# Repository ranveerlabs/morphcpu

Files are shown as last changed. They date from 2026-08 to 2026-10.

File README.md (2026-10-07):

# MorphCPU

just came across a cool analogy that like its pretty similar to how a cafe functions kinda, so i renamed the registers to stuff according to that. i feel like i did a good job haha

anyways MorphCPU is a small processor built from 16 configurable cells on an iCE40UP5K.
The FPGA is on the back of a 70 mm round board, with 16 red LEDs on the front.
Send it 9 bytes over USB and the grid changes what it computes.

MorphCPU board front

MorphCPU schematic

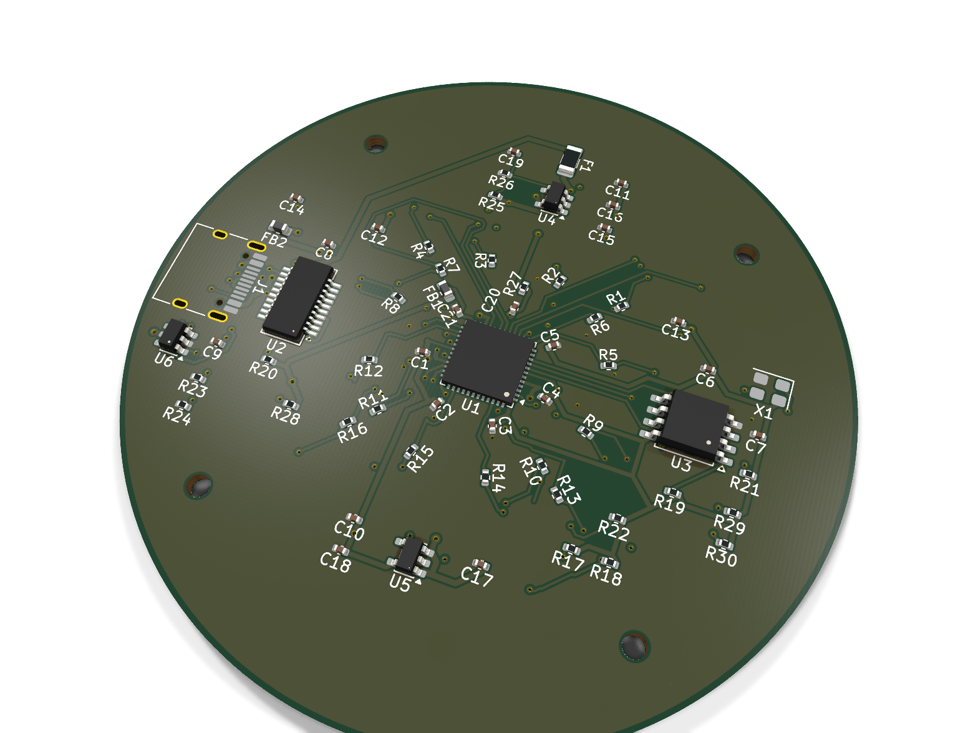
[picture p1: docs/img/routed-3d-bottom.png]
Routed FPGA-side 3D model


If you've poked at a systolic array before, it's close to that. 16 cells, each with an op and a direction. Data walks in from the west and leaves at the east edge over UART. One tick moves it one cell.

It's Verilog for the iCE40UP5K. Python tooling generates the schematic and board layout. Yosys and nextpnr do synthesis and place-and-route.

## why

On a conventional processor, most of the datapath is fixed. Here I can configure 16 cells with an op and a direction, so the values take different routes. I run it at 4 Hz. Four cells takes about a second. At 16 MHz there's nothing to look at.

## the grid

Each cell has a 4-bit configuration: a 2-bit operation and a 2-bit output direction. The four operations are pass, invert, 8-bit add, and XOR. Cells can route north, east, south, or west; inputs that meet at a cell can be combined.

```text
        c0    c1    c2    c3
      +-----+-----+-----+-----+
  r0  |  0  |  1  |  2  |  3  |  -> out
      +-----+-----+-----+-----+
  r1  |  4  |  5  |  6  |  7  |  -> out
      +-----+-----+-----+-----+
  r2  |  8  |  9  | 10  | 11  |  -> out
      +-----+-----+-----+-----+
  r3  | 12  | 13  | 14  | 15  |  -> out
      +-----+-----+-----+-----+
         ^
      data in
```

## a tiny example

Set cell 0 to pass south, cell 4 to add and point east, then cells 5-7 to pass east. Inject 200 on row 0 and 100 on row 1. After stepping through the grid, the UART returns `0x2C`: 300 truncated to 8 bits. The full byte sequence and timing are in the [gateware guide](gateware/README.md#worked-example-add-two-numbers-while-they-travel).

## build and test

You need Icarus Verilog for simulation and OSS CAD Suite for the FPGA bitstream.

```sh
bash gateware/sim/run_sims.sh
bash gateware/build.sh
bash case/export.sh
```

The simulation has 18 passing checks. GitHub Actions also runs the simulations and gateware build on changes; see the [workflow](https://github.com/ranveerlabs/morphcpu/actions/workflows/gateware.yml).

## status

The 4-layer PCB is routed: KiCad reports no violations or unconnected items. The latest recorded bitstream build used 2,020 of 5,280 logic cells and routed at 37.33 MHz against a 16 MHz clock. That build predates two pin-map changes, and the board has not been flashed yet, so those timing numbers are not verification of the current layout. Routing details and pin changes are in [hardware/ROUTING.md](hardware/ROUTING.md).

Routed back of the PCB

The board is 70 mm across with a 4×4 LED grid. The case is printable without supports. More board images are in [`docs/img`](docs/img/README.md); the [23-row BOM table](docs/BOM.md#the-parts) and [BOM CSV](hardware/fab_output/morphcpu-bom.csv) list the parts and quantities.

## license

[CERN-OHL-S-2.0](LICENSE). Third-party files retain their own licenses.

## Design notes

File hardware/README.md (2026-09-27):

# hardware/

KiCad project for the 4-layer board. It is placed and routed.

Start with [DESIGN.md](DESIGN.md), then see [ROUTING.md](ROUTING.md) for the
routing details.

| | |
|---|---|
| `morphcpu.kicad_sch` | generated. ERC 0/0 |
| `morphcpu.kicad_pcb` | 80 components + 4 mounting holes, 546 tracks, 193 vias |
| `morphcpu.kicad_dru` | JLC rules Board Setup cant express |
| [scripts/](scripts/) | generators |
| `fab_output/` | gerbers drill BOM CPL zip |

The latest DRC run had 0 violations, 0 unconnected items and 0 schematic
mismatches. LED1 uses FPGA pin 45 and LED2 uses pin 42. The schematic, source
netlist and PCF all agree.

`fab_output/` was generated from the routed board, with copper on all four
layers. The updated pin map still needs a bitstream build. See
[ROUTING.md](ROUTING.md).

## board

The board is round, 70 mm across, with four layers. Four M2 holes sit on a 29 mm
radius at 45, 135, 225 and 315 degrees. The case uses the same positions in
[../case/morphcpu_case.scad](../case/morphcpu_case.scad)

I started at 60 mm, but that didnt leave enough room. There are 79 footprints,
including a QFN-48, SSOP-20, SOIC-8 and edge-mounted USB-C, all packed around the
resistor ring.

## before you touch it

1. There are two regulators. The UP5K needs 1.2 V core and 3.3 V I/O.
2. The 1.2 V rail has to come up before 3.3 V. Both regulators run from 5 V in
   parallel, and an RC delay holds 3.3 V off. That means the 3.3 V regulator
   needs an enable pin, so the AMS1117 doesnt work here.
3. The clock comes from an active oscillator. The iCE40 has no crystal amplifier,
   and the SG48 has no XIN/XOUT pins.

citations in [DESIGN.md](DESIGN.md)

## regenerating

Dont hand-edit `.kicad_sch` or the placement. Regenerating replaces them, though
the routed tracks are kept. The commands are in [scripts/](scripts/).

tracked: `*.kicad_pro` `*.kicad_sch` `*.kicad_pcb` `*.kicad_sym` `*.kicad_mod`
`*.kicad_dru` the fab zip the two CSVs. rest regenerates, see
[../.gitignore](../.gitignore)

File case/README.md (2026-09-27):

# case/

An open-face frame in parametric OpenSCAD. The board sits on four posts and
screws down. There is no lid or cover over the LEDs.

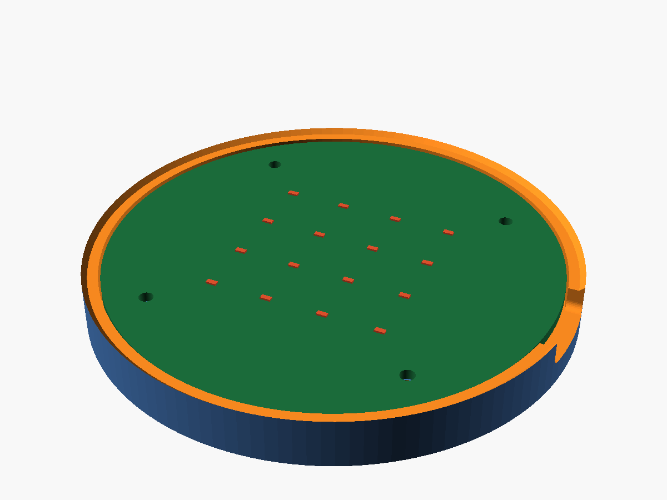
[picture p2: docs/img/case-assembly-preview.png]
case with a mock board in it


It is 75.4 mm across, 7.8 mm tall, with 2.4 mm walls and 3 mm under the board
for back-side parts. The 75.4 mm comes from a 70 mm board, 0.3 mm fit clearance
on each side and the two walls, so it changes if any of those dimensions do.

```sh
./export.sh
OPENSCAD="/c/Program Files/OpenSCAD (Nightly)/openscad.com" ./export.sh   # not on PATH
```

variants without exporting:

```sh
openscad -D 'part="assembly"' morphcpu_case.scad
openscad -D 'part="frame"'    morphcpu_case.scad
openscad -D 'part="pcb"'      morphcpu_case.scad
```

## board dimensions

The PCB hasnt been made yet, so these are assumptions, not measurements.

| param | assumed | comes from |
|---|---|---|
| `pcb_dia` | 70.0 mm | final board outline |
| `pcb_thickness` | 1.6 mm | JLCPCB default stackup |
| `mount_hole_r` | 29.0 mm | bolt circle |
| `mount_hole_count` | 4 | layout |
| `mount_hole_angle_offset` | 45 deg | layout |
| `usb_angle` | 0 deg (+X edge) | where the connector ends up |
| `usb_z_centre` | 1.2 mm above board top | connector datasheet + placement |

Update those seven values after routing, then run `export.sh` again.

## STEP

OpenSCAD wont do it. the CLI does `stl, off, wrl, amf, 3mf, csg, dxf, svg, pdf,
png` and thats the lot, its a mesh modeller and STEP is B-rep

`morphcpu_case.step` is the 3MF pushed thru FreeCAD 1.1.3, `Mesh.insert` then
`makeShapeFromMesh` with sewing then `Part.export`. it comes out a closed solid,
75.4 x 75.4 x 7.8mm, 11627.5mm3, 2621 faces. tessellated though, those faces are
mesh triangles welded up and not real cylinders. fine for a fit check, rebuild it
in Part Design or CadQuery if you need a proper one

## printing

no supports, flat on its back, 0.2mm layers, 3 perimeters. PLA unless it lives
somewhere warm

export prints genus 12 every time, four screw holes and eight vents. a
different number after a param change means two features started intersecting

`fit_clearance` is 0.3mm. print a test ring first, mine came out tight

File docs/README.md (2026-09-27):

# docs/

[BOM.md](BOM.md) lists the parts and cost for five boards. All 23 rows have an
LCSC part number. [img/](img/) has the renders and screenshots.

The machine-readable BOM and CPL are in
[../hardware/fab_output/](../hardware/fab_output/). `gen_fab.py` exports those
along with the Gerbers, all from the board file.

## datasheets

- [iCE40 UltraPlus, FPGA-DS-02008](https://www.latticesemi.com/-/media/LatticeSemi/Documents/DataSheets/iCE/iCE40-UltraPlus-Family-Data-Sheet.ashx) - pin summary p.45, Table 4.2 p.29, Table 4.13 p.34, power-up 4.5 p.31
- iCE40 Programming and Configuration, FPGA-TN-02001
- FTDI FT231X
- [W25Q32JV](https://www.winbond.com/hq/product/code-storage-flash-memory/serial-nor-flash/?__locale=en)
- USB-C mech drawing and the Type-C spec for the CC pulldowns. 5.1k each never shared
- [JLCPCB parts](https://jlcpcb.com/parts) - tier listings. part pages render the badge in JS

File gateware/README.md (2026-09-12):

# gateware/

Verilog, targets iCE40UP5K-SG48

| | |
|---|---|
| [rtl/morph_cell.v](rtl/morph_cell.v) | one cell: config register, 4-op ALU, routing |
| [rtl/grid.v](rtl/grid.v) | the 4x4 fabric and the neighbour interconnect |
| [rtl/uart_rx.v](rtl/uart_rx.v) | 8N1 receiver, synchronised, checks the stop bit |
| [rtl/uart_tx.v](rtl/uart_tx.v) | 8N1 transmitter |
| [rtl/config_loader.v](rtl/config_loader.v) | command decoder, config shifter, tick generator |
| [rtl/morphcpu_top.v](rtl/morphcpu_top.v) | top level: clock, reset, UART, LEDs |
| [morphcpu.pcf](morphcpu.pcf) | pin constraints |
| [build.sh](build.sh) | yosys -> nextpnr -> icepack |
| [sim/](sim/) | testbenches |

its `morph_cell` not `cell` cuz `cell` is reserved in Verilog-2001, it belongs
to the `config`/`design` construct. iverilog does not tell you this nicely

## cells

4 config bits, an op and a direction

| `op` | Operation | Result |
|---|---|---|
| `0` | PASS | `a` |
| `1` | INV | `~a` |
| `2` | ADD | `a + b` (8-bit, wraps) |
| `3` | XOR | `a ^ b` |

| `dir` | Sends its result |
|---|---|
| `0` | north |
| `1` | east |
| `2` | south |
| `3` | west |

inputs get scanned in a fixed priority order, N then E then S then W. first
valid one is `a`, second valid one is `b`. only one input showed up, `b` falls
back to whatever the cell is already holding

so two streams converging on a cell get combined and a lone stream walking thru
an ADD cell accumulates against itself

one `tick` moves data exactly one cell, so a value takes as many ticks as there
are cells on its path

## grid and edges

```
        c0    c1    c2    c3
      +-----+-----+-----+-----+
  r0  |  0  |  1  |  2  |  3  |  -> east_out[0]
      +-----+-----+-----+-----+
  r1  |  4  |  5  |  6  |  7  |  -> east_out[1]
      +-----+-----+-----+-----+
  r2  |  8  |  9  | 10  | 11  |  -> east_out[2]
      +-----+-----+-----+-----+
  r3  | 12  | 13  | 14  | 15  |  -> east_out[3]
      +-----+-----+-----+-----+
         ^
     west_in[r] injects into column 0
```

anything routed off the north, south or west edges is dropped. anything going
east out of column 3 leaves the fabric and goes back to the host over UART.
`led[i]` follows cell `i`

## host protocol

8N1 UART, 115200 baud, thru the FT231X. one command byte then a fixed number of
argument bytes

| Cmd | Name | Args | Effect |
|---|---|---|---|
| `0x01` | CONFIG | 8 | load the whole topology, packing below |
| `0x02` | INJECT | 2 | `[row, value]`, presents `value` at the west edge of `row` until the next tick |
| `0x03` | TICKDIV | 3 | 24-bit big-endian tick divider. `<=1` runs at full clock rate |
| `0x04` | CLEAR | 0 | drop all in-flight data, config survives |
| `0x05` | STEP | 0 | advance exactly one tick |

unknown command bytes get ignored, so recovering from a half-sent command is
just: send `0x04`, carry on

results leaving the east edge come back as single bytes, lowest row first

### config packing

the 8 CONFIG bytes are one nibble per cell, ascending cell order:

```
byte i, upper nibble -> cell (2i)
byte i, lower nibble -> cell (2i + 1)
nibble = {op[1:0], dir[1:0]}
```

so a straight PASS chain along row 0, cells 0-3 all PASS/EAST, nibble `0x1`:

```
01 11 11 00 00 00 00 00 00
^  ^^^^^ cells 0-3         cells 4-15 idle
CONFIG
```

the chain is wired highest-cell-index-first inside the fabric on purpose, so the
host sends cells in plain ascending order and never has to reverse anything

### worked example: add two numbers while they travel

route cell 0 south into cell 4, make cell 4 an adder, run east to the edge

| Cell | op | dir | nibble |
|---|---|---|---|
| 0 | PASS | S | `0x2` |
| 4 | ADD | E | `0x9` |
| 5, 6, 7 | PASS | E | `0x1` |

```
01 20 00 91 11 00 00 00 00     CONFIG
02 00 C8                       INJECT row 0, 200
05                             STEP   (200 in cell 0 now, pointed south)
02 01 64                       INJECT row 1, 100
05                             STEP   (cell 4 adds north + west -> 44)
05 05 05                       STEP x3 (across cells 5, 6, 7)
                               -> board sends 0x2C (300 truncated to 8 bits)
```

that exchange is exactly what `sim/tb_morphcpu_top.v` asserts, byte for byte

## simulation

Icarus Verilog only, no vendor tools

```sh
cd gateware/sim
./run_sims.sh
```

18/18 passing.

| Testbench | Covers |
|---|---|
| [sim/tb_grid.v](sim/tb_grid.v) | fabric: per-tick latency, all four ops, convergence, activity taps |
| [sim/tb_morphcpu_top.v](sim/tb_morphcpu_top.v) | end to end over the real UART protocol |

`tb_grid` drives the config chain directly. `tb_morphcpu_top` goes in thru the
UART and never reaches into the hierarchy so it covers the wire protocol and the
config bit ordering too

waveforms:

```sh
cd gateware/sim/out
gtkwave tb_grid.vcd
```

## building a bitstream

needs the [OSS CAD Suite](https://github.com/YosysHQ/oss-cad-suite-build/releases)
(yosys, nextpnr-ice40, icepack, iceprog) on `PATH`

```sh
cd gateware
./build.sh
./build.sh prog
./build.sh clean
```

plain `build.sh` synthesises, routes and packs. `prog` also flashes the board
with `iceprog`, run that locally with the board connected

what it actually runs:

```sh
yosys -p "read_verilog rtl/*.v; synth_ice40 -top morphcpu_top -json build/morphcpu_top.json"

nextpnr-ice40 --up5k --package sg48 \
    --json build/morphcpu_top.json \
    --pcf morphcpu.pcf \
    --asc build/morphcpu_top.asc \
    --freq 16

icepack build/morphcpu_top.asc build/morphcpu_top.bin

iceprog build/morphcpu_top.bin
```

greps the nextpnr log for utilisation and Fmax at the end

[Actions](https://github.com/ranveerlabs/morphcpu/actions/workflows/gateware.yml)
runs both testbenches and this build on gateware pushes and pull requests.
theres a manual run button too. Ubuntu 24.04, OSS CAD Suite pinned to 2026-09-12,
all 20 I/O pins must be constrained

first [passing build](https://github.com/ranveerlabs/morphcpu/actions/runs/34678840307):

```text
PASS: 13/13 checks
PASS: 5/5 checks
RESULT: all testbenches passed
```

```text
Info: 	         ICESTORM_LC:    2020/   5280    38%
Info: 	        ICESTORM_RAM:       0/     30     0%
Info: 	               SB_IO:      20/     39    51%
Info: 	               SB_GB:       6/      8    75%
Info: Max frequency for clock 'clk$SB_IO_IN_$glb_clk': 37.33 MHz (PASS at 16.00 MHz)
```

thats the final routed timing estimate, no hardware measurement yet.
`morphcpu_top.bin` is 104090 bytes. download the `gateware-<commit>` artifact
from a passing run, it includes the bitstream, netlist and logs. artifacts stay
for 30 days, failed runs keep whatever logs were written

`morphcpu.pcf` agrees with the
[user I/O assignment](../hardware/DESIGN.md#user-io-assignment) in DESIGN.md,
all 20 pins, i checked. they can drift, DESIGN.md wins

## demo notes

tick defaults to 4 Hz. a hop every 62.5 ns is invisible. LEDs are pulse
stretched to ~150 ms so a single-tick visit still reads

at full tick rate the fabric outruns 115200 baud and east-edge results get
dropped. use `STEP` or a slow `TICKDIV` if you want all of them

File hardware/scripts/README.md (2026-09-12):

# hardware/scripts/

generators for the KiCad project. the schematic and the placement are both
produced from source instead of drawn by hand, so the netlist has exactly one
authority and regenerating costs nothing

| File | What it does |
|---|---|
| [netlist.py](netlist.py) | the netlist, transcribed from [../DESIGN.md](../DESIGN.md). every connection maps to a row in a DESIGN.md table |
| [ksym.py](ksym.py) | small KiCad s-expression reader/writer + symbol pin extractor |
| [gen_schematic.py](gen_schematic.py) | emits `../morphcpu.kicad_sch` |
| [gen_pcb.py](gen_pcb.py) | emits `../morphcpu.kicad_pcb`, outline + placement, no routing |
| [gen_fab.py](gen_fab.py) | emits `../fab_output/`: gerbers, drill, JLC BOM and CPL, zip |

## running

use KiCad's bundled python, nothing extra to install:

```sh
KP="/c/Users/ranve/AppData/Local/Programs/KiCad/10.0/bin/python.exe"
"$KP" hardware/scripts/gen_schematic.py
```

then check it:

```sh
CLI="/c/Users/ranve/AppData/Local/Programs/KiCad/10.0/bin/kicad-cli.exe"
"$CLI" sch erc --output erc.rpt --severity-all --exit-code-violations hardware/morphcpu.kicad_sch
"$CLI" sch export netlist --output morphcpu.net hardware/morphcpu.kicad_sch
```

regenerating the PCB blows away hand routing. placement is generated, tracks
arent. the board is routed now so dont run `gen_pcb.py` on it without a copy of
the routed file somewhere safe

## fab output

```sh
"$KP" hardware/scripts/gen_fab.py
```

writes `../fab_output/`: `morphcpu-gerbers.zip` (the file JLC's uploader wants),
`morphcpu-bom.csv`, `morphcpu-cpl.csv`, and a `gerbers/` dir with the loose
plots. the loose plots arent tracked, the zip and the two CSVs are, and the
loose files regenerate.

the LCSC column comes from a table inside `gen_fab.py` transcribed out of
[../../docs/BOM.md](../../docs/BOM.md). any row BOM.md hasnt pinned gets an empty
LCSC field, never a guess, and the script lists them on stderr when it finishes.
right now all 22 are pinned so it should print nothing

gerbers, drill and CPL are all plotted in absolute coordinates. the board sets no
aux axis origin so the drill/place origin and the page origin are the same point
and all three files share one coordinate system. if an aux origin ever gets
added, all three exports have to switch to `--use-drill-file-origin` together, or
the CPL ends up offset from the copper and you find out at assembly

## why global labels instead of drawn wires

connectivity is expressed with global labels, not wire segments. a global label
joins nets by name, so every pin carrying the same net name is connected no
matter where its symbol sits

drawing wires programmatically means computing polylines between pin endpoints
and trusting they land exactly on them, and a wire that stops 0.01 mm short looks
connected and isnt. labels delete that, ERC plus the exported netlist confirm the
result

## gotchas found the hard way

- derived symbols have to be embedded flattened. `ME6211C12M5` only extends
  `ME6211C33M5`, and emitting the parent body under the child's name loads fine
  but trips ERC `lib_symbol_mismatch` cuz the properties still read as the
  parent. the nested per-unit sub-symbols have to be renamed to the child too or
  the file wont load at all, `kicad-cli` says "Failed to load schematic" and
  nothing else which is not much to go on
- references need a trailing digit, `C_EN` reads as unannotated and `C19` doesnt
- symbol origins belong on the 1.27 mm grid. pin offsets are multiples of 1.27 so
  an off-grid origin puts every single pin off-grid
- unit 0 pins apply to all units. look pins up in the requested unit first, then
  fall back to unit 0
- `board.Add(fp)` before `fp.Flip()`. pcbnew segfaults with no traceback if you
  flip a footprint that isnt on the board yet, the bindings dont check ownership
- `SaveBoard` rewrites `morphcpu.kicad_pro` from the board defaults and wipes
  every net class and DRC minimum. `gen_pcb.py` saves them first and puts them back

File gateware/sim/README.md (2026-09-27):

# gateware/sim/

These simulations only need Icarus Verilog, not the FPGA vendor tools.

```sh
./run_sims.sh
```

what that prints, tail end of it:

```
  ok  tick 4 -> only cell 3 lit

PASS: 13/13 checks

tb_grid.v:252: $finish called at 4040000 (1ps)
  tb_grid OK

==============================================================
  tb_morphcpu_top
==============================================================
VCD info: dumpfile tb_morphcpu_top.vcd opened for output.
TEST 1: PASS chain across row 0, driven entirely over UART
  ok  PASS chain result over UART -> 0xa5
TEST 2: INV in the chain
  ok  INV chain result over UART -> 0x5a
TEST 3: ADD convergence across two rows
  ok  ADD convergence result over UART -> 0x2c
TEST 4: LEDs track fabric activity
  ok  all LEDs dark after CLEAR
  ok  led[0] lit while cell 0 holds the value

PASS: 5/5 checks

tb_morphcpu_top.v:228: $finish called at 7044773750 (1ps)
  tb_morphcpu_top OK

RESULT: all testbenches passed
```

There are 13 fabric checks and 5 top-level checks. [tb_grid.v](tb_grid.v) drives
the config chain directly, so it only tests the fabric.
[tb_morphcpu_top.v](tb_morphcpu_top.v) sends data through the UART without
reaching into the design hierarchy. That also checks the wire protocol and bit
ordering, so if only this testbench breaks, the UART path is a good place to look.

run one by hand:

```sh
iverilog -g2005 -Wall -o out/tb_grid.vvp -s tb_grid ../rtl/*.v tb_grid.v
(cd out && vvp tb_grid.vvp)
```

waveforms:

```sh
cd out
gtkwave tb_grid.vcd
```

`out/` and `*.vcd` / `*.fst` files are gitignored. Commit the testbench, not the
waveform dump.

## pictures out of the dump

[vcd_png.js](vcd_png.js) turns a dump into a png of the activity taps, one row
per cell, one column per tick. no deps, node only

```sh
node vcd_png.js out/tb_grid.vcd ../../docs/img/sim-002-grid-activity.png
```

As a value moves across the fabric, it leaves a diagonal streak, one cell per
tick. A routing bug changes the slope. The top-level dump has no `tick` in scope,
so it samples on LED changes instead. Since the LEDs are pulse-stretched, that
plot looks like a filled triangle rather than a diagonal.

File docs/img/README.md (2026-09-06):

# docs/img/

renders, screenshots and build photos

| File | What |
|---|---|
| `case-frame-preview.png` | the printable case on its own |
| `case-assembly-preview.png` | case with a mock board dropped in |
| `pcb-placement-front.png` | board front, the 4x4 led grid |
| `pcb-placement-back.png` | board back, everything else |
| `pcb-3d.png` | 3d render, top |
| `case-pcb-assembly.png` | case with the real routed board seated in it |
| `routed-3d-top.png` | 3d render of the routed board, top |
| `routed-3d-bottom.png` | 3d render of the routed board, bottom, the fpga side |
| `pcb-top.svg` | F.Cu + silk + mask + outline, top view |
| `schematic.svg` | the whole schematic on one sheet |
| `pcb-3d-back.png` | 3d render, bottom |
| `sim-002-grid-activity.png` | activity taps over 28 ticks, from the fabric sim |
| `sim-003-uart-activity.png` | led states through the end to end run |
| `session-013-decoupling-close.png` | the fpga and its decoupling caps, bottom view |

case renders come out of `case/export.sh`. board renders out of
`kicad-cli pcb render`. the two sim rasters out of
[../../gateware/sim/vcd_png.js](../../gateware/sim/vcd_png.js), which reads the
dump directly so they regenerate off a real run instead of being screenshots of
one

naming for anything new, `session-NNN-<short-description>.png`. referenced from
[../../JOURNAL.md](../../JOURNAL.md)

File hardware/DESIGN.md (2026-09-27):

# MorphCPU board design

The schematic passes ERC. The board is placed and routed on four layers.

The datasheet references are to FPGA-DS-02008-2.0, the iCE40 UltraPlus Family
Data Sheet (Lattice, 2018-2021). I checked most prices and stock on 20 Aug 2026,
then added the passive parts on 23 Aug.

The board hasnt been tested on a bench. The 28 °C rise is calculated, the ~200 µs
rail-up time is inferred rather than measured, and the LED brightness comes from
a curve at a different current. I havent scoped the RC delay either. The earlier
pin map built at 37.33 MHz, but the latest LED1/LED2 assignments still need a
fresh build.

---

## power and clock

### regulator voltages

USB-C gives you 5 V. the iCE40UP5K needs 1.2 V core (VCC, pins 5 and 30) and
3.3 V I/O (VCCIO_0/1/2) and runs on neither, so two regulators

### clock source

a passive crystal needs an amplifier to start it and the iCE40 doesnt have one.
the family gives you `SB_HFOSC` (48 MHz, ÷1/2/4/8) and `SB_LFOSC` (10 kHz) and
thats the lot. no XIN/XOUT pair on SG48 either, all 48 pins are accounted for as
I/O, supply or configuration

the internal oscillator wont do, its roughly ±10% untrimmed and 115200 baud
tolerates abt ±2-3% total

so its an active oscillator module. the pin table in the
[FPGA pinout](#fpga-pinout-ice40up5k-sg48i) section has it

### supply order

I caught the supply-order problem while checking the VCCPLL voltage. It meant
changing the 3.3 V regulator too.

FPGA-DS-02008 §4.5 Power-up Supply Sequence (p.31) requires:

> 1. VCC and VCCPLL should be the first two supplies to be applied.
> 2. SPI_VCCIO1 should be the next supply, and can be applied any time after
>    the previous supplies (VCC and VCCPLL) have reached a level of 0.5 V or higher.
> 3. VPP_2V5 should be the next supply […]
> 4. Other Supplies (VCCIO0 and VCCIO2) […] can be applied any time after the
>    initial power supplies (VCC and VCCPLL) have reached a level of 0.5 V or greater.

§4.4 adds that only VCC, SPI_VCCIO1 and VPP_2V5 are monitored by the on-chip
power-on-reset

The original tree was `5 V -> 3.3 V -> 1.2 V`. That brings 3.3 V up first and
1.2 V last, so SPI_VCCIO1 and VPP_2V5 would be applied before VCC reached 0.5 V.

SPI_VCCIO1, VPP_2V5, VCCIO_0 and VCCIO_2 all use the same 3.3 V rail. The rule
for this board is:

> 1.2 V must reach 0.5 V before 3.3 V is applied.

Both regulators now feed from 5 V in parallel. An RC delay on the 3.3 V
regulator's enable holds that rail off until 1.2 V is up. That needs an enable
pin, which the SOT-223 AMS1117-3.3 doesnt have, so I changed it to AP2112K-3.3TRG1.

Running 1.2 V straight from 5 V costs about 114 mW at 30 mA, or a calculated
28 °C rise in the SOT-23-5 regulator.

---

## oscillator choice

I picked the 16 MHz 1532H4-16000JWPDTSNL (C5383161) because LCSC only had nine
of the 12 MHz active oscillator in stock. I compared three parts and checked
their prices and stock on 20 Aug 2026:

| MPN | LCSC | Freq | Pkg | Price @1 | Stock |
|---|---|---|---|---|---|
| 1575H-12.000G33DTSTL | [C7503622](https://www.lcsc.com/product-detail/C7503622.html) | 12 MHz | SMD7050-4P | $0.87 | 9 |
| 1532H4-16000JWPDTSNL | [C5383161](https://www.lcsc.com/product-detail/C5383161.html) | 16 MHz | SMD3225-4P | $0.36 | 147 |
| ECS-TXO-3225-120-TR | [C2451123](https://www.lcsc.com/product-detail/C2451123.html) | 12 MHz TCXO | SMD3225-4P | $5.94 | 1 |

The TCXO had one in stock and cost 16 times as much for ±2.5 ppm accuracy this
board doesnt need. The 12 MHz part would have avoided a clock change, but nine
in stock felt like a supply risk. The 16 MHz part was cheaper and smaller, so I
changed the clock instead.

the first two are both confirmed active oscillators, not crystals. each one
specifies a supply voltage (A: 2.5-3.3 V, B: 1.8-3.3 V), a supply current, an
HCMOS output and a tri-state enable on pad 1, and a passive crystal has none of
those. plenty of 4-pad 3225 parts at 12 MHz are crystals and got thrown out.
`X322512MSB4SI` (C9002) quotes a 20 pF load capacitance and only a passive
resonator has one of those, so check the load capacitance field

Nothing depended on 12 MHz specifically. I changed `CLK_HZ = 16_000_000` in
`morphcpu_top.v`, `--freq 16` in `build.sh`, `DEFAULT_TICKDIV` 3,000,000 ->
4,000,000 to hold the tick at 4 Hz, and a comment in the pcf. all applied, both
testbenches still pass 18/18

The UART divisor is 16e6 / 115200 = 138.89 -> 139. That drops the error from
0.16% at 12 MHz to 0.08%, a side effect I only noticed afterwards.

---

## power tree

```
USB-C VBUS 5V
   |
   +-- polyfuse 500 mA -- ESD array
   |
   +--> ME6211C12M5G-N (SOT-23-5)  CE tied to VIN, always on
   |         |
   |         +--> +1V2 --> FPGA VCC       (pins 5, 30)
   |         |         --> FPGA VCCPLL    (pin 29) via RC filter
   |         |
   |         +--> (rail is up within ~200 us of VBUS)
   |
   +--> AP2112K-3.3TRG1 (SOT-23-5) EN via RC delay from 5V  <-- holds 3V3 off
   |         |                                                  until 1V2 is up
   |         +--> +3V3 --> FPGA VCCIO_0    (pin 33)
   |                   --> FPGA SPI_VCCIO1 (pin 22)
   |                   --> FPGA VCCIO_2    (pin 1)
   |                   --> FPGA VPP_2V5    (pin 24) via ferrite
   |                   --> SPI config flash
   |                   --> 16 MHz XO
   |                   --> 16 LEDs via resistors
   |
   +--> FT231XS-R VCC (5 V part with its own internal 3V3 LDO)
```

### rails

| Rail | Voltage | Regulator | Feeds | Est. current |
|---|---|---|---|---|
| VBUS | 5.0 V | - | Both regulators, FT231X | ~250 mA worst case |
| +1V2 | 1.2 V | ME6211C12M5G-N, [C236672](https://www.lcsc.com/product-detail/C236672.html) | VCC ×2, VCCPLL | 10-30 mA |
| +3V3 | 3.3 V | AP2112K-3.3TRG1, [C51118](https://www.lcsc.com/product-detail/C51118.html) | VCCIO ×3, VPP_2V5, flash, XO, LEDs | ~110 mA (80 mA of it LEDs) |

both regulators are SOT-23-5 out of the same family so they share a footprint

| Part | Vout | Iout | Vin | CE | Price @1 | Stock |
|---|---|---|---|---|---|---|
| AP2112K-3.3TRG1 | 3.3 V | 600 mA | up to 6.0 V | yes | $0.0967 | 70,670 |
| ME6211C12M5G-N | 1.2 V | 300 mA | 1.2-6.0 V | yes | $0.0606 | 28,080 |

### sequencing RC

The 3.3 V regulator's EN has 100 kΩ to VBUS, 100 nF to GND and a 1 MΩ bleed.
It settles at 5 × 1M/1.1M = 4.55 V. The time constant is (100 kΩ || 1 MΩ) ×
100 nF = 9.1 ms. The 1.2 V regulator starts within hundreds of microseconds of
VBUS, so VCC is past 0.5 V before the 3.3 V regulator turns on.

The bleed matters on power-down too. Without it, EN doesnt discharge and a fast
power cycle can skip the sequence. Section 4.5 requires the sequence each time
the supplies turn on.

I had 10 kΩ there before. Against the 100 kΩ feed, that held EN at 0.45 V, so
the 3.3 V rail wouldnt come up. The time constant was 0.9 ms too. I had also
written 10 ms by multiplying 100 kΩ by 100 nF and leaving the bleed out. I
caught both errors on another datasheet read. This still needs a bench check.

### VPP_2V5

Table 4.2 gives VPP_2V5 as 2.30-3.46 V in Master SPI mode, which is what this
board uses with its external flash. The 3.3 V rail sits inside that range.

Note 4 allows 1.8 V only in Slave SPI mode, with HFOSC/LFOSC and the RGB driver
unused. That doesnt apply here.

I put it through a ferrite with its own 100 nF cap. That rail can be lifted
during bring-up if configuration starts acting up.

### VCCPLL

I had VCCPLL on the 3.3 V rail in an earlier revision. That was wrong: Table 4.2
puts it at 1.14-1.26 V, the core-voltage range. Note 1 says VCC and VCCPLL use
the same supply, with an RC filter on VCCPLL.

I run +1V2 through 100 Ω to pin 29, then put 100 nF to GND at the pin. That gives
a 10 µs time constant. There isnt a PLL in this design, but the pin still needs
power. Section 4.2 says every supply pin must be connected, including during
configuration.

---

## FPGA pinout (iCE40UP5K-SG48I)

This is the complete SG48 pin assignment. Pin numbers come from the KiCad 10
symbol `ICE40UP5K-SG48ITR` in `FPGA_Lattice.kicad_sym`. The counts match
FPGA-DS-02008 §5.2 (2 × VCC, 3 × VCCIO, 1 × VCCPLL, 1 × VPP_2V5, 2 dedicated
config, 39 GPIO and no dedicated GND pin, 48 total).

### supply and configuration pins

| Pin | Name | Net | Notes |
|---|---|---|---|
| 5 | VCC | +1V2 | Core |
| 30 | VCC | +1V2 | Core |
| 29 | VCCPLL | +1V2 | Via 100 Ω RC filter |
| 33 | VCCIO_0 | +3V3 | Bank 0 |
| 22 | SPI_VCCIO1 | +3V3 | Bank 1, powers the SPI config pins, POR-monitored |
| 1 | VCCIO_2 | +3V3 | Bank 2 |
| 24 | VPP_2V5 | +3V3 | Via ferrite |
| 49 | GND (paddle) | GND | the only ground connection, see below |
| 8 | CRESET_B | - | 10 kΩ to +3V3, test point |
| 7 | CDONE | - | 10 kΩ to +3V3, plus an LED |
| 14 | SPI_SO (IOB_32a) | FLASH_DO | Dedicated config |
| 15 | SPI_SCK (IOB_34a) | FLASH_CLK | Dedicated config |
| 16 | SPI_SS (IOB_35b) | FLASH_CS | Dedicated config, 10 kΩ pull-up |
| 17 | SPI_SI (IOB_33b) | FLASH_DI | Dedicated config |
| 39 | RGB0 | no connect | Constant-current LED driver, not ordinary I/O |
| 40 | RGB1 | no connect | " |
| 41 | RGB2 | no connect | " |

> theres no dedicated ground pin on SG48, ground reaches the die only thru the
> exposed paddle. FPGA-DS-02008 p.45 note: "48-pin QFN package (SG48) requires
> the package paddle to be connected to GND." a badly soldered paddle leaves the
> die with no ground connection at all

pins 39, 40, 41 are the `SB_RGBA_DRV` open-drain constant-current driver outputs,
left unused on purpose, the 16-LED grid wants plain LVCMOS I/O and these behave
differently

### global-clock-capable pins

| Pin | Name | Buffer |
|---|---|---|
| 35 | IOT_46b_G0 | GBUF0 |
| 37 | IOT_45a_G1 | GBUF1 |
| 20 | IOB_25b_G3 | GBUF3 |
| 44 | IOB_3b_G6 | GBUF6 |

The oscillator goes to pin 35. Sending a 12 or 16 MHz clock through general
fabric instead of a global buffer would make timing closure harder.

### user I/O assignment

| Pin | Symbol name | Net |
|---|---|---|
| 35 | IOT_46b_G0 | CLK (from XO) |
| 10 | IOB_18a | RST_N (button) |
| 34 | IOT_44b | UART_TX_O (to FT231X RXD) |
| 36 | IOT_48b | UART_RX_I (from FT231X TXD) |
| 2 | IOB_6a | LED0 |
| 45 | IOB_5b | LED1 |
| 42 | IOT_51a | LED2 |
| 27 | IOT_38b | LED3 |
| 12 | IOB_22a | LED4 |
| 13 | IOB_24a | LED5 |
| 18 | IOB_31b | LED6 |
| 19 | IOB_29b | LED7 |
| 21 | IOB_23b | LED8 |
| 9 | IOB_16a | LED9 |
| 25 | IOT_36b | LED10 |
| 26 | IOT_39a | LED11 |
| 48 | IOB_4a | LED12 |
| 46 | IOB_0a | LED13 |
| 38 | IOT_50b | LED14 |
| 32 | IOT_43a | LED15 |

I checked the assignment for a few things:

- no LED on a dedicated config pin (14-17), on CRESET_B (8) or CDONE (7)
- no LED on an RGB driver pin (39-41)
- clock is on a GBIN pin (35)
- pin 20 (G3) left free instead of spent on an LED, so theres a second global
  clock if it ever matters
- LEDs split across banks, 2, 45, 46, 48 on VCCIO_2 (pin 1), 9, 12, 13, 18, 19, 21
  on VCCIO_1 (pin 22) and 25, 26, 27, 32, 38, 42 on VCCIO_0 (pin 33), so 80 mA
  isnt pulled thru one VCCIO pin, 20 / 30 / 30 mA. all three VCCIO pins are +3V3
- LED1 moved from 3 to 45 and LED2 from 23 to 42 in the final routing cleanup.
  both stay in their original banks and use ordinary I/O pins. the south escapes
  close the last two connections without moving the resistor ring
- six LEDs moved off their first-pass pins during routing, LED12 -> 48,
  LED13 -> 46, LED14 -> 38 and LED9 -> 9, LED2 -> 23, LED3 -> 27. all six were
  crossing the package to reach a resistor on the far side, and U1's east column
  was running twelve nets out of twelve 0.5 mm channels, so +3V3 (22, 33), +1V2
  (5, 30) and LED12 had no escape at all. the south row, pads 37-48, was sitting
  entirely unused. bank assignments and the rest of it are in
  [ROUTING.md](ROUTING.md#the-fanout-ran-out-of-room-so-six-pins-moved)
- the UART sits on 34/36 in bank 0, not 6/9 in the config bank. same +3V3 VCCIO
  either way, costs no LED pin and no GBIN pin, and it puts both nets on the face
  that looks at the FT231X instead of the face opposite it.
  [ROUTING.md](ROUTING.md#10-uart_tx_o-and-uart_rx_i) has the measurement

`gateware/morphcpu.pcf` matches this table pin for pin. Update both if you move
one.

### decoupling, exact count

There are seven supply pins, so each gets a 100 nF cap on the same side, with a
via straight to the plane:

| Pin | Rail | Ceramic | Bulk |
|---|---|---|---|
| 5 | +1V2 VCC | 100 nF | share 10 µF |
| 30 | +1V2 VCC | 100 nF | share 10 µF |
| 29 | +1V2 VCCPLL | 100 nF | behind 100 Ω |
| 33 | +3V3 VCCIO_0 | 100 nF | share 4.7 µF |
| 22 | +3V3 SPI_VCCIO1 | 100 nF | 4.7 µF, keep this bank clean, it is POR-monitored |
| 1 | +3V3 VCCIO_2 | 100 nF | share 4.7 µF |
| 24 | +3V3 VPP_2V5 | 100 nF | behind ferrite |

The other caps are 100 nF at the flash and XO, 100 nF + 4.7 µF at both FT231X
VCC and 3V3OUT, plus 1 µF on each ME6211 input and output. That's the datasheet
minimum. I also put 10 µF on the 1.2 V output.

That makes eleven 100 nF caps total. The BOM now matches the count instead of
the old rough estimate of 10-14.

---

## connections

### FT231XS-R, no pinout change

I checked the FT231XS-U to FT231XS-R swap against every assigned pin. The
pinout stays the same.

| | FT231XS-U | FT231XS-R |
|---|---|---|
| LCSC | [C89607](https://www.lcsc.com/product-detail/C89607.html) | [C132160](https://www.lcsc.com/product-detail/C132160.html) |
| Package (per LCSC) | SSOP-20-150mil | SSOP-20-150mil |
| Stock | 0, out of stock | 1,657 |
| Price @1 | $4.47 | $5.9542 |

`FT231XS` is the SSOP-20 die and package. the trailing `-U` / `-R` is FTDI's
packaging suffix, `-U` is tube and `-R` is tape-and-reel, and both LCSC entries
independently report the same SSOP-20-150mil footprint. the QFN variant is a
different base part number (`FT231XQ`) and isnt in play

tape-and-reel is what an SMT line wants anyway. abt $1.50/unit more

| FT231X pin | Net | Notes |
|---|---|---|
| VCC | VBUS (5 V) | Via ferrite from VBUS |
| 3V3OUT | FT_3V3 | Internal LDO output, 100 nF + 4.7 µF, do not load externally |
| VCCIO | FT_3V3 | Sets UART levels to 3.3 V |
| USBDP | USB_DP_F | Downstream side of the ESD array, see below |
| USBDM | USB_DM_F | Downstream side of the ESD array, see below |
| TXD | FPGA pin 36 (UART_RX_I) | Bridge transmits, FPGA receives |
| RXD | FPGA pin 34 (UART_TX_O) | |
| RESET# | 10 kΩ to VCC | |
| GND / AGND | GND | |
| CBUS0 / CBUS1 | optional LEDs | Default TXLED# / RXLED#, useful during bring-up |

direction is the classic trap, TXD on the bridge goes to the FPGA's RX

### USB-C receptacle (16-pin, sink only)

| Pin | Net | Notes |
|---|---|---|
| VBUS (A4/A9/B4/B9) | VBUS | Tie all four together |
| GND (A1/A12/B1/B12) | GND | Tie all four together |
| D+ (A6/B6) | USB_DP | Tie both together, USB 2.0 device |
| D- (A7/B7) | USB_DM | Tie both together |
| CC1 (A5) | 5.1 kΩ to GND | Required, advertises a sink |
| CC2 (B5) | 5.1 kΩ to GND | separate resistor, not shared with CC1 |
| SBU1 / SBU2 | no connect | |

CC1 and CC2 each need their own 5.1 kΩ resistor. If you share one or use 10 kΩ,
some hosts and chargers wont power the board.

### ESD protection, USBLC6-2SC6 ([C7519](https://www.lcsc.com/product-detail/C7519.html)), SOT-23-6

U6, between the receptacle and the bridge. the USB-C port is the only bit of this
board anyone touches while its live and the FT231X data pins are the only thing
sitting behind it

| U6 pin | Name | Net | Notes |
|---|---|---|---|
| 1 | I/O1 | USB_DM | From J1 A7/B7 |
| 2 | GND | GND | |
| 3 | I/O2 | USB_DP | From J1 A6/B6 |
| 4 | I/O2 | USB_DP_F | To FT231X USBDP |
| 5 | VBUS | VBUS | Clamps the 5 V rail too |
| 6 | I/O1 | USB_DM_F | To FT231X USBDM |

pins 1/6 are the two ends of one protected line, 3/4 the other, each pair shorted
inside the package. giving each end its own net name is deliberate, it forces the
trace thru the part instead of stubbing off it

3.5 pF max line capacitance, irrelevant at full speed and still fine at high
speed. IEC 61000-4-2 level 4

U6 goes beside J1 on the back, abt 5 mm from the connector's D+/D- pads, cuz
protection downstream of a long trace only protects the trace. the direct line
between U2 and J1 is a 1.2 mm gap, too narrow for SOT-23-6, and the front face is
the LED display, so 5 mm is the best this placement allows. if routing says thats
too long, shift U2 west and reopen the centre channel, dont move the clamp
further out

### SPI configuration flash, W25Q32JVSSIQ ([C179173](https://www.lcsc.com/product-detail/C179173.html))

| Flash pin | FPGA pin | Net |
|---|---|---|
| CS# | 16 (SPI_SS) | FLASH_CS, 10 kΩ pull-up to +3V3 |
| CLK | 15 (SPI_SCK) | FLASH_CLK |
| DI (IO0) | 17 (SPI_SI) | FLASH_DI |
| DO (IO1) | 14 (SPI_SO) | FLASH_DO |
| WP# (IO2) | - | Tie to +3V3, quad mode unused |
| HOLD# (IO3) | - | Tie to +3V3 |
| VCC | - | +3V3, 100 nF local |
| GND | - | GND |

### oscillator: 1532H4-16000JWPDTSNL (LCSC C5383161), SMD3225-4P

| XO pad | Net | Notes |
|---|---|---|
| 1 | OE / tri-state enable | Tie to +3V3 through 10 kΩ to keep the output enabled |
| 2 | GND | |
| 3 | OUT | To FPGA pin 35 (IOT_46b_G0) |
| 4 | VDD | +3V3, 100 nF right at the pad |

the 4-pad arrangement is standard across SMD XOs, this one is 3225
(3.2 x 2.5 mm). pad 1 is a tri-state enable and tying it high thru 10 kΩ keeps
the output on, leaves the option of gating it later

### configuration control

| Net | Treatment |
|---|---|
| CRESET_B (pin 8) | 10 kΩ pull-up to +3V3, plus a test point |
| CDONE (pin 7) | 10 kΩ pull-up to +3V3, plus an LED, lit means configured |
| Reset button | To FPGA pin 10, a user I/O, not CRESET_B |

The button resets the logic but keeps the loaded fabric topology. CRESET_B reloads
the whole bitstream, so I gave it a test point instead of a button.

### LED grid

16 red LEDs, KT-0603R ([C2286](https://www.lcsc.com/product-detail/C2286.html)),
Vf 1.8-2.4 V, laid out as a physical 4×4 matching the fabric map.

```
R = (3.3 V - 2.0 V) / 5 mA = 260 Ω  ->  270 Ω (E24)
```

At 5 mA, the LEDs stay under the 8 mA IOL/IOH limit in Table 4.13. That's about
75 mcd from a part rated 300 mcd at 20 mA, and keeps the grid at 80 mA instead
of 320 mA. If the pins sink current instead, subtract the 0.4 V max VOL and use
200 Ω for the same current.

polarity is a schematic choice and the gateware follows it via `LED_ACTIVE_LOW`
on `morphcpu_top`, so it costs nothing to flip:

| Wiring | Parameter |
|---|---|
| Pin -> resistor -> anode, cathode to GND (pin sources) | `LED_ACTIVE_LOW = 0` (default) |
| +3V3 -> resistor -> anode, cathode -> pin (pin sinks) | `LED_ACTIVE_LOW = 1` |

---

## PCB brief

The board is routed. Net classes, JLC DRC rules and the routing order are in
[ROUTING.md](ROUTING.md), so read that alongside this spec.

| Item | Value |
|---|---|
| Shape | Round, 70 mm diameter (matches `pcb_dia` in [case/morphcpu_case.scad](../case/morphcpu_case.scad)) |
| Layers | 4, 1.6 mm, 1 oz outer - JLCPCB 4 layer stackup |
| Mounting | 4 x M2 on a 58 mm bolt circle (29 mm radius) at 45/135/225/315 deg |
| Min track / clearance | 6 mil / 6 mil |
| Min via | 0.3 mm hole / 0.6 mm pad |

### board size

My first placement pass used a 60 mm board, but 79 footprints wouldnt fit. The
QFN-48, SSOP-20, SOIC-8 and edge-mounted USB-C left no room between the LED
resistor ring and the outer parts. DRC found courtyard overlaps and shorting pads.
The only way to clear them was to put parts over the mounting holes, which isnt
really clearing them.

At 70 mm, there are no courtyard overlaps, shorting pads or clearance violations.
The case is parametric, so I changed `pcb_dia` and `mount_hole_r` and exported it
again.

### placement scheme

The LED grid takes the centre of the front. I put everything else on the back,
in rings around the FPGA:

| Radius | What |
|---|---|
| 0 | FPGA, QFN-48 |
| 6.5 mm | One 100 nF per supply pin - seven of them |
| 9.0 mm | VCCPLL 100R filter and the VPP_2V5 ferrite, just outboard of their caps |
| 11.5 mm | 12 of the LED series resistors, each on its own LED's ray |
| 14.5 mm | The other 4, for the corner LEDs, which share a diagonal with the inner four |
| >= 17 mm | Everything with a real body, on the four cardinal directions |

The diagonals stay clear from r=22 to r=26 for the mounting holes.

The outer parts are grouped by function. USB-C is on the east, with the FT231X
behind it and the USBLC6 beside the connector. The flash and oscillator are on
the west, close to the FPGA to keep SPI and clock runs short. The 3.3 V regulator
and its enable RC are north, the 1.2 V regulator is south.

The 4x4 grid uses a 9 mm pitch and is 27 mm across, matching `led_pitch` in the
case source. Cell 0 is top-left and the order is row-major, same as the fabric
map in [gateware/README.md](../gateware/README.md), so the board matches the demo.

Silkscreen artwork fits in the outer ring past r=20, except around the four
mounting holes and the two front-side parts, SW1 at the top and the CDONE LED at
the bottom.

The paddle is the die's only ground path. It needs a 3x3 or 4x4 group of 0.3 mm
vias into the ground pour. The paste stencil is split into four or five squares
so the FPGA doesnt float during reflow.

The ground pour should be stitched, with no isolated islands.

## JLCPCB assembly notes

| Part | LCSC | Tier | Stock (20 Aug 2026) |
|---|---|---|---|
| ICE40UP5K-SG48I | C2678152 | Extended | 546, lowest in the design, order early |
| FT231XS-R | C132160 | Extended | 1,657 |
| W25Q32JVSSIQ | C179173 | Extended | 39,664 |
| TYPE-C-31-M-12 | C165948 | Extended | 407,730 |
| AP2112K-3.3TRG1 | C51118 | unverified | 70,670 |
| ME6211C12M5G-N | C236672 | Basic | 28,080 |
| KT-0603R | C2286 | Basic | 3,752,200 |
| 1532H4-16000JWPDTSNL | C5383161 | Extended | 147 |
| USBLC6-2SC6 | C7519 | Extended (inferred) | 35,370 |
| TS-1187A-B-A-B | C318884 | Basic (confirmed) | 792,020 |
| CL05B104KO5NNNC 100 nF | C1525 | Basic (confirmed) | 8,423,900 |
| CL05A105KA5NQNC 1 µF | C52923 | Basic (confirmed) | 5,345,900 |
| CL05A475MP5NRNC 4.7 µF | C23733 | Basic (confirmed) | 1,132,850 |
| CL05A106MQ5NUNC 10 µF | C15525 | Basic (confirmed) | 5,949,500 |
| 0402WGF1000TCE 100 Ω | C25076 | Basic (confirmed) | 329,500 |
| RC0402FR-07270RL 270 Ω | C163474 | Extended (confirmed) | 281,900 |
| 0402WGF1001TCE 1 kΩ | C11702 | Basic (confirmed) | 4,014,300 |
| 0402WGF5101TCE 5.1 kΩ | C25905 | Basic (confirmed) | 6,365,200 |
| 0402WGF1002TCE 10 kΩ | C25744 | Basic (confirmed) | 7,032,300 |
| 0402WGF1003TCE 100 kΩ | C25741 | Basic (confirmed) | 8,524,800 |
| BSMD1206-050-6V polyfuse | C883122 | Extended (confirmed) | 36,710 |
| MMZ1608Y601BTA00 ferrite | C136491 | Extended (inferred) | 11,200 |

I pinned the rows below the oscillator on 23 Aug 2026, and their stock counts
are from that date. "Inferred" means the part isnt in JLC's Basic listing or
published Basic-parts export, so it may be Extended. Confirm it in the PCBA quote.

The 1.2 V regulator is Basic. I switched the 3.3 V regulator to an AP2112K after
C82942 went out of stock. JLC's listing doesnt show its tier, so I wont know if
it adds another setup fee until the quote comes back. Both parts are still
SOT-23-5 and share a footprint.

1. Extended parts have a setup fee for each distinct part. Between 7 and 9
   parts may be Extended, depending on C7519 and C136491. For five boards, those
   fees cost more than the BOM. I got nine of the ten passive values into JLC's
   Basic tier. The 270 Ω 0402 resistor has no Basic option at any tolerance.
2. Check each footprint against JLCPCB's land pattern, not the generic KiCad
   library. The USB-C receptacle and QFN-48 paddle are the ones most likely to
   cause trouble.
3. Check stock when ordering. There were 546 FPGAs in stock when I last checked.

---

## post-routing checklist

lives in [ROUTING.md](ROUTING.md#post-routing-checklist) now, with the items the
netclass pass added. tick boxes there

---

## state of the board file

The current `morphcpu.kicad_pcb` has 80 components, four mounting holes, 546
track segments and 193 vias. The 70 mm outline, 1.6 mm thickness, 9 mm LED pitch
and mounting positions are unchanged.

18 Sep 2026, `kicad-cli 10.0.5 pcb drc --refill-zones --schematic-parity --severity-all`:

```
Found 0 violations
Found 0 unconnected items
Found 0 schematic parity issues
```

LED1 and LED2 now leave the south edge of the FPGA from pins 45 and 42.
[ROUTING.md](ROUTING.md#routing-cleanup) has the cleanup details and the pending
bitstream build check.

If you open the board file, check these two things by hand:

- J1 overhang. The USB-C receptacle sits at the +X edge so a plug can seat. Check
  the shell against the board outline, `usb_angle` and the case cutout. A render
  cant tell you if that clearance is right.
- Which parts are on each side. The 16 LEDs, SW1 and the CDONE LED are on the
  front. Everything else is on the back.

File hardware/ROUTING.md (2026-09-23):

# routing

routed and connected. 4 layers, 546 tracks, 193 vias and 1504.7 mm of tracks,
four GND pours and the one F.Cu rule area. Board Setup has ten net classes and
the additional manufacturing constraints are in `morphcpu.kicad_dru`

18 Sep 2026, KiCad 10.0.5 with zones refilled and schematic parity checked:
0 violations, 0 unconnected items, 0 schematic mismatches. ERC is also clear

## routing cleanup

LED1 moved from FPGA pin 3 to 45, IOB_5b in bank 2. LED2 moved from pin 23 to
42, IOT_51a in bank 0. both banks already run at 3.3 V, and neither pin is a
configuration pin, RGB output or global clock input. the assignments match
[Lattice's SG48 schematic](https://www.latticesemi.com/-/media/LatticeSemi/Documents/SchematicSymbols/ICE40_Single_Wire_Aggregation_Board_Schematic_RevA_200909.ashx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).
the source netlist, schematic, board and PCF changed together

the two new routes escape south and reach the resistor ring on the inner
layers. the LED grid and component placement stayed where they were. removing
short steps, overlapping track ends and the loop around C20 reduced the total
from 769 to 546 segments, including the new LED routes. five vias were added

Board Setup had a 0.127 mm track minimum despite the 6 mil requirement below.
it is now 0.1524 mm. the remaining 0.15 mm and 0.1874 mm tracks were widened
to 0.20 mm. the copper passes with the stricter minimum and unchanged clearance
and via rules

footprint library identifiers are now complete, mounting holes are marked
board-only, and the five altered capacitor footprints match their library copies
without moving their pads. U4 and R26 now carry the schematic values,
AP2112K-3.3TRG1 and 1M. the old PCB values were ME6211C33M5G-N and 10k

both simulations pass, 13/13 grid checks and 5/5 UART/top-level checks. a fresh
bitstream build is still pending. Windows Smart App Control blocked
`yosys-abc.exe` and then `libpcre2-8-0.dll` when nextpnr was tried with the previous
synthesized design. the earlier 37.33 MHz result does not validate this pin map

the fab ZIP, BOM, CPL and current board previews were regenerated from this board

## earlier routing passes

the notes below record the earlier passes, including the two LED connections
that were still open on 30 Aug 2026

the old "10 unrouted" number was just wrong. `kicad-cli pcb drc` refills zones
before it checks and on a refill two of the three GND items and LED5_A close by
themselves, so the board had been sitting at 7 the whole of the previous pass.
read the count off kicad-cli, not off a stale fill

placement did move once after the first pass. the 16 LED resistors went onto
their own LEDs' rays which took the anode ratsnest 405 mm -> 53.4 mm, and the
UART went from pins 6/9 to 34/36. both generator changes not hand edits, whats at
the bottom of the route order covers it

open `morphcpu.kicad_pcb`, work down [route these in this order](#route-these-in-this-order),
then the [post-routing checklist](#post-routing-checklist)

## net classes

| Class | Track | Clearance | Via pad/drill | Nets |
|---|---|---|---|---|
| PWR_5V | 0.50 mm | 0.2 mm | 0.8 / 0.4 mm | VBUS, VBUS_IN, FT_VCC |
| PWR_3V3 | 0.40 mm | 0.2 mm | 0.8 / 0.4 mm | +3V3 |
| PWR_1V2 | 0.40 mm | 0.2 mm | 0.8 / 0.4 mm | +1V2 |
| GND | 0.40 mm | 0.2 mm | 0.6 / 0.3 mm | GND |
| PWR_FILT | 0.30 mm | 0.2 mm | 0.6 / 0.3 mm | FT_3V3, VCCPLL_F, VPP_2V5 |
| CLK | 0.25 mm | 0.2 mm | 0.6 / 0.3 mm | CLK |
| USB | 0.25 mm | 0.2 mm | 0.6 / 0.3 mm | USB_DP, USB_DM, USB_DP_F, USB_DM_F |
| UART | 0.25 mm | 0.2 mm | 0.6 / 0.3 mm | UART_TX_O, UART_RX_I |
| SPI_FLASH | 0.20 mm | 0.2 mm | 0.6 / 0.3 mm | FLASH_CLK, FLASH_CS, FLASH_DI, FLASH_DO |
| Default | 0.20 mm | 0.2 mm | 0.6 / 0.3 mm | the other 43, mostly LED* and LED*_A |

USB also carries diff pair width 0.25 mm / gap 0.25 mm so the pair tool doesnt fight
you. every class got a pcb_color too

verified against the actual board, all 63 real nets land in a class and nothing fell
thru to Default that shouldnt have:

```
CLK (1), GND (1), PWR_1V2 (1), PWR_3V3 (1), PWR_5V (3), PWR_FILT (3),
SPI_FLASH (4), UART (2), USB (4), Default (43)
```

### where the widths came from

IPC-2221 external-layer formula, `I = 0.048 x dT^0.44 x A^0.725`, A in mil squared,
1 oz = 1.378 mil thick. same formula and constants
[tracewidthcalculator.com](https://tracewidthcalculator.com/) and
[schemalyzer's trace width guide](https://www.schemalyzer.com/en/blog/pcb-design/basics/pcb-trace-width-guide)
publish. at dT = 10 C:

| Width | mil | Max current @ dT=10 C | @ dT=20 C |
|---|---|---|---|
| 0.15 mm | 5.91 | 0.60 A | 0.82 A |
| 0.20 mm | 7.87 | 0.74 A | 1.01 A |
| 0.25 mm | 9.84 | 0.88 A | 1.19 A |
| 0.30 mm | 11.81 | 1.00 A | 1.36 A |
| 0.40 mm | 15.75 | 1.23 A | 1.67 A |
| 0.50 mm | 19.69 | 1.45 A | 1.96 A |

cross-check, schemalyzer's published table says 5 mil -> 0.5 A and 10 mil -> 1 A at
1 oz / 10 C. my 5.91 mil -> 0.60 A and 9.84 mil -> 0.88 A sit either side of those so
the arithmetic tracks

run it backwards against [DESIGN.md's power tree](DESIGN.md#power-tree) and
nothing on this board is current-limited:

| Rail | Current | Width IPC-2221 actually demands |
|---|---|---|
| VBUS, at the 500 mA polyfuse hold | 0.500 A | 0.115 mm (4.55 mil) |
| +3V3 total | 0.110 A | 0.014 mm |
| LED grid alone | 0.080 A | 0.009 mm |
| +1V2 worst case | 0.030 A | 0.002 mm |

IR drop says the same thing. 1 oz copper is 0.4914 mOhm/square, so a 30 mm run of
0.5 mm VBUS at 500 mA drops 14.7 mV, 30 mm of 0.4 mm +3V3 at 110 mA drops 4.1 mV, and
25 mm of 0.4 mm +1V2 at 30 mA drops 0.92 mV against a 1.14-1.26 V window. all of it
is noise

the widths arent thermal and they arent IR then. theyre picked so 0.5 mm VBUS has
~2.9x margin over the fuse it sits behind, so the rails are visually obvious while
you hand route, and so DRC catches you if you ever pull VBUS out of a pad at signal
width by accident

neck the escapes. U1 is a QFN-48 on 0.5 mm pitch with 0.25 mm pads so the gap
between adjacent pads is 0.25 mm, and a 0.4 mm power trace centred on one leaves
0.175 mm to its neighbour, under the 0.2 mm class clearance -> DRC error. come off
pins 1, 5, 22, 24, 30 and 33 at 0.2 mm and widen once youre clear of the package,
board minimum is 0.1524 mm so theres room to neck

## DRC rules

Board Setup minimums now:

| Constraint | Value | Why |
|---|---|---|
| min track width | 0.1524 mm (6 mil) | [DESIGN.md PCB brief](DESIGN.md#pcb-brief) |
| min clearance | 0.1524 mm (6 mil) | same |
| min connection width | 0.1524 mm | catches necked zone connections |
| min via diameter | 0.6 mm | JLC standard tier |
| min through hole | 0.3 mm | JLC standard tier |
| min via annular ring | 0.15 mm | falls out of 0.6 / 0.3 |
| min hole clearance | 0.25 mm | between JLC's via 0.2 and PTH 0.28 |
| min hole to hole | 0.25 mm | ditto, `.kicad_dru` splits it properly |
| copper to edge | 0.5 mm | unchanged, way above JLC's 0.2 |
| min text height | 1.0 mm | JLC floor |
| min text thickness | 0.15 mm | JLC floor |

the two silk numbers are exactly JLC's floor and the board already sits on it, all 168
reference and value fields are 1.0 mm high / 0.15 mm thick. nothing to fix, the rules
are there so a future edit cant drift under

`morphcpu.kicad_dru` holds the five rules the dialog cant express, all of them scoped
to one item type, via drill 0.3-6.3 mm, via pad 0.6 mm, via-to-via hole spacing
0.2 mm, pad-to-pad hole spacing 0.45 mm, plated-pad-to-track 0.3 mm

### what JLC charges extra for

per [jlcpcb.com/capabilities/pcb-capabilities](https://jlcpcb.com/capabilities/pcb-capabilities)
and [schemalyzer's JLCPCB design rules](https://www.schemalyzer.com/en/blog/manufacturing/jlcpcb/jlcpcb-design-rules).
these were all read off the 2-layer 1 oz FR-4 page and the board went to 4 layers
after, i havent re-read them against the 4 layer tier:

- the hard process floor is 0.10 mm / 0.10 mm (4 mil / 4 mil) track and space, but
  the number you actually design to is 5 mil, the economical tier for 2-layer. 6 mil
  is a mil clear of that so nothing here triggers a fine trace fee. 3.5 mil is a
  multilayer-only thing anyway and carries +20% on 4-8 layers
- 0.15 mm drills cost more, JLC flags it on the page. 0.3 mm hole / 0.6 mm pad is the
  free combination and thats what every class is set to. dont hand-place a 0.25 mm
  via to squeeze under the FPGA, the `.kicad_dru` will catch it but its easier not to
- copper to routed board edge only needs 0.2 mm. were at 0.5 mm so the round outline
  has room even where J1 overhangs

30 Aug DRC, `kicad-cli 10.0.5 --severity-all`, 0 violations and 2 unconnected items,
was 167 unconnected pads before any copper went down. the C20/R27 silk overlap is
gone, C20s reference field moved 1.3 mm in X, both run vertically and were stacked in
Y. zero courtyard overlaps, zero shorting pads, zero clearance errors

run DRC with the `.kicad_pro` beside the board. `kicad-cli pcb drc` on a lone
`.kicad_pcb` silently falls back to default Board Setup, not this one, and then
reports every 0.15 mm track as a `track_width` error against a 0.2 mm minimum that
isnt ours. copy `morphcpu.kicad_pro` and `morphcpu.kicad_dru` next to any board you
verify out of tree

## the freerouting attempt

the first attempt got reverted and the board went back to 0 tracks. a later pass did
land, thats where the copper on the board now came from, keeping the numbers here so
nobody spends another evening rediscovering the setup

freerouting 2.3.0 wants Java 25, not 21. the jar is class file version 69 and Temurin
21 refuses to load it. winget install of the Temurin MSI wants elevation and dies
with 1602 if nothing is there to click the prompt, so unpack the Adoptium zip
instead, no admin needed

`pcbnew.ExportSpecctraDSN` and `pcbnew.ImportSpecctraSES` both exist in the python
API, so the round trip is scriptable. `kicad-cli pcb export` has no dsn subcommand
in KiCad 10, dont go looking for one. the DSN carries all ten net classes with
their widths and both via padstacks.

```sh
java -jar freerouting-2.3.0.jar -de hardware/route/morphcpu.dsn \
     -do hardware/route/morphcpu.ses -inc GND -mp 100 --gui.enabled=false
```

32 passes, 8m10s, then it stalled. best score 877.18 hadnt moved since pass 22 and
the optimizer quit after one pass at 0.0000% improvement. what came back:

| | |
|---|---|
| DRC violations | 13 |
| unconnected | 8 |
| tracks | 753 segments + 112 vias |
| F.Cu | 211 segments, 791.9 mm, 45.9% |
| B.Cu | 542 segments, 932.9 mm, 54.1% |

the 13 were 8 `track_width` at 0.150 mm against the 0.1524 minimum, 2
`annular_width` on VBUS vias at a 0.10 mm ring, 2 `via_dangling`, and the usual
cosmetic silk overlap. widths came back off-class in six different values it
invented on the fly, 0.1874 and 0.2502 and 0.3998 and so on.

three things made it not worth keeping. `-inc GND` doesnt exclude GND, it routed it
anyway, 339.1 mm across 168 segments, opposite of the pour plan. the QFN paddle came
out with zero vias in it and U1-49 was one of the unconnected, and thats the only
ground path to the die. and the 8 unconnected were real breaks on +3V3, VBUS, +1V2
and VBUS_IN, not pour artifacts

the front face is the main reason it got reverted, 211 segments and long diagonals
running corner to corner straight thru the LED grid. renders are in
[docs/img/routed-3d-top.png](../docs/img/routed-3d-top.png) and
[routed-3d-bottom.png](../docs/img/routed-3d-bottom.png) if you want to see it, the
back was fine, roughly radial fan-out from the QFN

the DSN in `hardware/route/` is still there and still valid so the export step is
done if you want another go. would want GND actually excluded and a keepout over the
LED grid on F.Cu first

## route these in this order

hardest first. the LED anodes used to own this list, see [the bottom](#12-the-led-anodes)
for why they dont any more.

### 1. VBUS and VBUS_IN

0.5 mm wide, 137 mm of ratsnest combined, and it spans the entire back layer which
is also the only crowded layer. do it first while the rim is still empty, a 0.5 mm
trace cannot squeeze thru gaps that a 0.2 mm signal left behind

the awkward bit is that F1, the polyfuse, is at th = 90 deg (north, r = 25-27)
while J1 is at th = 0 deg (east). so VBUS_IN runs ~26 mm around the rim from the
connector up to the fuse before VBUS comes back out and fans to U4 (north,
th = 93 deg), U5 (south, th = 267 deg), FB2 (east, th = 16 deg) and U6 (east,
th = 345 deg). nine pads spread over ~300 deg of arc.

### 2. +3V3

25 pads, 147 mm, back layer only, touches basically every part on the board. the LED
current path is the bit to watch, the grid sources from FPGA I/O so the whole 80 mA
of LED drive arrives thru VCCIO pins 1, 22 and 33. dont neck +3V3 down anywhere
between U4 and those three pins

### 3. GND

there was no zone in the file at all going in, zero of them, so all 58 GND pads were
floating and thats most of the 167 unconnected. pour early and refill often, every
later net changes the pour

the paddle needs its 3x3 or 4x4 field of 0.3 mm vias per DESIGN.md. those already
match the class geometry

### 4. LED0 thru LED15, the pin side

stale as written, LED2, LED3, LED9, LED12, LED13 and LED14 no longer come off the
faces described here, [the fanout ran out of room](#the-fanout-ran-out-of-room-so-six-pins-moved)
has where they went

193 mm across 16 nets, each a hop from a QFN pad out to its resistor at r = 11.5 mm,
or r = 14.5 mm for the four corners. biggest signal group on the board and a
congestion problem, cuz 16 escapes plus 7 decoupling vias plus 6 supply escapes all
leave the same 8.7 x 9.8 mm package footprint

this total did not improve when the resistors moved, 193.4 mm before and 193.4 mm
after. the hop length is set by the ring radius and the ring radius didnt change, the
win was all on the anode side

### 5. the USB pair

`USB_DP` / `USB_DM` from J1 -> U6, then `USB_DP_F` / `USB_DM_F` from U6 -> U2.
short, 10-14 mm each, but U6 sits at r = 29-32 mm which is outboard of J1 at
r = 26 mm, so the pair goes out to the clamp and back in to the bridge. thats
deliberate, DESIGN.md wants the trace routed thru the part not stubbed off it.

impedance, plainly, you cannot hit 90 Ohm differential on 2-layer 1.6 mm FR-4. a 50
Ohm single-ended microstrip over 1.6 mm of dielectric wants a trace ~2.9 mm wide, not
happening on a 70 mm board. the FT231X is full speed, 12 Mbps, over ~15 mm of trace,
so it works untuned and everyone does it. route them short, symmetric, tightly
coupled at the 0.25 mm class gap, over unbroken ground, dont pretend to tune it

### 6. CLK

29.5 mm, from X1 pad 3 at r = 25.6 mm / th = 167 deg to U1 pin 35 at r = 4.1 mm /
th = 327 deg. thats near enough diametric, and it crosses the resistor ring and
the decap ring on the way in.

[DESIGN.md](DESIGN.md#placement-scheme) says west holds the flash and the
oscillator "both kept close to the FPGA because the SPI and clock nets care". X1
is at r = 26.8 mm which makes it the furthest-out part on the west side, outboard of
U3 at r = 20 mm. so the clock net is 29.5 mm and no pin choice fixes that, moving X1
inward would if you decide its worth reopening placement

this got slightly harder and its the one real cost of the UART move. pin 35 used to
have empty pads either side of it, 34 and 36, so CLK could escape straight out
between them with nothing to cross. both are UART now. CLK still escapes cleanly
outward but it has to cross one UART trace to turn west, so plan on a via down to the
front within a couple of mm of the package and run it west on the front, which is
nearly empty anyway. one via on a 16 MHz clock over a ground pour is a non-event, its
just no longer optional

dont let it run parallel to the UART for any distance, and give it more clearance by
hand than the 0.2 mm class rule asks for

### 7. the flash, FLASH_CLK / CS / DI / DO

15-27 mm each. U1 pins 14-17 sit at th = 102-123 deg (north face) but U3 is at
th = 173-185 deg (west), so they sweep round the northwest quadrant. FLASH_CS and
FLASH_DO come off U3's far pads at r = 23.6 mm so theyre the long two at 27 mm and
22 mm. keep CLK and DO abt the same length. its only a config-time bus but its the
bus that decides whether the board boots

### 8. +1V2

8 pads, 45 mm, U5 (south, th = 267 deg) up to U1 pins 5 and 30 plus the two 100 nF
at r = 6 mm. straightforward, just wide.

### 9. RST_N, CDONE, CDONE_A

front-to-back, 19-51 mm. SW1 is front north at r = 23 mm, D17 is front south at
r = 21 mm, and both their partners are on the back. RST_N is 51 mm of ratsnest
over 4 pads cuz SW1's two pole pairs and R28 at th = 328 deg pull it three
directions at once.

### 10. UART_TX_O and UART_RX_I

was 21.0 mm and 26.2 mm crossing the whole board, cuz the bridge is east and pins
6/9 face west. now 14.0 mm and 19.2 mm, both straight shots at U2

UART moved off pins 6/9 in the config bank onto 34 and 36 in bank 0, which look
directly at U2. checked for tradeoffs and there is exactly one, the CLK escape above.
everything else came back clean:

| Check | Result |
|---|---|
| VCCIO level | bank 0 is +3V3 via pin 33, same as bank 1 was. no level change |
| LED bank balance | untouched, the 80 mA split across banks is unchanged |
| GBIN pins | 34 and 36 are plain IOT, pin 20 (G3) and pin 37 (G1) stay free |
| config pins | 34/36 are not SPI (14-17), CRESET_B (8) or CDONE (7) |
| RGB driver pins | 39-41 still unused |
| ERC | 0 errors, 0 warnings after the change |

34 is TX and 36 is RX, not the other way round. U2 pad 4, its RXD, sits at y = +0.95
and pad 20, its TXD, at y = +2.86, both on U2's south edge, and pin 36 is the more
southerly FPGA pin. feeding the southern target from the southern pin runs the two
traces parallel. the literal 6->34, 9->36 swap puts them the other way and they cross
abt 14 mm out

pins 6 and 9 are free ordinary I/O now.

### 11. the rest

CC1, CC2, EN_3V3, XO_EN, CRESET_B, FLASH_WP, FLASH_HOLD, FT_RESET, FT_VCC, FT_3V3,
VCCPLL_F, VPP_2V5. all short, all local to one cluster, none over 15 mm. mop-up.

### 12. the LED anodes

was 405 mm with all 16 chords passing within 3.11 mm of board centre, ie straight
under the QFN paddle. now 53.4 mm, and the closest any of them gets to centre is
5.83 mm, which is the LED pad itself on the four inner cells and not a crossing.
nothing passes under the package any more

| | before | after |
|---|---|---|
| total anode ratsnest | 405.0 mm | **53.4 mm** |
| longest single anode | 31.7 mm (LED15_A) | 5.21 mm (LED5_A, LED9_A) |
| shortest | 17.7 mm | 1.49 mm |
| chords within 5 mm of centre | 16 | **0** |
| closest approach to centre | 0.13 mm | 5.83 mm |

each anode is now a radial hop of 1.5 to 5.2 mm from an LED pad to the resistor
directly inboard or outboard of it. route them last, theyre 16 near-identical
short stubs and they will fall out of whatever the pour leaves.

the cause was one line in `scripts/gen_pcb.py`. it sorted the LEDs by angle,
correctly, then handed out ring slots at `k * 22.5` starting from zero, and the
sorted list starts at -161.6 deg. so slot 0 went to the LED at -161.6 deg and every
resistor landed 157-180 deg from its partner. the sort was fine, the handout wasnt

the fix isnt a rotation either, a uniform 16-slot ring cant work here at all. a 4x4
grid on 9 mm pitch puts the four inner LEDs and the four corner LEDs on the same four
diagonals, 45/135/225/315, so eight parts want four rays. the corner resistors go out
to r = 14.5 mm and the other twelve stay on r = 11.5 mm, 3.00 mm between the closest
pair

the LED grid itself did not move. all 16 are still at their exact 9 mm pitch
positions, cell 0 top-left row-major, front layer, each `D(n+1)` still carrying
`LED(n)_A`. verified pad by pad after regeneration cuz that mapping is what makes the
demo mean anything

### watch out for gen_pcb.py

`pcbnew.SaveBoard` rewrites `morphcpu.kicad_pro` from the board object's defaults,
which silently wipes all of Board Setup: every net class, every DRC minimum, the
track and via presets. found it by regenerating and watching the previous session's
netclass work disappear. `gen_pcb.py` now lifts `board.design_settings` and
`net_settings` out before the save and puts them back after, and prints
`restored Board Setup: 10 net classes + DRC rules` so you can see it happen.

if that line ever stops appearing, check Board Setup before you route anything.

## post-routing checklist

the one that gets ticked. DESIGN.md used to carry a copy and now points here

- [ ] DRC with the JLCPCB constraints (6 mil track/clearance, 0.3 mm via hole),
      zero errors, and review and justify every warning
- [ ] paddle via field present and connected, paste aperture windowed rather than
      one big square
- [ ] measure the 4x4 grid, 9 mm pitch, centred, cell 0 top-left, silkscreen order
      matching the fabric map
- [ ] artwork annulus (r = 22-29 mm) still clear
- [ ] case updated, `pcb_dia`, `pcb_thickness`, `mount_hole_r`, `mount_hole_count`,
      `mount_hole_angle_offset`, `usb_angle`, `usb_z_centre` in
      `case/morphcpu_case.scad` off the finished board, then `./export.sh`
- [ ] PCF against the [pin table](DESIGN.md#user-io-assignment) if any pin moved
      during routing. they agree right now, all 20
- [ ] build a bitstream. install the OSS CAD Suite, run `gateware/build.sh`, put
      real LUT/BRAM utilisation and Fmax in `JOURNAL.md`
- [ ] re-run `gen_fab.py`. the fab package exists but the copper in it has to be off
      the routed board or youll ship blank layers
- [ ] 3D view screenshot for the README, `kicad-cli pcb render` (or KiCad's 3D
      viewer) -> `docs/img/pcb-3d.png`
- [ ] composite render of case + PCB together for the README hero image
- [ ] re-check the BOM in `docs/BOM.md` against the final board. its costed and all
      22 rows are pinned, but quantities come from the schematic and the two inferred
      Extended tiers still need confirming in the quote
- [ ] USB-C overhang against the board edge and the case cutout once the outline is
      final
- [ ] tidy silkscreen. one cosmetic text overlap left, C20 against R27, was three
      before the resistor ring moved. itll move as you adjust parts anyway

new since this pass:

- [ ] ground zones exist and are filled, stitched, no isolated islands. there were
      zero zones in the file when routing started
- [ ] every track on its net class width. select by net class in pcbnew and confirm
      nothing got drawn at Default width on a power net, and that the QFN escapes you
      necked to 0.2 mm actually widen again once theyre clear
- [ ] DRC with `morphcpu.kicad_dru` active, no via under 0.3 mm drill / 0.6 mm pad,
      thats the JLC surcharge line
- [ ] BOM/CPL regeneration picks up any net added while routing. a test point, a
      stitching pad or a zero-ohm link needs a designator, a footprint and an LCSC
      part or itll fail the PCBA parse
- [ ] Board Setup survived any `gen_pcb.py` re-run. the script prints
      `restored Board Setup: 10 net classes + DRC rules` when it worked

## what is left unrouted

none after the 18 Sep cleanup. the report below is from 30 Aug and is kept with
the trials that led to it

```
$ kicad-cli pcb drc --severity-all hardware/morphcpu.kicad_pcb
Found 0 violations
Found 2 unconnected items
```

30 Aug 2026, against the board as committed

| # | Net | From | To |
|---|---|---|---|
| 1 | LED1 | U1.3 | R2.1 |
| 2 | LED2 | U1.23 | R3.1 |

both LED drive nets, so it powers and configures and boots and talks, two of the
sixteen grid leds just dont light. +1V2 at U1.5 was the one that actually
mattered cuz its a core VCC pin and thats routed

both of them route on their own. together they dont, and its the same
oversubscription as before one notch out, R2 and R3 both sit due north at
y = 89.6 while LED1 comes off the west face at pad 3 and LED2 off the north face
at pad 23, and the north face is already carrying eleven nets four of which are
flash signals crossing to U3 in the west

## the fanout ran out of room, so six pins moved

seven connections were open going in. GND at C5.2, CDONE at U1.7, +3V3 at U1.22
and U1.33, +1V2 at U1.5 and U1.30, LED12 at U1.27. each one had exactly one
blocker, measured against pcbnew geometry not guessed at

| Connection | Blocked by |
|---|---|
| U1.5 (+1V2) | LED2's B.Cu diagonal cutting across at y = 100.974 |
| U1.22 (+3V3) | LED9's jog to x = 152.087, itself forced by LED3's via at 152.765, 95.550 |
| U1.30 (+1V2) | the VCCPLL_F via at 154.450, 99.388 |
| U1.33 (+3V3) | the LED15 via at 154.488, 101.150 |
| C5.2 (GND) | the In1.Cu LED3 bus at y = 96.488, 1833 of 6100 candidate via cells in that pocket blocked by one track |
| U1.7 (CDONE) | the In2.Cu VBUS bus, 245 cells, again one net |

### why no amount of copper fixes it

a 0.6 mm via wants 1.2 mm between its neighbours and adjacent escape rays are
0.5 mm apart. via pad radius 0.3 + track half width 0.1 + clearance 0.2 = 0.6 mm
each side. nothing changes layer inside the pad ring, and nothing changes layer
out in the fan either until its spread to roughly 2.4x the pad radius. no legal
via site anywhere in a 7 x 1.2 mm band around the GND island, none in U1.7's
escape pocket

the staggered two row via fanout is the standard trick at 0.5 mm pitch and it
fails the same way here, the outer row's neck has to pass between two inner row
vias with 1.0 mm available against 1.2 mm needed. tested that, didnt assume it

and U1's east column was carrying twelve nets on twelve channels with four of
them, LED12 LED13 CLK VCCPLL_F, landing on the far side of the board so they
crossed the fan twice. west column same story with LED2 and LED3, both their
resistors are northeast

### the six that moved

pads 37-48 were sitting entirely unused and the area south of the package is
open, so the far side crossers went there, ordered by their resistors' x so none
of them cross. LED9 went south first onto pad 47 and then spent its time fighting
LED12 on pad 48 for the same southwest corridor, so it took pad 9 on the west face
instead. that one move is what let +1V2 out of U1.5

| Net | was | now | why |
|---|---|---|---|
| LED12 | 27 IOT_38b | **48** IOB_4a | R13 at x = 140.1 |
| LED9 | 23 IOT_37a | **9** IOB_16a | R10 at 141.5, 108.5, pad 9's ray points at it |
| LED13 | 28 IOT_41a | **46** IOB_0a | R14 at x = 146.5 |
| LED14 | 31 IOT_42b | **38** IOT_50b | R15 at x = 153.5 |
| LED2 | 4 IOB_8a | **23** IOT_37a | R3 due north at 153.5, 89.6 |
| LED3 | 11 IOB_20a | **27** IOT_38b | R4 at 159.9, 90.1 |

same checks the original assignment had to pass:

- 46/47/48 are bank 2 (VCCIO_2 = pin 1), 23/27/38 are bank 0 (VCCIO_0 = pin 33).
  both already +3V3 so nothing changes level
- no LED on a config pin (14-17), CRESET_B (8) or CDONE (7)
- no LED on an RGB driver (39-41)
- no LED on a global buffer. 37 is G1, 44 is G6, 20 is G3 and still free so
  theres a second global clock left
- CLK stays on 35, still a GBIN
- bank balance 25 / 25 / 30 mA across VCCIO_2 / VCCIO_1 / VCCIO_0, was 15 / 30 / 35
- ERC after regenerating the schematic, 0 violations

`netlist.py`, `gateware/morphcpu.pcf` and the
[DESIGN.md pin table](DESIGN.md#user-io-assignment) all moved together and the
`unconnected-(...)` names the regenerated netlist spits out match whats written
onto the board pad for pad

LED12 LED13 LED14 went 42.0 / 36.1 mm and unroutable to 12.5 / 7.8 / 8.0 mm.
eleven of the twelve outstanding connections then routed with nothing ripped up

### four bugs in the router, all real

each of these quietly threw away channels that were legal:

- the rasteriser was half a cell out. `fill_poly` treated grid cells as half open
  squares while `cell()` and `pos()` treated them as lattice points so every
  obstacle sat 0.025 mm off, which on its own loses a QFN escape
- a 0.01 mm inflation bias. obstacles grown by clearance + 0.01 mm, and the
  tightest real clearances in this fanout are 0.2019 mm against a 0.2 mm rule.
  rasterise at exactly the netclass clearance and let exact geometry arbitrate
  after
- hole to hole checks were reading the board's original track list, which still
  had the vias that had just been ripped, so candidate vias in a ripped pocket got
  rejected against copper that wasnt there any more
- a route's own vias never got checked against each other. two layer changes in
  neighbouring cells puts two holes 0.07 mm apart, same net clearance doesnt care,
  `jlc_via_hole_to_hole` does

with those four fixed the same router went from reproducing nothing to
reproducing every net that was already down

### the last two

LED1 and LED2 both route alone, never together. whole net rip, radius limited
rip, exact item rip, ordering search over seeds, all of it lands back on two.
pin trials, +1V2 placed first every time:

| LED2 | LED9 | LED1 | still open |
|---|---|---|---|
| 23 | 47 | 3 | 3: +1V2, LED2, LED9 |
| 23 | 4 | 3 | 3: LED1, LED9, LED2 |
| 20 | 4 | 3 | 3: LED1, LED9, LED2 |
| 4 | 6 | 3 | 3: CDONE, LED2, LED9 |
| 4 | 9 | 3 | 2: CDONE, LED2 |
| 20 | 9 | 3 | 2: LED1, LED2 |
| **23** | **9** | **3** | **2: LED1, LED2** (kept, the two opens are LED nets not CDONE) |

moving LED1 doesnt close anything either, it just moves which net fails:

| LED1 on | ripped and re-placed | still open |
|---|---|---|
| 3 | LED0, LED5, LED6, LED7, VPP_2V5 | 3: LED1, LED7, LED2 |
| **20** (G3) | LED0, LED5, LED6, LED7 | 2: LED7, LED2 |
| **20** (G3) | + FLASH_DI, FLASH_DO | 2: LED7, LED2 |
| **11** | LED0, LED4, LED5 | 2: LED5, LED2 |

LED1 routes from pin 20 or pin 11 and LED7 or LED5 opens instead. count is
conserved at two across everything tried, north face is two nets past what it can
fan out. spending pin 20, the spare G3, buys nothing, tried it

options if someone picks this up:

1. move the flash bus off the north face. pins 14-17 are fixed by the iCE40
   config block so this means moving U3 itself round to the north instead of the
   west, takes four crossers out of the north fan in one go. its a placement
   change and DESIGN.md picked west on purpose
2. move R2 and R3. they sit at y = 89.6 due north, which is what drags LED1 and
   LED2 across the package. ring geometry is generated so thats a `gen_pcb.py`
   change not a hand edit
3. a router that holds the whole fanout at once, negotiated congestion,
   PathFinder history costs. the greedy plus rip-up in the scratch scripts gets to
   two and stops

dont spend another evening on plain rip-up-and-retry. its been tried at whole
net, radius limited and per item granularity with ordering search over seeds and
it converges to the same two every time

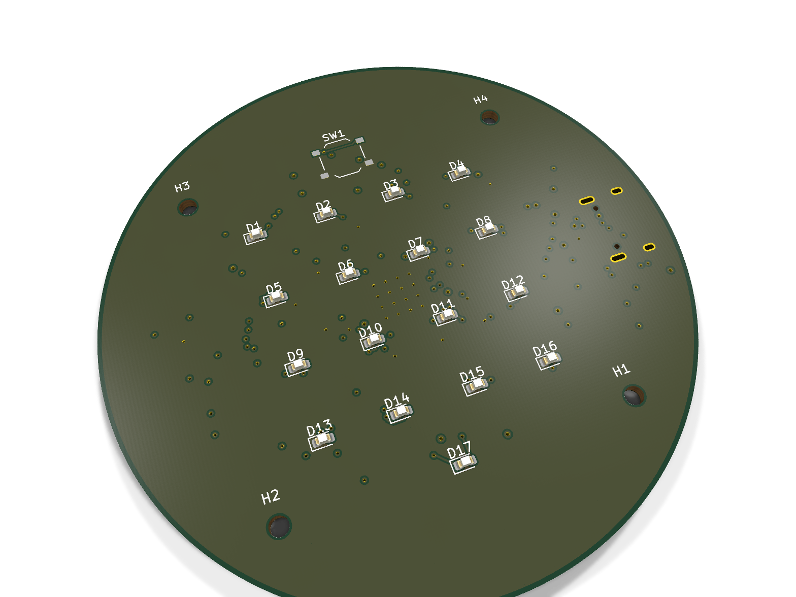
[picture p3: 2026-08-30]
docs/img/routed-3d-top.png

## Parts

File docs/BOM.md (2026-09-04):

# BOM

5 units of everything on the board, 1 unit for the case (its off-PCB). every row
is pinned to an LCSC part number and priced. rows 1-8 checked 20 aug 2026, rows
9-22 checked 23 aug 2026 when the schematic got reconciled against this file

- prices and stock move, re-check the day you order, especially the FPGA
- price basis is LCSC unit price at the lowest qty break, which is what a 5-board
  build actually pays. for most passives that break is 50 or 100 pcs, way above
  the 5-85 we need. JLCPCB's own component prices differ and arent used here
- quantities come from the schematic, not from this file. regen
  [../hardware/fab_output/morphcpu-bom.csv](../hardware/fab_output/morphcpu-bom.csv)
  with `gen_fab.py` and the counts below have to match it

## the parts

| # | Part | MPN | LCSC | Pkg | Qty/unit | Qty for 5 | Unit price | Line total |
|---|---|---|---|---|---|---|---|---|
| 1 | FPGA | ICE40UP5K-SG48I | [C2678152](https://www.lcsc.com/product-detail/C2678152.html) | QFN-48-EP (7×7) | 1 | 5 | $8.564 | $42.82 |
| 2 | USB-UART bridge | FT231XS-R | [C132160](https://www.lcsc.com/product-detail/C132160.html) | SSOP-20-150mil | 1 | 5 | $5.9542 | $29.77 |
| 3 | SPI config flash, 32 Mbit | W25Q32JVSSIQ | [C179173](https://www.lcsc.com/product-detail/C179173.html) | SOIC-8-208mil | 1 | 5 | $1.6846 | $8.42 |
| 4 | USB-C receptacle, 16-pin | TYPE-C-31-M-12 | [C165948](https://www.lcsc.com/product-detail/C165948.html) | SMD right-angle | 1 | 5 | $0.1716 | $0.86 |
| 5 | 16 MHz oscillator (XO) | 1532H4-16000JWPDTSNL | [C5383161](https://www.lcsc.com/product-detail/C5383161.html) | SMD3225-4P | 1 | 5 | $0.3609 | $1.80 |
| 6 | 3.3 V LDO (with enable) | AP2112K-3.3TRG1 | [C51118](https://www.lcsc.com/product-detail/C51118.html) | SOT-23-5 | 1 | 5 | $0.0967 | $0.48 |
| 7 | 1.2 V LDO (with enable) | ME6211C12M5G-N | [C236672](https://www.lcsc.com/product-detail/C236672.html) | SOT-23-5 | 1 | 5 | $0.0606 | $0.30 |
| 8 | LED, red, 16 grid + 1 CDONE | KT-0603R | [C2286](https://www.lcsc.com/product-detail/C2286.html) | 0603 | 17 | 85 | $0.0075 | $0.64 |
| 9 | ESD array, USB D+/D- | USBLC6-2SC6 | [C7519](https://www.lcsc.com/product-detail/C7519.html) | SOT-23-6 | 1 | 5 | $0.1858 | $0.93 |
| 10 | Tactile switch, reset | TS-1187A-B-A-B | [C318884](https://www.lcsc.com/product-detail/C318884.html) | SMD-4P 5.1×5.1 | 1 | 5 | $0.0186 | $0.09 |
| 11 | Cap 100 nF 16 V X7R | CL05B104KO5NNNC | [C1525](https://www.lcsc.com/product-detail/C1525.html) | 0402 | 12 | 60 | $0.0055 | $0.33 |
| 12 | Cap 1 µF 25 V | CL05A105KA5NQNC | [C52923](https://www.lcsc.com/product-detail/C52923.html) | 0402 | 3 | 15 | $0.0122 | $0.18 |
| 13 | Cap 4.7 µF 10 V | CL05A475MP5NRNC | [C23733](https://www.lcsc.com/product-detail/C23733.html) | 0402 | 4 | 20 | $0.0234 | $0.47 |
| 14 | Cap 10 µF 6.3 V X5R | CL05A106MQ5NUNC | [C15525](https://www.lcsc.com/product-detail/C15525.html) | 0402 | 2 | 10 | $0.0258 | $0.26 |
| 15 | Res 100 Ω 1% | 0402WGF1000TCE | [C25076](https://www.lcsc.com/product-detail/C25076.html) | 0402 | 1 | 5 | $0.0079 | $0.04 |
| 16 | Res 270 Ω 1%, LED series | RC0402FR-07270RL | [C163474](https://www.lcsc.com/product-detail/C163474.html) | 0402 | 16 | 80 | $0.0041 | $0.33 |
| 17 | Res 1 kΩ 1%, CDONE LED | 0402WGF1001TCE | [C11702](https://www.lcsc.com/product-detail/C11702.html) | 0402 | 1 | 5 | $0.0067 | $0.03 |
| 18 | Res 5.1 kΩ 1%, CC pull-down | 0402WGF5101TCE | [C25905](https://www.lcsc.com/product-detail/C25905.html) | 0402 | 2 | 10 | $0.0044 | $0.04 |
| 19 | Res 10 kΩ 1% | 0402WGF1002TCE | [C25744](https://www.lcsc.com/product-detail/C25744.html) | 0402 | 8 | 40 | $0.0019 | $0.08 |
| 20 | Res 100 kΩ 1% | 0402WGF1003TCE | [C25741](https://www.lcsc.com/product-detail/C25741.html) | 0402 | 1 | 5 | $0.0054 | $0.03 |
| 21 | Res 1 MΩ 1%, EN_3V3 bleed | 0402WGF1004TCE | [C26083](https://www.lcsc.com/product-detail/C26083.html) | 0402 | 1 | 5 | $0.0016 | $0.01 |
| 22 | Polyfuse, 500 mA hold, 6 V | BSMD1206-050-6V | [C883122](https://www.lcsc.com/product-detail/C883122.html) | 1206 | 1 | 5 | $0.0466 | $0.23 |
| 23 | Ferrite bead, 600 Ω @ 100 MHz | MMZ1608Y601BTA00 | [C136491](https://www.lcsc.com/product-detail/Ferrite-Beads_TDK_C136491.html) | 0603 | 2 | 10 | $0.0126 | $0.13 |
| | | | | | **80** | **400** | **parts subtotal** | **$88.27** |

$17.65 of parts per board. the line totals are rounded to the cent and sum to
$88.27, unrounded it comes to $88.2765. a cent apart, the table carries the
rounded one

## what it actually costs

careful here, the $88.27 above is not a separate line item. its already inside
the JLC PCBA quote, which bundles fab + parts + assembly into one number, adding
both double-counts the parts

| Item | Basis | Cost |
|---|---|---|
| parts subtotal, rows 1-23 (informational, separate from the JLC PCBA total) | 5 units | $88.27 |
| JLCPCB PCBA order: fab + parts + assembly | 5 units | $203.47 |
| case filament | 1 unit, off-PCB | $0.26 |
| | | **$203.73** |

so $203.73 all-in, $40.75/unit across 5 boards. under the Complex ($210) tier
with $6.27 of headroom, which is not much, so dont add parts casually

the $115.20 gap between the parts subtotal and the JLC quote is fab + assembly
setup + extended-part feeder fees. JLC quotes it bundled and doesnt split it out
line by line, so treat that gap as one number

still not in the $203.73, shipping and duty. those only get quoted at checkout
with a real address so they arent here yet, and they eat into the $6.27

### R and C counts

from the schematic, which is the authority:

| Value | Qty/unit | Where |
|---|---|---|
| 100 nF | 12 | 11 supply-pin decouplers + the 3V3 enable RC |
| 1 µF | 3 | LDO bulk |
| 4.7 µF | 4 | LDO bulk and FT231X |
| 10 µF | 2 | rail bulk |
| 270 Ω | 16 | LED grid series |
| 10 kΩ | 8 | CRESET_B, CDONE, SPI_SS, FT231X RESET#, XO enable, reset button, two on the flash |
| 1 kΩ | 1 | CDONE indicator series |
| 5.1 kΩ | 2 | USB-C CC1/CC2 pull-downs, never shared |
| 100 kΩ | 1 | 3V3 enable RC |
| 1 MΩ | 1 | EN_3V3 bleed, was 10 kΩ and divided CE down to 0.45 V |
| 100 Ω | 1 | VCCPLL filter |

an older version of this table said 100 nF ×11, 10 kΩ ×5, no 1 kΩ row at all,
and 16 LEDs instead of 17. schematic was right every time

### stock at lookup time

| Part | LCSC stock | Comment |
|---|---|---|
| ICE40UP5K-SG48I | 546 | lowest-stock part in the design, order early |
| FT231XS-R | 1,657 | fine for 5 |
| W25Q32JVSSIQ | 39,664 | ample |
| TYPE-C-31-M-12 | 407,730 | ample |
| 1532H4-16000JWPDTSNL | 147 | ok but thin, see note below |
| AP2112K-3.3TRG1 | 70,670 | ample |
| ME6211C12M5G-N | 28,080 | ample |
| KT-0603R | 3,752,200 | ample |
| USBLC6-2SC6 | 35,370 | ample |
| TS-1187A-B-A-B | 792,020 | ample |
| MMZ1608Y601BTA00 | 11,200 | second thinnest, fine for 10 pcs but not deep |
| BSMD1206-050-6V | 36,710 | ample |
| RC0402FR-07270RL | 281,900 | ample |
| all other 0402 passives | 330 k to 8.5 M | ample |

## JLC parts tier

tier drives the per-part feeder fee so it matters way more than cent-level part
price. Basic parts are already loaded on the machines

| Tier | Parts |
|---|---|
| **Basic**, confirmed | C1525, C52923, C23733, C15525 (all four caps); C25076, C11702, C25905, C25744, C25741 (five of six resistor values); C318884 (switch) |
| **Extended**, confirmed | C163474 (270 Ω), C883122 (polyfuse) |
| **Extended**, assumed, not confirmed | C2678152, C132160, C179173, C165948, C5383161 (the five actives, costed as Extended from the start); C7519 (ESD); C136491 (ferrite) |

two notes on the unconfirmed rows. JLC's part-detail pages render the tier badge
in JS so it cant be read directly, the tiers above come off JLC's category
listings which do print it. C7519 and C136491 show up in neither the Basic
listings nor a published Basic-parts export, so Extended, but thats an inference
and not a quote. confirm both in the PCBA quote before ordering, each distinct
Extended part carries its own feeder fee

270 Ω 0402 has no Basic option at all, every 270 Ω 0402 in JLC's library is
Extended. options were dropping to 300 Ω or 330 Ω (Basic in 0402, but LED current
goes 5 mA to 4.3 or 3.9 mA), or moving to 0603 (Basic at 270 Ω, but 16 footprints
change). neither trade is worth one feeder fee so we keep 270 Ω and pay for it

## parts that changed since the first costing

| Was | Now | Why |
|---|---|---|
| FT231XS-U (C89607) | FT231XS-R (C132160) | C89607 is out of stock and `-U` is tube packaging. `-R` is tape-and-reel, which an assembly line wants. same SSOP-20-150mil footprint, no pin changes |
| AMS1117-3.3 (C6186) | ME6211C33M5G-N (C82942) | power-up sequence needs 3.3 V held off until 1.2 V is up. AMS1117 is SOT-223 with no enable pin. ME6211 has CE, is Basic tier, cheaper, and shares a footprint with the 1.2 V part |
| ME6211C33M5G-N (C82942) | AP2112K-3.3TRG1 (C51118) | C82942 went to 0 at JLC, 11 day lead and a 196 MOQ behind it. same SOT-23-5, same 1 VIN 2 GND 3 EN 4 NC 5 VOUT pinout, so nothing on the board moves. 600 mA instead of 500. tier didnt render on JLC's listing so thats unconfirmed |
| 12 MHz crystal + 2 load caps | 16 MHz XO (C5383161) + 1 × 100 nF | iCE40 has no crystal amp. 12 MHz active XOs at LCSC had 9 and 1 in stock, the 16 MHz part has 147. costs a gateware param change, and UART divisor error improves from 0.16% to 0.08% |
| no ESD protection | USBLC6-2SC6 (C7519) | this doc listed an ESD array from day one and the schematic never had one. now U6, in the D+/D- path between J1 and U2, placed next to the connector |
| reset switch on `SW_SPST_TL3342` | TS-1187A-B-A-B (C318884) on `SW_Push_1P1T_XKB_TS-1187A` | the part JLC stocks Basic is the XKB TS-1187A, pads at 6.0 × 3.75 mm. TL3342's are 6.3 × 3.8 mm. close enough to look fine on screen, not close enough to solder. footprint follows the part now |

### osc stock note

147 is fine for 5 units but not deep. both 12 MHz alternatives were worse,
[C7503622](https://www.lcsc.com/product-detail/C7503622.html) had 9 units and
[C2451123](https://www.lcsc.com/product-detail/C2451123.html) had 1 at $5.94. if
C5383161 dries up, any 3.3 V HCMOS XO in SMD3225-4P drops straight in, only
`CLK_HZ` in the gateware and `--freq` in `build.sh` follow the frequency

### ferrite current rating

MMZ1608Y601BTA00 is 500 mA with 400 mΩ DCR. FB2 feeds FT231X VCC (tens of mA),
FB1 feeds VPP_2V5 on the FPGA (config only), both sit way inside that. a 0603
600 Ω bead rated 200 mA wouldve worked too, i took 500 mA for margin on FB2

## the case filament number

1 unit not 5, off-PCB parts only have to cover one assembled demo unit and the
case is off-PCB. five frames would be 64.5 g and $1.29 if anyone ever wants them

$0.26 (12.9 g PLA @ 20% infill, $19.99/kg)

how we got there:

| Step | Value | Source |
|---|---|---|
| solid volume of the exported frame | **11,627.47 mm³** | [../case/morphcpu_case.stl](../case/morphcpu_case.stl), re-exported from the `.scad` and byte-identical to the committed file. volume by signed-tetrahedron sum over all 9,586 facets |
| floor slab (z 0-2.0 mm) | 8,707.51 mm³ | same mesh, intersected with the floor slab |
| wall ring (z 2.0-7.8 mm) | 2,711.66 mm³ | same, less the post footprints |
| four standoff posts | 208.30 mm³ | same, intersected with the post cylinders |
| extruded volume after infill | **10,410.40 mm³** | see the infill note |
| filament mass | **12.91 g** | × 1.24 g/cm³, standard PLA density |
| filament price | **$19.99/kg** | median 1 kg spool across ten manufacturers' own stores, 11 jun 2026. Overture's own store agrees: $20.99-22.99 list, $13.99-14.99 on sale |
| cost | $0.2580, so $0.26 | |

the 20% infill assumption barely applies to this part. at the print settings in
[../case/README.md](../case/README.md), 0.4 mm nozzle, 0.2 mm layers, 3
perimeters, three perimeters are 1.2 mm per side, so anything thinner than 2.4 mm
prints as solid perimeter with no infill region at all:

- wall, 2.4 mm: exactly two perimeter stacks. 100% solid
- standoff posts, 5.0 mm OD with a 1.7 mm pilot hole: outer and pilot shells overlap. 100% solid
- floor, 2.0 mm: 4 top + 4 bottom solid layers are 1.6 mm of the 2.0, leaving 0.4 mm at 20%, so the floor is 84% dense. the 1,100.81 mm³ annulus right under the wall is solid too

printed 100% solid the frame is 14.42 g and $0.29, three cents more. any infill
between 0% and 100% lands in that band so the case cost doesnt care about the
assumption. the old "~15 g, negligible" estimate was close

not counted, skirt, purge line, failed prints. usual rule of thumb adds abt 25%
which would push this line to $0.32

## why the fixed fees hurt

parts are $17.61/board but the fixed per-order fees are $110.09 across the whole
run, more than the entire BOM. moving both regulators to Basic helped, and
pinning the passives to Basic kept nine values off the feeder-fee list. whats
left Extended is the fixed cost. building 10 instead of 5 barely moves those fees
and roughly halves their per-unit share, if the budget ever allows

gerbers, BOM and CPL live in
[../hardware/fab_output/](../hardware/fab_output/) and are what the $203.47 quote
was generated from. re-quote if any of them change

## sources

- [ICE40UP5K-SG48I, LCSC C2678152](https://www.lcsc.com/product-detail/C2678152.html)
- [FT231XS-R, LCSC C132160](https://www.lcsc.com/product-detail/C132160.html)
- [FT231XS-U, LCSC C89607](https://www.lcsc.com/product-detail/C89607.html) (out of stock, dont use)
- [W25Q32JVSSIQ, LCSC C179173](https://www.lcsc.com/product-detail/C179173.html)
- [TYPE-C-31-M-12, LCSC C165948](https://www.lcsc.com/product-detail/C165948.html)
- [1532H4-16000JWPDTSNL, LCSC C5383161](https://www.lcsc.com/product-detail/C5383161.html)
- [AP2112K-3.3TRG1, LCSC C51118](https://www.lcsc.com/product-detail/C51118.html)
- [ME6211C12M5G-N, LCSC C236672](https://www.lcsc.com/product-detail/C236672.html)
- [KT-0603R, LCSC C2286](https://www.lcsc.com/product-detail/C2286.html)
- [USBLC6-2SC6, LCSC C7519](https://www.lcsc.com/product-detail/C7519.html)
- [TS-1187A-B-A-B, LCSC C318884](https://www.lcsc.com/product-detail/C318884.html)
- [CL05B104KO5NNNC, LCSC C1525](https://www.lcsc.com/product-detail/C1525.html)
- [CL05A105KA5NQNC, LCSC C52923](https://www.lcsc.com/product-detail/C52923.html)
- [CL05A475MP5NRNC, LCSC C23733](https://www.lcsc.com/product-detail/C23733.html)
- [CL05A106MQ5NUNC, LCSC C15525](https://www.lcsc.com/product-detail/C15525.html)
- [0402WGF1000TCE, LCSC C25076](https://www.lcsc.com/product-detail/C25076.html)
- [RC0402FR-07270RL, LCSC C163474](https://www.lcsc.com/product-detail/C163474.html)
- [0402WGF1001TCE, LCSC C11702](https://www.lcsc.com/product-detail/C11702.html)
- [0402WGF5101TCE, LCSC C25905](https://www.lcsc.com/product-detail/C25905.html)
- [0402WGF1002TCE, LCSC C25744](https://www.lcsc.com/product-detail/C25744.html)
- [0402WGF1003TCE, LCSC C25741](https://www.lcsc.com/product-detail/C25741.html)
- [BSMD1206-050-6V, LCSC C883122](https://www.lcsc.com/product-detail/C883122.html)
- [MMZ1608Y601BTA00, LCSC C136491](https://www.lcsc.com/product-detail/Ferrite-Beads_TDK_C136491.html)
- [PLA filament price per gram and per kg, 11 jun 2026, 3DPCC](https://3dprintingcostcalculator.com/news/filament-price-per-gram)
- [Overture PLA filament store listing](https://www.overture3d.com/collections/pla-filament)
- [JLCPCB parts library, tier and category listings](https://jlcpcb.com/parts)
- [JLCPCB PCBA price breakdown](https://jlcpcb.com/help/article/pcb-assembly-price)
- [iCE40 UltraPlus Family Data Sheet FPGA-DS-02008](https://www.latticesemi.com/-/media/LatticeSemi/Documents/DataSheets/iCE/iCE40-UltraPlus-Family-Data-Sheet.ashx)

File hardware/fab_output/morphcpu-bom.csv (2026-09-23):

Designator | Quantity | MPN | Comment | Footprint | LCSC Part #
C1,C2,C3,C4,C5,C6,C7,C8,C9,C19,C20,C21 | 12 | CL05B104KO5NNNC | 100n | Capacitor_SMD:C_0402_1005Metric | C1525
C10,C18 | 2 | CL05A106MQ5NUNC | 10u | Capacitor_SMD:C_0402_1005Metric | C15525
C11,C12,C13,C14 | 4 | CL05A475MP5NRNC | 4u7 | Capacitor_SMD:C_0402_1005Metric | C23733
C15,C16,C17 | 3 | CL05A105KA5NQNC | 1u | Capacitor_SMD:C_0402_1005Metric | C52923
D1,D2,D3,D4,D5,D6,D7,D8,D9,D10,D11,D12,D13,D14,D15,D16,D17 | 17 | KT-0603R | KT-0603R | LED_SMD:LED_0603_1608Metric | C2286
F1 | 1 | BSMD1206-050-6V | 500mA | Fuse:Fuse_1206_3216Metric | C883122
FB1,FB2 | 2 | MMZ1608Y601BTA00 | 600R@100M | Inductor_SMD:L_0603_1608Metric | C136491
J1 | 1 | TYPE-C-31-M-12 | TYPE-C-31-M-12 | Connector_USB:USB_C_Receptacle_HRO_TYPE-C-31-M-12 | C165948
R1,R2,R3,R4,R5,R6,R7,R8,R9,R10,R11,R12,R13,R14,R15,R16 | 16 | RC0402FR-07270RL | 270 | Resistor_SMD:R_0402_1005Metric | C163474
R17,R18,R19,R20,R21,R28,R29,R30 | 8 | 0402WGF1002TCE | 10k | Resistor_SMD:R_0402_1005Metric | C25744
R22 | 1 | 0402WGF1001TCE | 1k | Resistor_SMD:R_0402_1005Metric | C11702
R23,R24 | 2 | 0402WGF5101TCE | 5k1 | Resistor_SMD:R_0402_1005Metric | C25905
R25 | 1 | 0402WGF1003TCE | 100k | Resistor_SMD:R_0402_1005Metric | C25741
R26 | 1 | 0402WGF1004TCE | 1M | Resistor_SMD:R_0402_1005Metric | C26083
R27 | 1 | 0402WGF1000TCE | 100 | Resistor_SMD:R_0402_1005Metric | C25076
SW1 | 1 | TS-1187A-B-A-B | TS-1187A-B-A-B | Button_Switch_SMD:SW_Push_1P1T_XKB_TS-1187A | C318884
U1 | 1 | ICE40UP5K-SG48I | ICE40UP5K-SG48I | Package_DFN_QFN:QFN-48-1EP_7x7mm_P0.5mm_EP5.6x5.6mm | C2678152
U2 | 1 | FT231XS-R | FT231XS-R | Package_SO:SSOP-20_3.9x8.7mm_P0.635mm | C132160
U3 | 1 | W25Q32JVSSIQ | W25Q32JVSSIQ | Package_SO:SOIC-8_5.3x5.3mm_P1.27mm | C179173
U4 | 1 | AP2112K-3.3TRG1 | AP2112K-3.3TRG1 | Package_TO_SOT_SMD:SOT-23-5 | C51118
U5 | 1 | ME6211C12M5G-N | ME6211C12M5G-N | Package_TO_SOT_SMD:SOT-23-5 | C236672
U6 | 1 | USBLC6-2SC6 | USBLC6-2SC6 | Package_TO_SOT_SMD:SOT-23-6 | C7519
X1 | 1 | 1532H4-16000JWPDTSNL | 1532H4-16000JWPDTSNL | Oscillator:Oscillator_SMD_Abracon_ASE-4Pin_3.2x2.5mm | C5383161

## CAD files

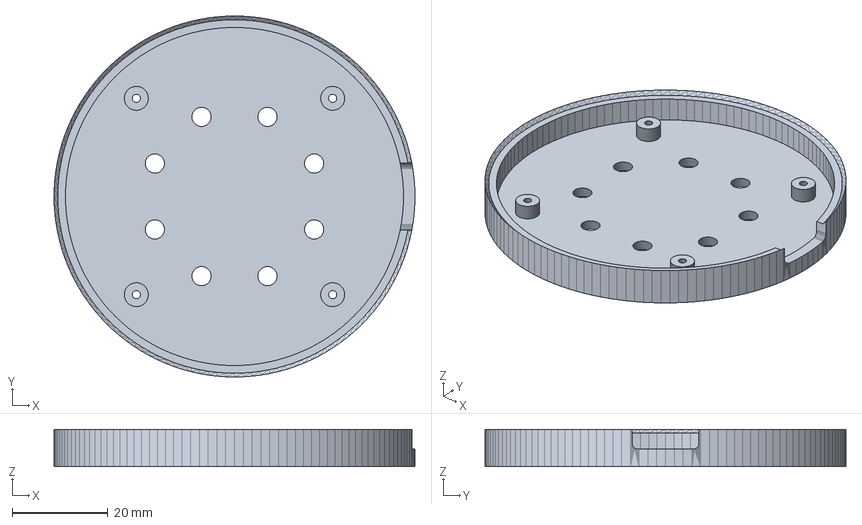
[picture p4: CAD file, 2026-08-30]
case/morphcpu_case.step
75.4 x 75.4 x 7.80 mm

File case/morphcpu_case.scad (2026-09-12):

/* [Board - set these from the finished PCB] */

pcb_dia = 70.0;
pcb_thickness = 1.6;
mount_hole_r = 29.0;
mount_hole_count = 4;
mount_hole_angle_offset = 45;
usb_angle = 0;

/* [Fit and wall] */

fit_clearance = 0.3;
wall = 2.4;
floor_thickness = 2.0;
standoff_height = 3.0;
rim_height = 1.2;

/* [Fasteners] */

screw_pilot_dia = 1.7;
standoff_dia = 5.0;
screw_depth = 5.0;

/* [Cutouts] */

usb_cutout_w = 10.0;
usb_cutout_h = 4.6;
usb_z_centre = 1.2;

usb_relief_w = 14.0;

/* [Cosmetic] */

top_chamfer = 0.8;
vent_holes = true;
vent_hole_dia = 4.0;
vent_ring_r = 18.0;
vent_count = 8;

/* [Render] */

part = "frame";

$fn = 128;

pocket_dia   = pcb_dia + 2 * fit_clearance;
outer_dia    = pocket_dia + 2 * wall;
pcb_z        = floor_thickness + standoff_height;
total_h      = pcb_z + pcb_thickness + rim_height;
eps          = 0.01;

module at_mount_holes() {
    for (i = [0 : mount_hole_count - 1]) {
        a = mount_hole_angle_offset + i * (360 / mount_hole_count);
        rotate([0, 0, a])
            translate([mount_hole_r, 0, 0])
                children();
    }
}

module body() {
    difference() {
        cylinder(h = total_h, d = outer_dia);

        translate([0, 0, total_h - top_chamfer])
            cylinder(h = top_chamfer + eps,
                     d1 = outer_dia - 2 * top_chamfer,
                     d2 = outer_dia + 2 * eps);
    }
}

module board_pocket() {
    translate([0, 0, floor_thickness])
        cylinder(h = total_h, d = pocket_dia);
}

module standoffs() {
    at_mount_holes()
        cylinder(h = pcb_z, d = standoff_dia);
}

module standoff_holes() {
    at_mount_holes()
        translate([0, 0, pcb_z - screw_depth])
            cylinder(h = screw_depth + eps, d = screw_pilot_dia);
}

module usb_cutout() {
    z = pcb_z + pcb_thickness + usb_z_centre;
    rotate([0, 0, usb_angle]) {
        translate([outer_dia / 2, 0, z])
            rotate([0, 90, 0])
                translate([0, 0, -wall * 2])
                    linear_extrude(height = wall * 4)
                        offset(r = 0.8, $fn = 32)
                            square([usb_cutout_h - 1.6, usb_cutout_w - 1.6],
                                   center = true);

        translate([outer_dia / 2 - wall / 2, 0, z])
            rotate([0, 90, 0])
                translate([0, 0, -wall])
                    linear_extrude(height = wall * 2)
                        offset(r = 1.2, $fn = 32)
                            square([usb_cutout_h + 1.2, usb_relief_w - 2.4],
                                   center = true);
    }
}

module vents() {
    if (vent_holes) {
        for (i = [0 : vent_count - 1]) {
            a = i * (360 / vent_count) + (360 / vent_count) / 2;
            rotate([0, 0, a])
                translate([vent_ring_r, 0, -eps])
                    cylinder(h = floor_thickness + 2 * eps, d = vent_hole_dia);
        }
    }
}

module frame() {
    difference() {
        union() {
            difference() {
                body();
                board_pocket();
            }
            standoffs();
        }
        standoff_holes();
        usb_cutout();
        vents();
    }
}

module mock_pcb() {
    color("#1b6b3a")
        difference() {
            translate([0, 0, pcb_z])
                cylinder(h = pcb_thickness, d = pcb_dia);
            at_mount_holes()
                translate([0, 0, pcb_z - eps])
                    cylinder(h = pcb_thickness + 2 * eps, d = 2.2);
        }

    led_pitch = 9.0;
    color("#d94f2b")
        for (r = [0 : 3], c = [0 : 3])
            translate([(c - 1.5) * led_pitch,
                       (1.5 - r) * led_pitch,
                       pcb_z + pcb_thickness])
                cube([1.6, 0.8, 0.6], center = true);
}

if (part == "frame")         frame();
else if (part == "assembly") { frame(); mock_pcb(); }
else if (part == "pcb")      mock_pcb();
else                         frame();

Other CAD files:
case/morphcpu_case.3mf
case/morphcpu_case.stl

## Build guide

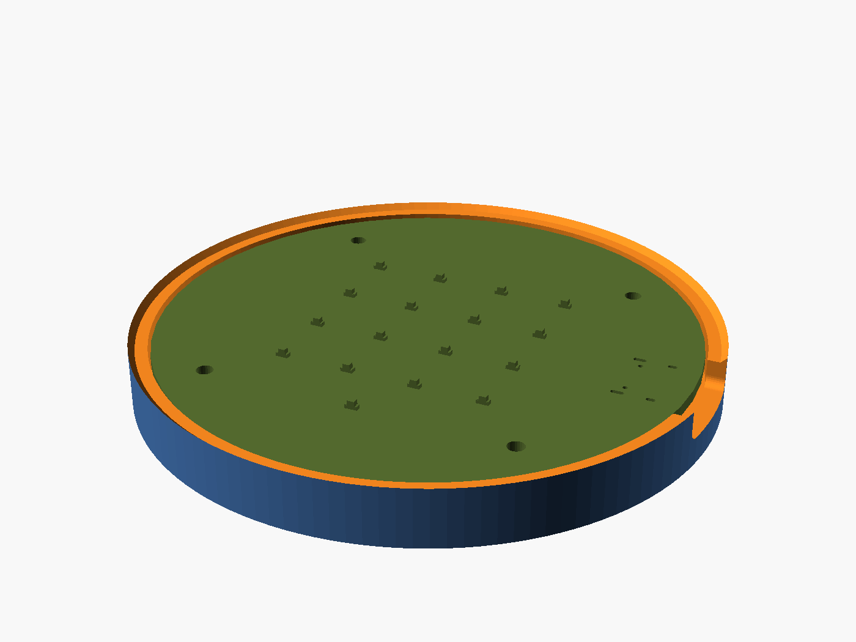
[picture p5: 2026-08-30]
docs/img/case-pcb-assembly.png

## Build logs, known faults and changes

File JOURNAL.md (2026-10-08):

# morphcpu build journal

**Total time: 53h estimated**

It's a spatially reconfigurable processor on a small, low-power FPGA. I revised
the total from 151h to 53h for the Forge payout. I don't have timer records for
each session, so the 15 session figures below are approximate shares of the
revised total.

I spent most of that time getting the power-up sequence right and routing a QFN-48
on 0.5 mm pitch. The fanout turned out to have less room than it needed.

Session dates are when the commits landed, not when I did the work. Six landed on
the same evening, but the work didnt, so dont use those dates to divide up the
hours. The entry template is in [docs/journal-template.txt](docs/journal-template.txt).

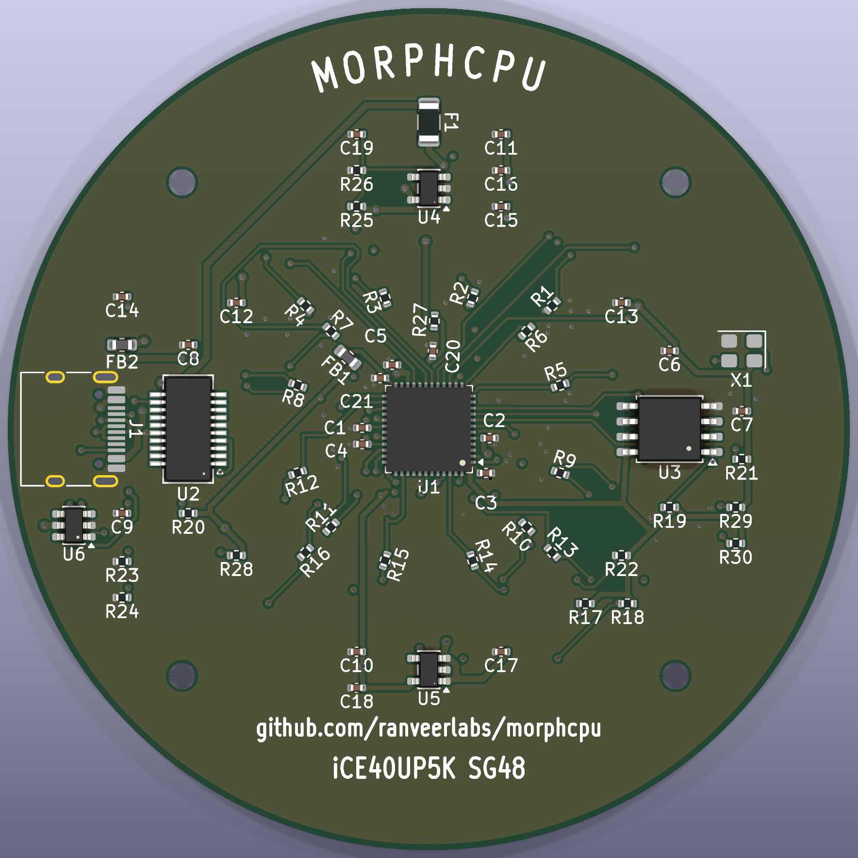
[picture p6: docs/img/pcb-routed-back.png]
board back, copper down round the fpga


As of the 18 Sep KiCad check, the board had 546 tracks and 193 vias, with 0 DRC
violations, 0 unconnected items and 0 schematic mismatches.

| # | date | time | focus |
|---|---|---|---|
| 001 | 2026-08-18 | 1h estimated | repo + scaffolding |
| 002 | 2026-08-18 | 5h estimated | fabric rtl + fabric testbench |
| 003 | 2026-08-18 | 4h estimated | end to end uart testbench, build flow, constraints |
| 004 | 2026-08-18 | 3h estimated | case, parametric cad |
| 005 | 2026-08-18 | 5h estimated | electrical design spec + bom |
| 006 | 2026-08-18 | 1h estimated | readme restructure |
| 007 | 2026-08-22 | 7h estimated | datasheet items closed, schematic, pcb placement |
| 008 | 2026-08-28 | 9h estimated | 4 layers, first copper, 0 violations |
| 009 | 2026-08-30 | 8h estimated | fanout was full, six pins moved |
| 010 | 2026-08-30 | 1h estimated | ldo went out of stock, en divider was wrong |
| 011 | 2026-08-30 | 1h estimated | silkscreen, the board had none |
| 012 | 2026-09-06 | 1h estimated | seeed instead of jlc, bom had no qty column |
| 013 | 2026-09-06 | 3h estimated | decoupling was spread out, six of seven pins fixed |
| 014 | 2026-09-12 | 1h estimated | build workflow, bitstream results, licence and docs |
| 015 | 2026-09-22 | 3h estimated | closed the last two LED nets, cleaned routing and regenerated fab files |

---

## session 015 - 2026-09-22

**Time spent:** 3h estimated
**Running total:** 53h estimated

This is an estimate. I backfilled it without a timer.

I moved LED1 from U1 pin 3 to pin 45 and LED2 from pin 23 to pin 42. The source
netlist, schematic, board and PCF now agree. Both routes leave the FPGA to the
south, then reach the resistor ring on the inner layers. That closes the two LED
connections left open in session 014.

I cleaned up short steps, overlapping track ends and the loop around C20. That
took the board from 769 tracks and 188 vias to 546 tracks and 193 vias. I widened
the remaining 0.15 mm and 0.1874 mm tracks to 0.20 mm, then raised the Board
Setup minimum track width from 0.127 mm to 0.1524 mm to meet the 6 mil requirement.
With zones refilled, KiCad 10.0.5 reported 0 violations, 0 unconnected items and
0 schematic mismatches on 18 Sep. ERC was clear too.

I regenerated the Gerber ZIP, BOM, CPL and board previews from the routed board.
The new pin map still needs a bitstream build. Windows Smart App Control blocked
`yosys-abc.exe`, then `libpcre2-8-0.dll`, during my local attempt, so the earlier
37.33 MHz result says nothing about these pin changes.

routed copper after the LED connections and cleanup
the two LED nets are closed in this board. the copper preview also shows the
shorter fanout and the routes into the resistor ring

---

## session 014 - 2026-09-12

Time spent: 1h estimated, backfilled without a timer
Running total: 50h estimated, including this estimate

added a GitHub Actions build with OSS CAD Suite pinned to 2026-09-12 on Ubuntu
24.04. it runs both testbenches, builds the bitstream and keeps the output and
logs for 30 days. removed --pcf-allow-unconstrained from the build, all 20 I/O
pins have to be assigned now. also fixed the utilisation grep for nextpnr's
whitespace

the [passing run](https://github.com/ranveerlabs/morphcpu/actions/runs/34678840307)
has 13/13 and 5/5 checks passing. the build used 2020/5280 logic cells and
routed at 37.33 MHz against the 16 MHz clock. morphcpu_top.bin is 104090 bytes.
those are build results, i still havent flashed a board

routed 3D view of the FPGA side the build targets

changed the licence to AGPL-3.0-only. removed explanatory comments from the
case, constraints and generator files, and documented the SaveBoard trap in
hardware/scripts/README.md: it can overwrite the project net classes and DRC
minimums, so gen_pcb.py saves those and restores them afterwards

updated the readmes and caught the old 770 tracks / 148 vias count still in
the root README. the board file has 769 tracks and 188 vias, already recorded
in session 013. no copper changed in this session. D2 and D3 are still open

---

## session 013 - 2026-09-06

**Time spent:** 3h estimated
**Running total:** 49h estimated

review came back on the layout, two things. decoupling caps too far from the
power pins, and inner layer signal with no clean ground return under it. the
first one turned out worse than the note said

the number that matters isnt straight line distance to the nearest cap, its the
copper path, and nobody had measured that. wrote a little dijkstra over the
tracks and pads to get it. pin 22 SPI_VCCIO1 was being decoupled by C12, which
sits under the FT231X on the far side of the board, 49.31mm away. pin 33 was
49.73mm to the same cap. pin 5 was 13.77mm. C4 and C5 were both dead end spurs
hanging off the west +3V3 trunk with an FPGA supply pin nowhere near either

cause is one line, gen_pcb.py had `ring(["C1","C2","C3","C4","C5","C20","C21"],
6.5, 10.0)` which drops seven caps evenly round a 6.5mm circle in refdes order.
so which cap ended up near which pin was whatever the alphabet decided. it looks
tidy in the 3d render and it means nothing electrically

| pin | rail | was | now |
|---|---|---|---|
| 1 | +3V3 VCCIO_2 | 3.23 mm | 1.16 mm |
| 5 | +1V2 VCC | 13.77 mm | 1.12 mm |
| 22 | +3V3 SPI_VCCIO1 | 49.31 mm | 1.98 mm |
| 24 | +3V3 VPP_2V5 | 1.99 mm | 1.13 mm |
| 29 | VCCPLL | 7.06 mm | 7.06 mm |
| 30 | +1V2 VCC | 3.24 mm | 1.47 mm |
| 33 | +3V3 VCCIO_0 | 49.73 mm | 1.62 mm |

the east face is where the actual work was. pins 29 30 and 33 all escape east
and the fanout at x 154-157 is full, LED3 LED11 LED15 UART_TX_O and CLK all
diving to inner layers in the same 3mm of board. first few attempts put the caps
hard against the pad row at x=155.04 and every single one of them collided with
something. what fixed it was giving up 0.5mm and going to x=155.5375, at which
point LED11 clears C20 by 0.59mm, LED15's existing via sits 0.279mm off C1, and
UART clears C4 by 0.464mm. so three of the five nets i was fully prepared to
rip up didnt need touching at all. left them exactly as hand routed

C4 crossed the whole board to get to pin 33 and took its 11.2mm west dead end
spur with it, which turned out to be the thing that had C2 stuck. C2's ground
pad was sitting on a 1.58mm2 scrap of B.Cu pour walled off by that spur, with no
room for a via anywhere inside it. i checked every 0.05mm position in the island,
zero fit. spur gone, C2 has 251 valid placements and lands 1.12mm off pin 5

pin 29 is the one that didnt happen. VCCPLL still sits 7.06mm out and thats
staying. LED3's only layer transition pocket is x 154.6-155.3, y 98.2-98.8,
which is exactly where C20's pad has to go, and LED3 cant go up either, a via
between LED10 at 97.25 and LED3 at 98.25 needs 0.6mm clear of both centres and
theres 0.5mm of room. searched 582 positions where C20 physically fits with a
clear courtyard, none of them have a routable stub. its VCCPLL or LED3, pick one

second half of the review, the return paths. all four layers here are ground
pours with signal on them rather than dedicated planes, so In1 references F.Cu at
0.21mm and In2 references B.Cu at 0.21mm across the 1.065mm core. F.Cu is one
solid 3572mm2 island. B.Cu is in seven pieces. thats the whole problem in one
sentence, In1 sits at 88.1% covered and In2 at 60.0%

28 stitching vias at the island crossings, one either side, so the return has a
short hop through F.Cu instead of a detour. CRESET_B at 132.13,107.32 was going
16.27mm out of its way and FLASH_HOLD 15.11mm, both under 2mm now

| metric | value | notes |
|---|---|---|
| tracks / vias | 769 / 188 | was 770 / 148 |
| copper | 1473.5 mm | was 1492.3, the dead spurs were longer than the fixes |
| supply pins under 2mm | 6 of 7 | pin 29 is the one |
| cap gnd pad to nearest via | 0.50 mm | all seven, was 0.25 to 3.69 |
| In2 over unbroken pour | 62.1% | 60.0% before |
| DRC | 0 / 2 | 2 unrouted are the same LED nets as ever |

worth writing down that the coverage number barely moved, 70.4 to 72.0 overall.
i half expected the stitching to show up there and it cant, stitching vias dont
fill the voids, they shorten the detour round them. the metric that actually
moved is the crossing distances and thats not a percentage

also had the stitching loop happily placing vias *further* from a crossing than
the existing nearest ground anchor, which made about half of the first pass pure
decoration. it picks the first legal spot on an expanding radius search and i
never checked the result against what was already there. one line, only accept
if it beats the current anchor by 0.2mm. found it by reading the log and noticing
a via 2.4mm from a crossing that already had one at 1.95mm

last thing, regenerating fab_output dropped the Quantity and MPN columns off the
bom. gen_fab.py only asks kicad for Reference,Value,Footprint and the qty doesnt
even survive that, so the two columns added last session for seeed are hand work
that the generator doesnt know about. restored the committed csv and left it,
gerbers and cpl are regenerated off the current board

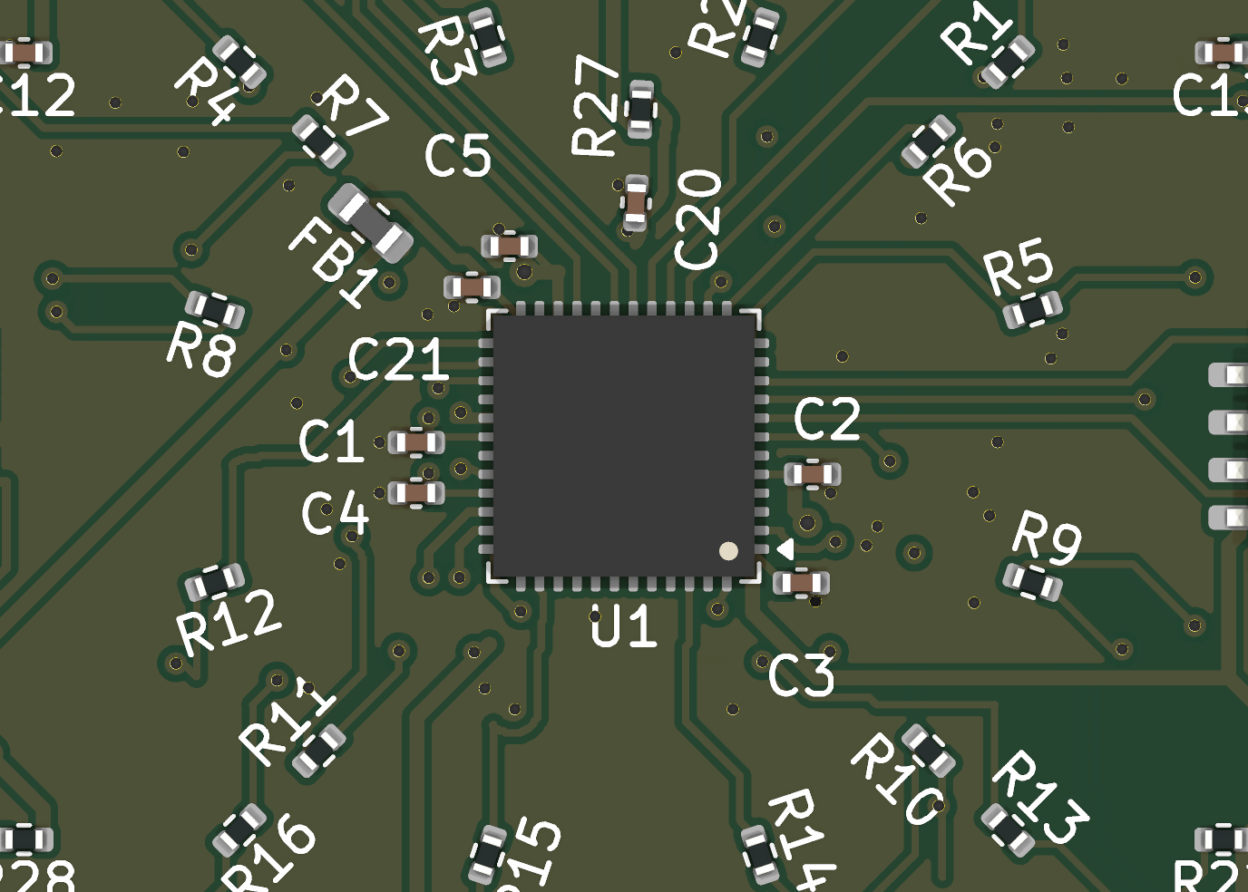
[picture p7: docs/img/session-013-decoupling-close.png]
the fpga and its decoupling, bottom view

bottom view so its mirrored, C1 and C4 on the left of the package are the east
side pins 30 and 33. C2 and C3 on the right are the west, pins 5 and 1. the one
to look at is C20 up at the top, still out at the old 6.5mm radius while every
other cap is tight on the package. thats the VCCPLL one that lost the argument
with LED3

next:
- [ ] re-quote the whole thing at seeed, 5 boards assembled, replace the JLC
      table in docs/BOM.md
- [ ] VCCPLL only gets a local cap if LED3 moves, and LED3 only moves if the
      north east corner gets rethought. worth a pass before ordering

---

## session 012 - 2026-09-06

**Time spent:** 1h estimated
**Running total:** 46h estimated

fab is seeed now instead of JLC. their uploader threw a quantity parse error on
hardware/fab_output/morphcpu-bom.csv and the cause was dumber than anything i was
looking for, the file has four columns, Designator Comment Footprint and LCSC
Part #, and no quantity column at all. kicad's grouped export leaves the count
inside the designator list and nowhere else. i went thru units and floats and
merged cells first before actually reading the header row

quantity is column 2 now, counted off the designator field per row. 23 rows, 80
parts a board, same 80 thats already in docs/BOM.md so the two agree. no part
number footprint or LCSC code moved, still CRLF

second bounce off the same file, "The column of MPN is empty". seeed wants real
manufacturer part numbers, an LCSC code on its own isnt enough for them the way
it is for JLC. every MPN was already sitting in docs/BOM.md against its C number
so that was a lookup, not a decision. MPN is column 3 now, all 23 rows filled,
CL05B104KO5NNNC for the 100n and 0402WGF1002TCE for the 10k and so on

no manufacturer column. i can guess most of them off the part numbers and a
guessed manufacturer on a real order is how you get the wrong part, seeed hasnt
asked for it yet either

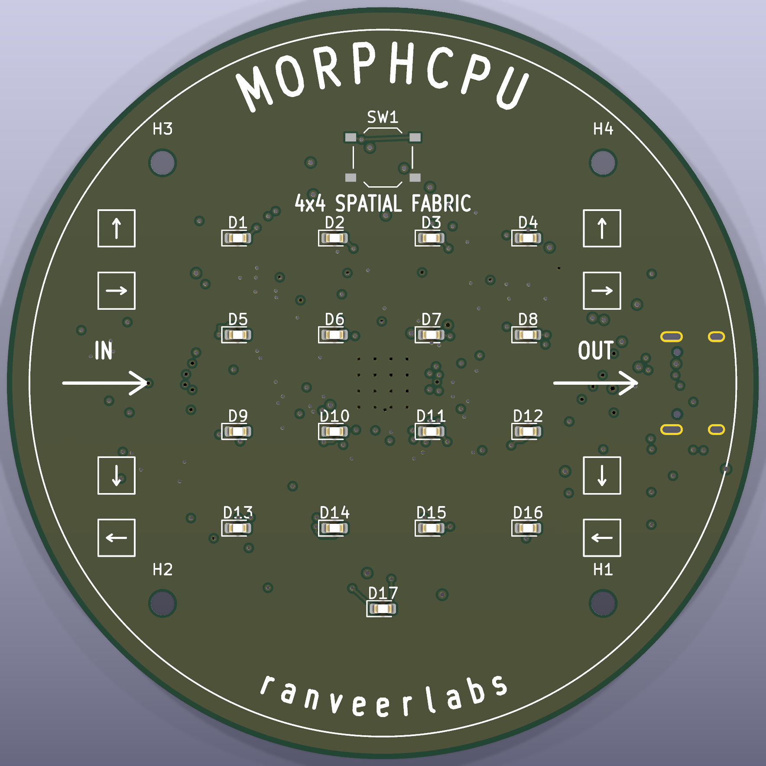
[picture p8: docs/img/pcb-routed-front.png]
the board the bom belongs to

theres nothing to screenshot in a csv so heres the front copper again. the bom
rows are exactly this, 23 lines standing in for 80 parts, and the count is only
checkable at all bcuz the designator lists are complete

docs/BOM.md is still written round JLC end to end, the $203.73 4 layer quote, the
$115.20 fab plus assembly gap, the stock and tier columns. all JLC numbers for a
board going to seeed and i havent re-quoted, so treat that table as stale

this is catch up. the seeed move plus a pile of small stuff that never got its
own commit, logging it here rather than pretending the hours went somewhere else

next:
- [ ] re-quote the whole thing at seeed, 5 boards assembled, replace the JLC
      table in docs/BOM.md

---

## session 011 - 2026-08-30

**Time spent:** 1h estimated
**Running total:** 45h estimated

the only graphic on this board was the edge cuts circle. no name no rev nothing,
which someone pointed out is going to read as unfinished next to the actual
requirement, "Round your corners, add silkscreen art, remove empty space from the
PCB". corners were never an issue cuz its a 70mm circle, the other two were

kicad has no curved text so the title is eight separate PCB_TEXT items placed
round r=29.7 with each one rotated to the tangent. front got that, a frame circle
at 32.9, IN and OUT arrows on the west and east lobes pointing the same way cuz
thats the direction data actually moves, and eight little boxed arrows in the two
side lobes for the four directions a cell can route

three things that didnt work first. a cartesian lattice of small squares in the
annulus, culled against every footprint, came out looking like debris rather than
a pattern, the culling breaks the grid up into clumps. then a ring of 16 cells,
one per fabric cell, which is the idea i wanted, except the M2 holes sit at r=29
and their bounding boxes reach in to r=25.5 so the diagonals are pinched between
those and the led grid corners at r=21.8. swept radius against placement count and
the best was 13 of 16 at r=31, and r=31 is where the title already is

```
gs 2.6 off 11.25  R 31.0 -> 13/16
gs 2.6 off 11.25  R 31.5 -> 13/16
gs 2.6 off 11.25  R 32.0 -> 13/16
```

third one was my own bug, i was culling front silk against every footprint
including the back ones, so half the glyphs vanished for parts that arent on that
side. only front footprints and anything with a through hole pad block front silk

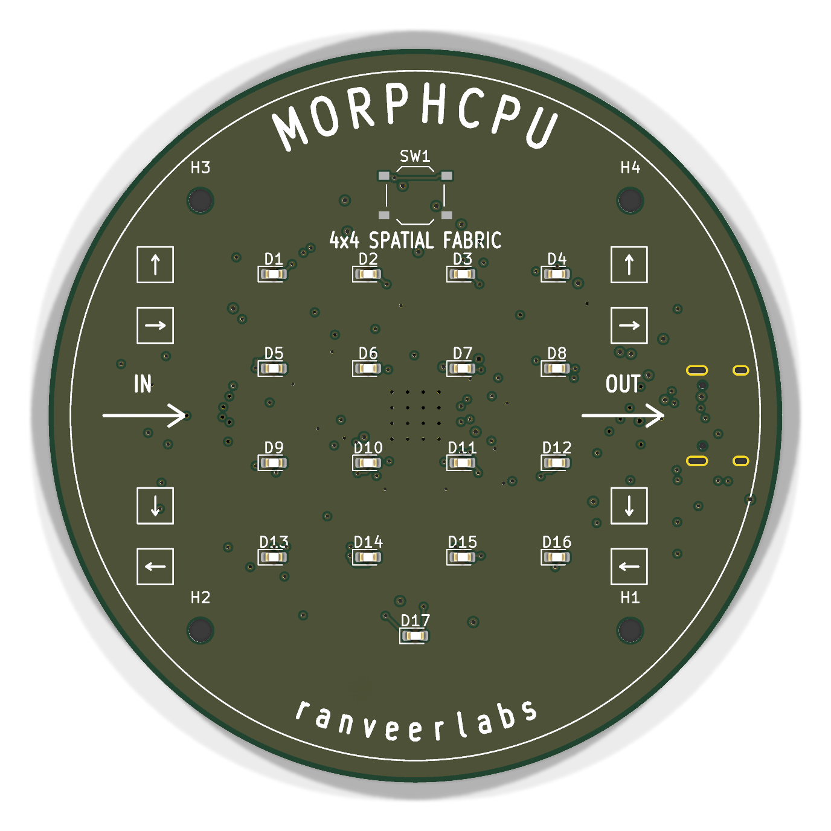
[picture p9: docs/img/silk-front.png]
front with the silkscreen on it


back arc came out UPCHPROM the first time. mirroring a layer flips the whole run
and not just each glyph so the string has to go in reversed. and the first back
pass threw 4 silk warnings, the frame circle crossed J1's outline at 182,95.3 and
182,104.7 and the full url arc ran its c and its t straight into the H3 and H4
NPTH pads. dropped the circle on that side and the url is straight text in the
bottom band now, arc up top is just the name

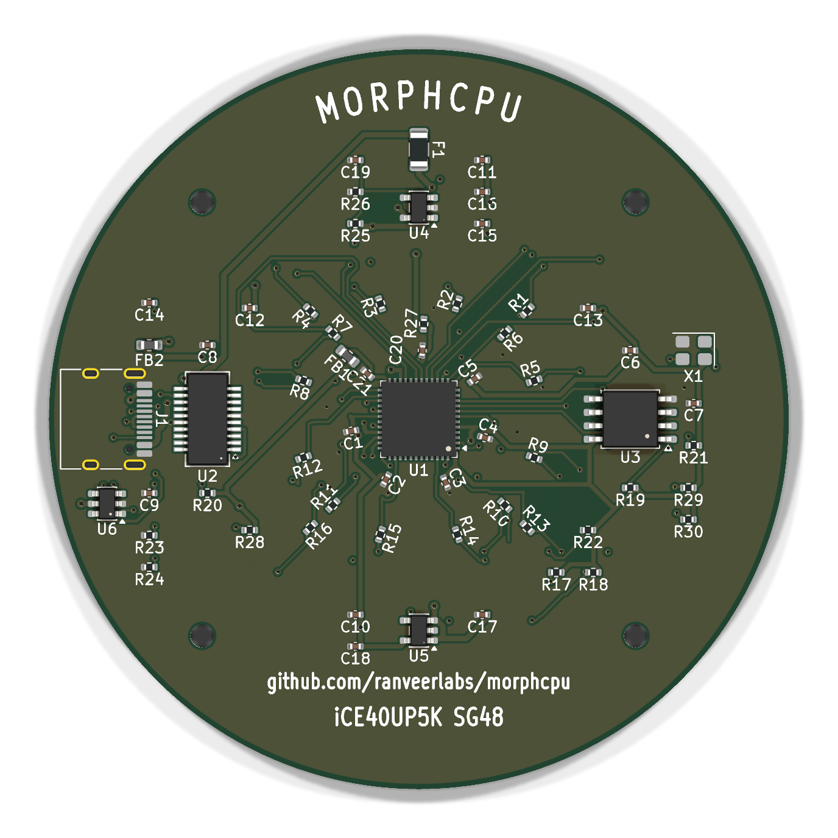
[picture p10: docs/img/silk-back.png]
back, url and part number in the bottom band


```
$ kicad-cli pcb drc --severity-all hardware/morphcpu.kicad_pcb
Found 0 violations
Found 2 unconnected items
```

same 2 open leds as before, no copper moved. the empty space one im leaving, the
components sit inside about 40mm and the board is 70 cuz the case is built round
70 and the led grid wants the room, shrinking it now means re routing the fanout
again with a week to go

rev A came back off the bottom band after. nothing in this project says the board
is rev A, sch_revision in the .kicad_pro is empty and theres never been an earlier
spin of it, so that line was a marking that said whatever i felt like rather than
anything true. url and the part number stay, those are both real

---

## session 010 - 2026-08-30

**Time spent:** 1h estimated
**Running total:** 44h estimated

C82942 hit 0 stock at JLC, 11 day lead and a 196 MOQ sitting behind it, so the
3V3 regulator is an AP2112K-3.3TRG1 now, C51118, 70,670 in stock. same SOT-23-5
and the same 1 VIN 2 GND 3 EN 4 NC 5 VOUT pinout so nothing on the board moved,
600 mA instead of 500. i couldnt get a tier out of JLC's listing for it, that
column came back Extended for every row i searched including parts that arent,
so idk, read it off the quote

then the actual find. the RC holding 3V3 off until 1V2 is up has a 100k feed and
what was a 10k bleed, and those two are a divider. EN sat at 5 x 10k/110k =
0.45 V, under the enable threshold of any LDO in this class, so the 3V3 rail
would never have come up at all. tau was 0.9ms not the 10ms this was documented
at, that number was 100k x 100n with the bleed left out of the sum. bleed is 1M
now, C26083

    EN  = 5 x 1M/1.1M              = 4.545 V
    tau = (100k || 1M) x 100n      = 9.09 ms

0402 to 0402 so no footprint moved. i checked rather than assumed, all 12 gerbers
came back identical to the previous plot once the creation dates are stripped

the fpga side
the back, and U1 actually renders now. the footprint asks for
QFN-48-1EP_7x7mm_P0.5mm_EP5.6x5.6mm.step and KiCad only ships the EP5.15x5.15mm
one, so the fpga was just absent from every 3D export. pointed at EP5.15, BOM and
CPL came back byte identical after, J1 SW1 and X1 are still missing models

```
$ kicad-cli sch erc --severity-all hardware/morphcpu.kicad_sch
Found 0 violations
$ kicad-cli pcb drc --severity-all hardware/morphcpu.kicad_pcb
Found 0 violations
Found 2 unconnected items
```

real 4 layer quote came back $203.73 all in, $40.75 a board, $6.27 under the
$210 cap. the old $198.41 was 2 layers. parts on their own are $88.27 and thats
already inside the JLC number, not on top of it

case has a STEP at last. FreeCAD 1.1.3, 3MF in, sew the mesh, solid out. closed,
75.4 x 75.4 x 7.8mm, 2621 faces, all of them triangles rather than real cylinders

next:
- [ ] move U3 north or move R2/R3, either takes the north fan under
- [ ] J1 SW1 X1 have no 3D models, only matters for renders

---

## session 009 - 2026-08-30

**Time spent:** 8h estimated
**Running total:** 43h estimated

seven connections would not route and every one of them had exactly one blocker,
which i only found out after fixing four bugs in my own router. it was rasterising
grid cells as half open squares in one function and as lattice points in the other
so every obstacle sat 0.025 mm off, and separately inflating obstacles by clearance
plus 0.01 mm when the tightest real clearances in this fanout are 0.2019 mm against
a 0.2 mm rule. that second one closes the channel it is measuring. hole to hole
checks were also reading the board's original track list which still had vias that
had just been ripped up, and a route's own vias never got checked against each
other so it happily put two holes 0.07 mm apart. with those four fixed the same
router went from reproducing nothing to reproducing every net already down

then the actual problem. a 0.6 mm via needs 1.2 mm between its neighbours and
adjacent escape rays on a 0.5 mm pitch QFN are 0.5 mm apart, so nothing can change
layer until the fan has spread, and U1's east column was carrying twelve nets on
twelve channels with four of them landing on the far side of the board. i tried the
staggered two row via fanout, which is the standard trick, and it fails the same
way, outer row's neck needs 1.2 mm between two inner vias and has 1.0 mm

so six pins moved instead. pads 37-48 were sitting completely unused

| Net | was | now |
|---|---|---|
| LED12 | 27 | 48 |
| LED9 | 23 | 9 |
| LED13 | 28 | 46 |
| LED14 | 31 | 38 |
| LED2 | 4 | 23 |
| LED3 | 11 | 27 |

LED12 LED13 LED14 went 42.0 / 36.1 mm and unroutable to 12.5 / 7.8 / 8.0 mm and
eleven of the twelve outstanding connections then routed with nothing ripped up.
netlist.py, the pcf and the DESIGN.md pin table all moved together, ERC still 0

board back after routing, copper fanning out of the QFN
the back after. QFN paddle in the middle with its via field, and the fan going out
in every direction, thats the bit that ran out of room

```
$ kicad-cli pcb drc --severity-all hardware/morphcpu.kicad_pcb
Found 0 violations
Found 2 unconnected items
```

LED1 and LED2 are the two, both route on their own, never together. moving LED1 to
pin 20 or 11 routes LED1 and opens LED7 or LED5 instead, the count just stays at
two whatever i do, so the north face is two nets past what it can fan out. leaving
it, cuz deadline. two of the sixteen grid leds dont light, everything else is
connected

fab_output replotted off the routed board while i was in there. gen_fab.py was
still on F.Cu,B.Cu from the 2 layer days so it had been dropping In1 and In2
entirely, which quotes fine and arrives dead

next:
- [ ] move U3 north or move R2/R3, either takes the north fan under
- [x] requote, $198.41 was 2 layers, the 4 layer number is $203.73

---

## session 008 - 2026-08-28

**Time spent:** 9h estimated
**Running total:** 35h estimated

went to 4 layers. 2 could not do it, the resistor ring and the decap ring both sit
inside the F.Cu keepout over the led grid so every led escape was stuck on B.Cu on
its own. In1 and In2 are signal layers now with GND pours on all four

freerouting got another go now that the keepout exists and the pours are filled and
it still isnt worth keeping. `-inc GND` does not exclude GND, it routes it anyway,
and with GND in the netlist a pass takes 462-494 s against ~30 s with the net block
deleted. it also ignores `(type fix)` on existing wiring, marking all 573 wires fix
gave a byte identical score to leaving them route, so you cant ask it to only fill
gaps. it stalled at 45-46 unrouted and 72 violations

wrote a grid maze router instead. 0.05 mm cells, 4 layers, 45 degrees, every
segment and via exact clearance checked against pcbnew geometry before it goes
down. got 167 unconnected pads to 7 across the pass

board front, the led grid side
front stays clean, thats the whole point of the F.Cu keepout over the grid. the
only copper on this face is the CDONE led and the reset button

the GND pours needed watching. three pads ended up in isolated B.Cu pour islands
with the main In1/In2/F planes running straight underneath, so what they needed was
one stitching via each and not a route at all

---

## session 007 - 2026-08-22

**Time spent:** 7h estimated
**Running total:** 26h estimated

closed all 8 open items in the design spec against the family datasheet + the
symbol lib. one citation each. full 48 pin table lives in the spec now

picked the oscillator and pushed the clock change through gateware, constraints,
build script. generated the schematic off the netlist transcription and erc came
back 0/0 with everything turned on which ngl i did not expect first try

generated first pass placement through the layout api. 79 footprints 90 nets
zero tracks zero courtyard overlaps zero shorting pads. then grew the board
60mm -> 70mm cuz it just did not fit, and followed that through the case params

both regulators run off 5v in parallel now with an rc delay on the 3v3 enable.
the obvious way is the cascade 5v -> 3v3 -> 1v2, simpler and one less rail off
usb, but the datasheet wants core + pll up first then the spi bank then the
programming rail, and the cascade brings 3v3 up first which is exactly
backwards. every 3v3 consumer sits after core in the ordering so the whole thing
collapses to one rule, 1v2 has to hit 0.5v before 3v3 shows up. thats in the
power up supply sequence section plus the bit listing which rails the on chip
reset actually watches. downside is the 3v3 reg now needs an enable pin which
killed the part id already picked, rip. running 1v2 straight off 5v burns
~114mw in a sot-23-5, abt a 28c rise, fine

went 16mhz on the oscillator instead of 12. the two 12mhz parts i looked at had
9 units and 1 unit in stock, and nothing actually depends on 12, so it wasnt
much of a call. stock of 9 is how you end up redesigning at the worst possible
moment. uart divisor goes 104 -> 139 so the error drops 0.16% ->
0.08%, got better by accident lol, and the tick divider got rescaled to hold 4hz

board went 60mm -> 70mm. could've stayed at 60 and packed tighter but 60 gave
courtyard overlaps + shorting pads that only cleared if you put parts on top of
the mounting holes, which isnt clearing them. cost two numbers in the case
source and a re export. more board area, cost is nothing

datasheets and parts i had open for this:

| part / doc | exact p/n or ref | what i needed |
|---|---|---|
| fpga | ICE40UP5K-SG48I | pin summary, rail voltages, io current ceiling, power up sequence |
| symbol lib | `ICE40UP5K-SG48ITR` | sg48 pin numbers |
| oscillator | 1532H4-16000JWPDTSNL | 16mhz, 1.8-3.3v, hcmos, tri state enable on pad 1 |
| 3v3 ldo | ME6211C33M5G-N | 500ma, has the enable pin the sequencing needs |
| 1v2 ldo | ME6211C12M5G-N | 300ma, same footprint as the 3v3 one |

numbers that came out of it:

| metric | value | notes |
|---|---|---|
| supply pins | 7 | 2 core 3 io bank 1 pll 1 programming. so 7x 100nf |
| dedicated gnd pins | **0** | ground only reaches the die thru the exposed paddle |
| led drive | 5ma of an 8ma ceiling | fine |
| schematic | 87 symbols 90 nets 257 pins | erc 0/0 |
| pcb | 79 footprints 0 tracks | 0 courtyard 0 shorting 0 clearance |
| board | 70mm dia 2 layer | grid 9mm pitch 27mm across |

schematic export died with "failed to load schematic" and literally nothing
else, no line no detail. the 1v2 symbol only extends the 3v3 one, so emitting
the parent body under the child name leaves the nested per unit sub symbols
still named after the parent and the file wont load. rename just those and it
loads, then trips a symbol mismatch check instead cuz the properties still
read as parent. fix is embedding the derived symbol fully flattened, one function

placement generator segfaulted, no traceback nothing. flipping a footprint that
wasnt added to the board yet. bindings dont check ownership they just die. fix
is adding to board then flipping it

first placement pass came back 87 violations incl pads shorting straight across
the fpga. id put the 16 led series resistors 3.2mm from each led which parked
the entire ring on top of the qfn in the middle of the board, and 60mm wasnt
enough area anyway. fix is moving the resistors out to a ring at r=11.5mm and
growing the board

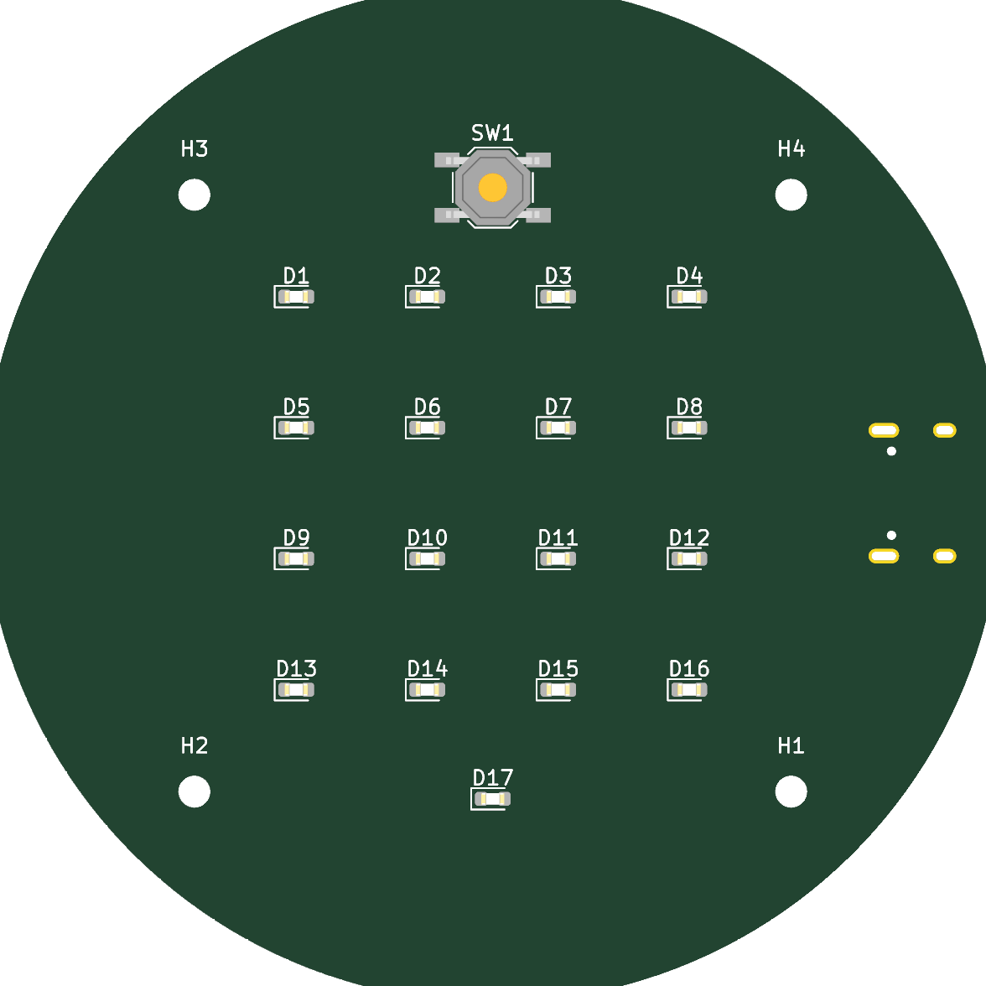
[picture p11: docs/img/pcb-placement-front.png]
board front

front face. 4x4 grid on a 9mm pitch owns the centre, nothing else allowed on
this side except the reset button and the done led

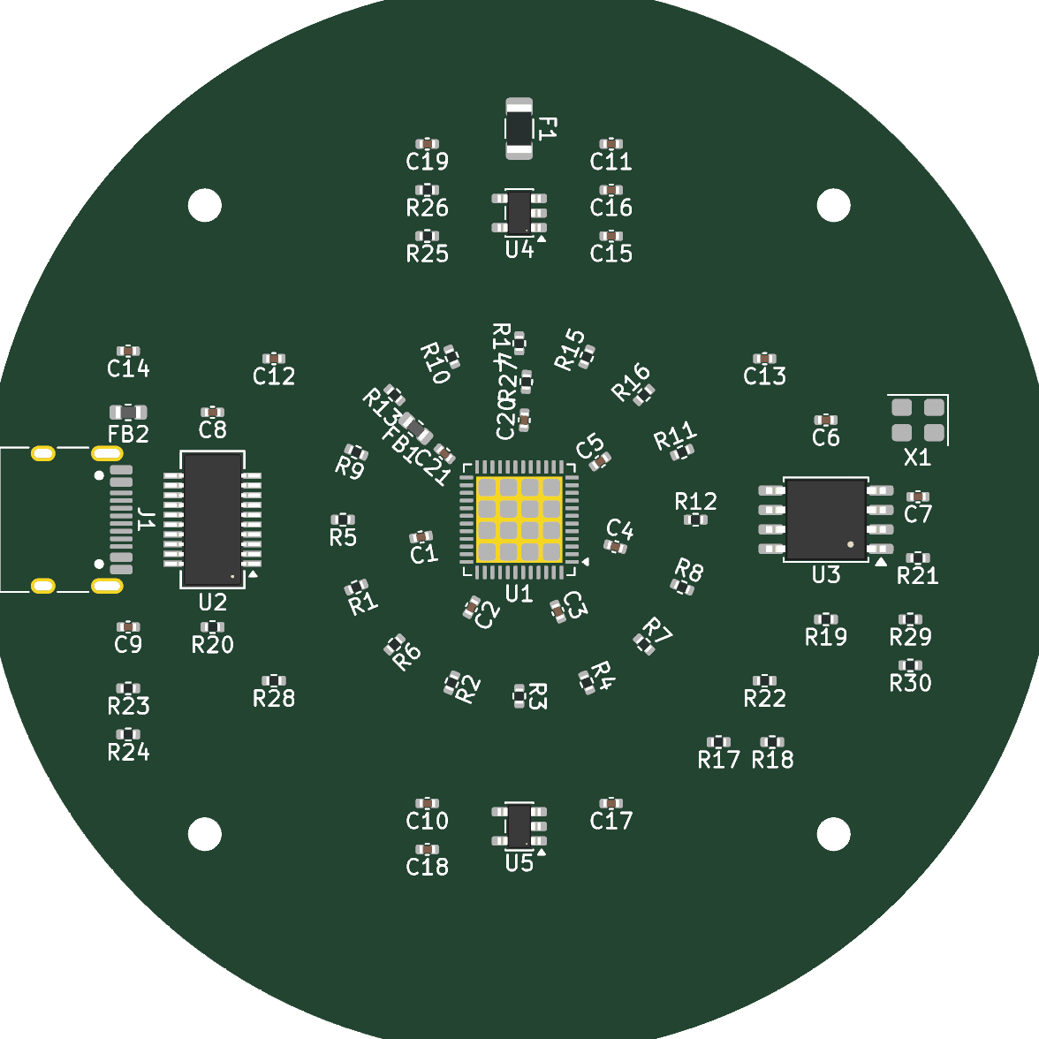
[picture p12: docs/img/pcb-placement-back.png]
board back

back face. rings around the fpga, decoupling innermost, anything with a real
body pushed past 17mm, diagonals empty for mounting holes

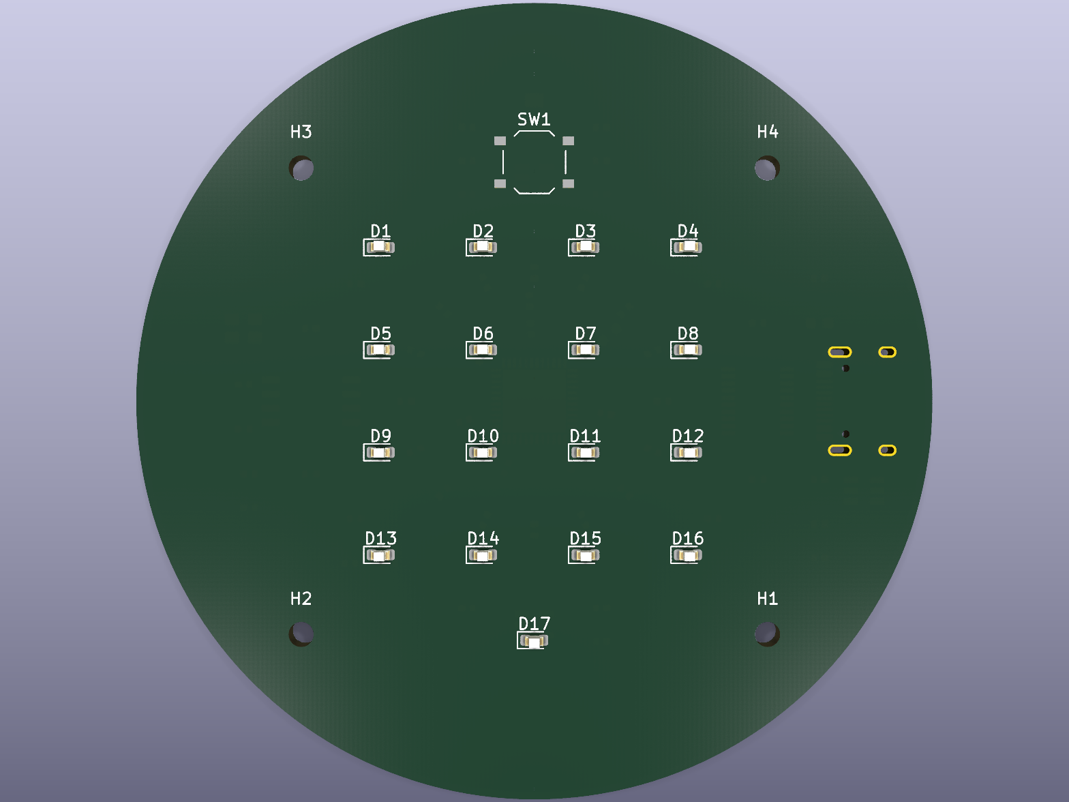
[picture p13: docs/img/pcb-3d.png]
3d render of the placement

same placement in 3d. worth the check, cell 0 top left thru 15 bottom right row
major so the physical grid reads the same as the fabric map. get that backwards
and the whole demo lies to you

next:
- [ ] route the board by hand
- [ ] work the post routing checklist at the bottom of the design spec

---

## session 006 - 2026-08-18

**Time spent:** 1h estimated
**Running total:** 19h estimated

ripped the project description and how-it-works section out of the readme, then
left notes to put them back. kept the tables, grid, commands, repo layout and
images because the submission rules allow those

mostly bookkeeping, but the rules change what can go in the readme. writing that
down now seemed easier than rediscovering it later

the image the readme leads with
this session only edited text so theres no artifact of its own. this is the
image the readme leads with, which is the point tbh, embeds and tables and part
numbers are exactly the stuff the rules do allow. the prose around it is what
had to come out

next:
- [ ] put the project description and how it works back in the readme
- [ ] check whether the same rule applies to the other docs

---

## session 005 - 2026-08-18

**Time spent:** 5h estimated
**Running total:** 18h estimated

wrote the design spec. power tree, net by net tables, decoupling per power pin
group, pcb brief, assembly notes, and 8 open datasheet items i couldnt close yet

wrote the bom for a 5 unit run. six parts verified w real stock, anything
unpinned listed with no price instead of a guess. added a polarity param to the
top level so the schematic can pick led orientation without touching gateware

the two below are the ones that mattered. this chip has no crystal amp, and the
obvious power cascade is backwards. both changed the parts list and tbh both are
things id have got wrong if id trusted the reference designs floating around
instead of just reading the datasheet

added two regulators that were not in the plan at all. running the fpga straight
off usb 5v is impossible, core is 1v2 and the io banks are 3v3, and usb-c gives
you 5v so nothing in the original parts list made either rail. idk how i just
didnt think about power. rail numbers are in the recommended operating
conditions table. costs two more parts

the clock is an active oscillator module not a bare crystal. options were a
passive crystal + load caps, or the internal osc which is free and zero parts
but abt ±10% untrimmed. theres no crystal amp on this family and no xin/xout
pair in this package so it physically cannot start a passive crystal, and 115200
tolerates abt ±2-3% total so ±10% wont enumerate reliably. the oscillator usage
guide says the family gives you the two on chip oscillators and nothing
external. so the part becomes a 4 pad module and the two load caps disappear.
still worth wiring the internal osc as a gateware fallback so an unpopulated
part doesnt brick the board

swapped the usb-uart bridge to the tape and reel variant. the tube packaged one
i originally specified was out of stock, and tube isnt what an assembly line
wants anyway. same silicon same footprint no pin changes, so functionally
nothing changes

datasheets and parts i had open for this:

| part / doc | exact p/n or ref | what i needed |
|---|---|---|
| fpga | ICE40UP5K-SG48I | rail voltages, programming rail range |
| usb-uart | FT231XS-R | packaging variant, footprint confirm |
| config flash | W25Q32JVSSIQ | pinout, quad mode pins to tie off |
| usb-c | TYPE-C-31-M-12 | pin map, cc pulldown requirement |
| led | KT-0603R | forward voltage 1.8-2.4v, brightness at 20ma |
| datasheet | family datasheet | rail voltages, programming rail range |
| tech note | oscillator usage guide | on chip oscillators only, no external crystal |

numbers that came out of it:

| metric | value | notes |
|---|---|---|
| led current | 5ma each, 80ma total | 270Ω from 3v3, vf abt 2.0v |
| open items | 8 | all pin count or rail voltage dependent |

couldnt read the datasheet pdf locally to confirm the exact supply pin counts,
no pdf tooling installed. so instead of guessing i left every pin count
dependent decoupling qty as an explicitly open item, 8 of them, all listed in
the spec. guessing here quietly propagates into the schematic and then you never
catch it

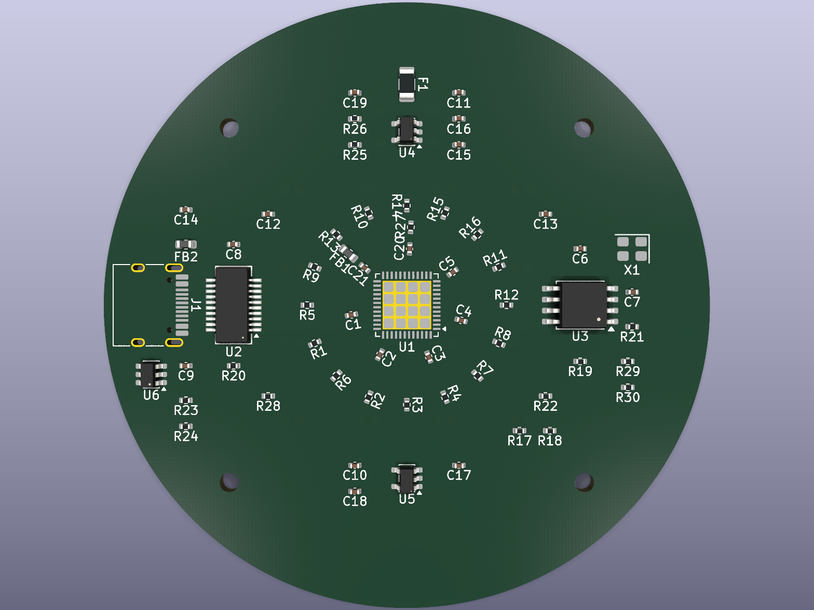
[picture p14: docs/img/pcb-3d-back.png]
board back, showing the parts this session picked

nothing visual existed this session, its all tables. this is the back of the
board from two sessions later, but its every part the power tree here settled
on, the two regulators, the flash, the oscillator and the bridge, sat where they
ended up. easier to check a parts list against a picture than against a netlist

next:
- [ ] close the 8 open datasheet items
- [ ] pick the osc and the 1v2 reg
- [ ] start the schematic

---

## session 004 - 2026-08-18

**Time spent:** 3h estimated
**Running total:** 13h estimated

wrote the case as parametric source. slim open face frame, four standoff posts,
usb-c cutout w an outer relief so a moulded plug boot clears the rim, eight
vents in the floor. exported mesh formats both manifold. export script
regenerates the exports + the preview renders in one go

open face, no lid, no light pipe. could've done a closed case with a window or a
light pipe array over the leds but the grid is the demo, and anything over it
costs brightness and adds an alignment problem for zero benefit. board front
ends up exposed which is fine for a desk object

every board derived dimension is a named param. the pcb didnt exist yet so all
seven board dims were assumptions, and parameterising them means the finished
layout is a seven number edit + re export instead of a remodel. only catch is i
have to actually remember to update them, so theyre a table in the case readme
where theyre hard to miss. paid off immediately in 007 when the board grew

numbers that came out of it:

| metric | value | notes |
|---|---|---|
| outside dia | 65.4mm | 60 board + 0.6 fit + 4.8 wall. now 75.4, board grew to 70 in 007 |
| height | 7.8mm | 2.0 floor + 3.0 standoff + 1.6 board + 1.2 rim |
| mesh | 4,769 verts / 9,582 facets | manifold genus 12 |

export to step failed with "invalid suffix step". this tool cannot export step
at all ever, its a mesh/csg modeller and step is a boundary rep format so theres
literally nothing to write out. fix is exporting mesh formats instead and
documenting the two real routes to a step file if one is ever needed, both in
the case readme

case with a mock board fitted
frame w a mock board dropped in. open face, board sits on four standoff posts,
3mm of air underneath for back side parts

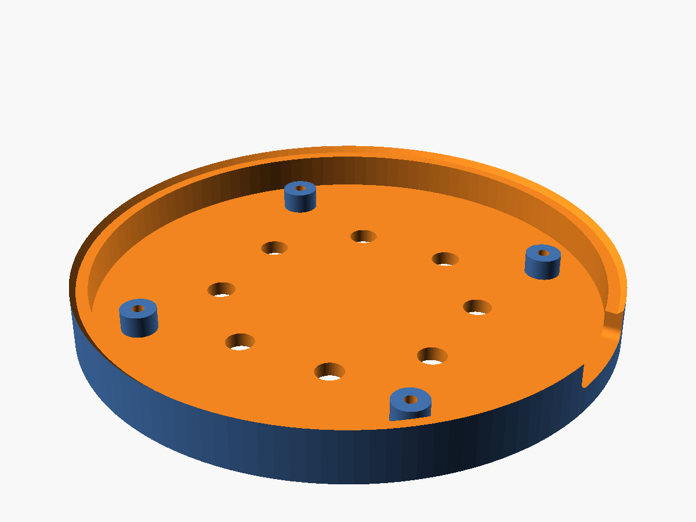
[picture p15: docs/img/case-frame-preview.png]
the printable frame on its own

printable part by itself. 2.4mm wall, eight lightening holes in the floor, no
lid no light pipe cuz the grid is meant to be looked at directly

next:
- [ ] update the seven board params once the outline is fixed
- [ ] test print, check the fit clearance

---

## session 003 - 2026-08-18

**Time spent:** 4h estimated
**Running total:** 10h estimated

wrote an end to end testbench that drives the design only thru its uart pins,
so it tests the wire protocol + the config bit packing not just the fabric. 5/5

wrote the sim runner, build script, pin constraints. wrote up the protocol table
and a worked add two numbers example that matches the testbench byte for byte

fabric tick defaults to 4hz not full clock rate. a hop every 83ns is invisible
and the board exists to be watched. tradeoff is that at full tick rate the
fabric outruns the serial link and results get dropped, which is exactly why the
single step command exists

numbers that came out of it:

| metric | value | notes |
|---|---|---|
| serial | 115200 8n1 | 0.16% divisor error at the clock i was on then |
| config chain | 64 bits | 16 cells x 4 bits |
| checks | 5/5 | end to end testbench |

end to end test timed out, no byte ever came back. thought it was config not
loading. was actually two bugs stacked which is why it took a while. the shift
enable was a registered output while the shift register shifted combinationally
so the enable lagged a cycle and the first config bit never got captured. and
the top level sampled the east edge on the tick edge itself which always caught
the pre tick state, one hop stale, so a result never latched. fix is making the
enable combinational and adding a one cycle delayed tick for sampling the edge

neither bug was visible to the fabric level testbench cuz that one drives the
config chain directly and reads the edge after the tick. good argument for
testing thru the real interface and not just the convenient one

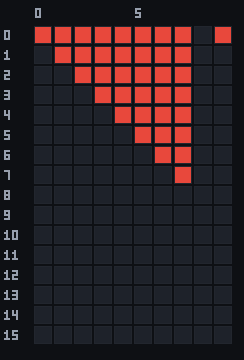
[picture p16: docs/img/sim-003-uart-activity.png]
led state through the end to end run, rendered from the sim dump

leds through the end to end run, every column is a state change. this one is
driven entirely over the serial link, nothing reaching into the hierarchy. fills
in as a triangle rather than a diagonal cuz the leds are pulse stretched to
~150ms so a single tick visit stays visible, so the trail hangs around. cells 0
thru 7 light in order which is the worked add example, 0 south into 4 then east
out thru 5 6 7

next:
- [ ] get the synth toolchain installed, run the build for real utilisation numbers

---

## session 002 - 2026-08-18

**Time spent:** 5h estimated
**Running total:** 6h estimated

wrote the whole fabric. the cell, the grid + neighbour interconnect, serial rx
and tx, config loader and tick gen, top level. then a fabric testbench, 13
checks, exact per tick latency, all four ops, both convergence cases, config
surviving a data clear, and the activity taps that drive the leds

a second converging stream is the alu's second operand. alternative was a fixed
neighbour operand or an immediate field in the config, but doing it this way
makes add and xor mean something spatially, two streams meeting in a cell get
combined, and it costs zero extra config bits. a lone stream falls back to
whatever the cell already holds which turns add into an accumulator for free.
operand order ends up depending on the fixed n,e,s,w priority scan so thats
documented and asserted in the testbench where it cant drift

config chain is wired highest cell index first. costs one crossed over wire
inside the fabric which is free, and makes the host byte order natural, byte i
holds cells 2i and 2i+1 ascending with nothing to reverse on either end

numbers that came out of it:

| metric | value | notes |
|---|---|---|
| grid | 4x4, 16 cells | 8 bit datapath |
| config | 4 bits/cell, 64 total | 2 op + 2 direction |
| checks | 13/13 | fabric testbench |

syntax error on a module header that looked completely valid. first thought was
something in the comment header, and backtick quoted words inside `//` comments
do get seen by the preprocessor and do break parsing, so that was a real
find, just not this bug. actual cause is that `cell` is a reserved word in
verilog-2001, belongs to the configuration construct. fix is renaming the
module. genuinely annoying to find

then every fabric test failed with nothing lighting up at all. testbench race,
not an rtl bug. stimulus was driven on the same rising edge the design samples
on so the tick got cleared before the design ever saw it. fix is all stimulus
changing on the falling edge

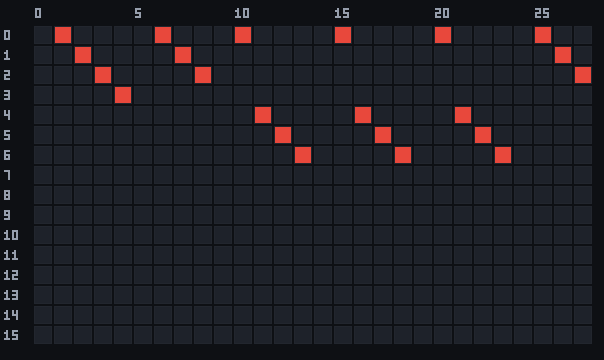
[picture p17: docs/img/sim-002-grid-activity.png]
activity taps over 28 ticks, rendered from the fabric testbench dump

the 16 activity taps, one row per cell, one column per tick. straight off the
sim dump w `vcd_png.js`. every diagonal streak is one value physically walking
east one cell per tick, 0 -> 1 -> 2 -> 3 along the top row and 4 -> 5 -> 6 along
the next. thats the idea in one picture. also the fastest way
to spot a routing bug, a value going the wrong way slopes the wrong direction

next:
- [ ] test thru the real serial interface not just the fabric ports

---

## session 001 - 2026-08-18

**Time spent:** 1h estimated
**Running total:** 1h estimated

initialised the repo, folder structure, readme skeleton, this journal, ignore
file. nothing interesting tbh. but starting the journal at 001 instead of
backfilling it later is lowk the only reason the rest of these entries have any
real detail in them

the finished board render, standing in for a session that made empty folders
being straight w you, this session produced empty directories and a gitignore.
theres nothing to photograph. so this is the board six sessions later, ie what
those folders ended up holding. gateware/ hardware/ case/ docs/ were all decided
here and none of them moved after, which is the only reason this entry is worth
keeping at all

next:
- [ ] define the cell opcode + routing direction encoding

---

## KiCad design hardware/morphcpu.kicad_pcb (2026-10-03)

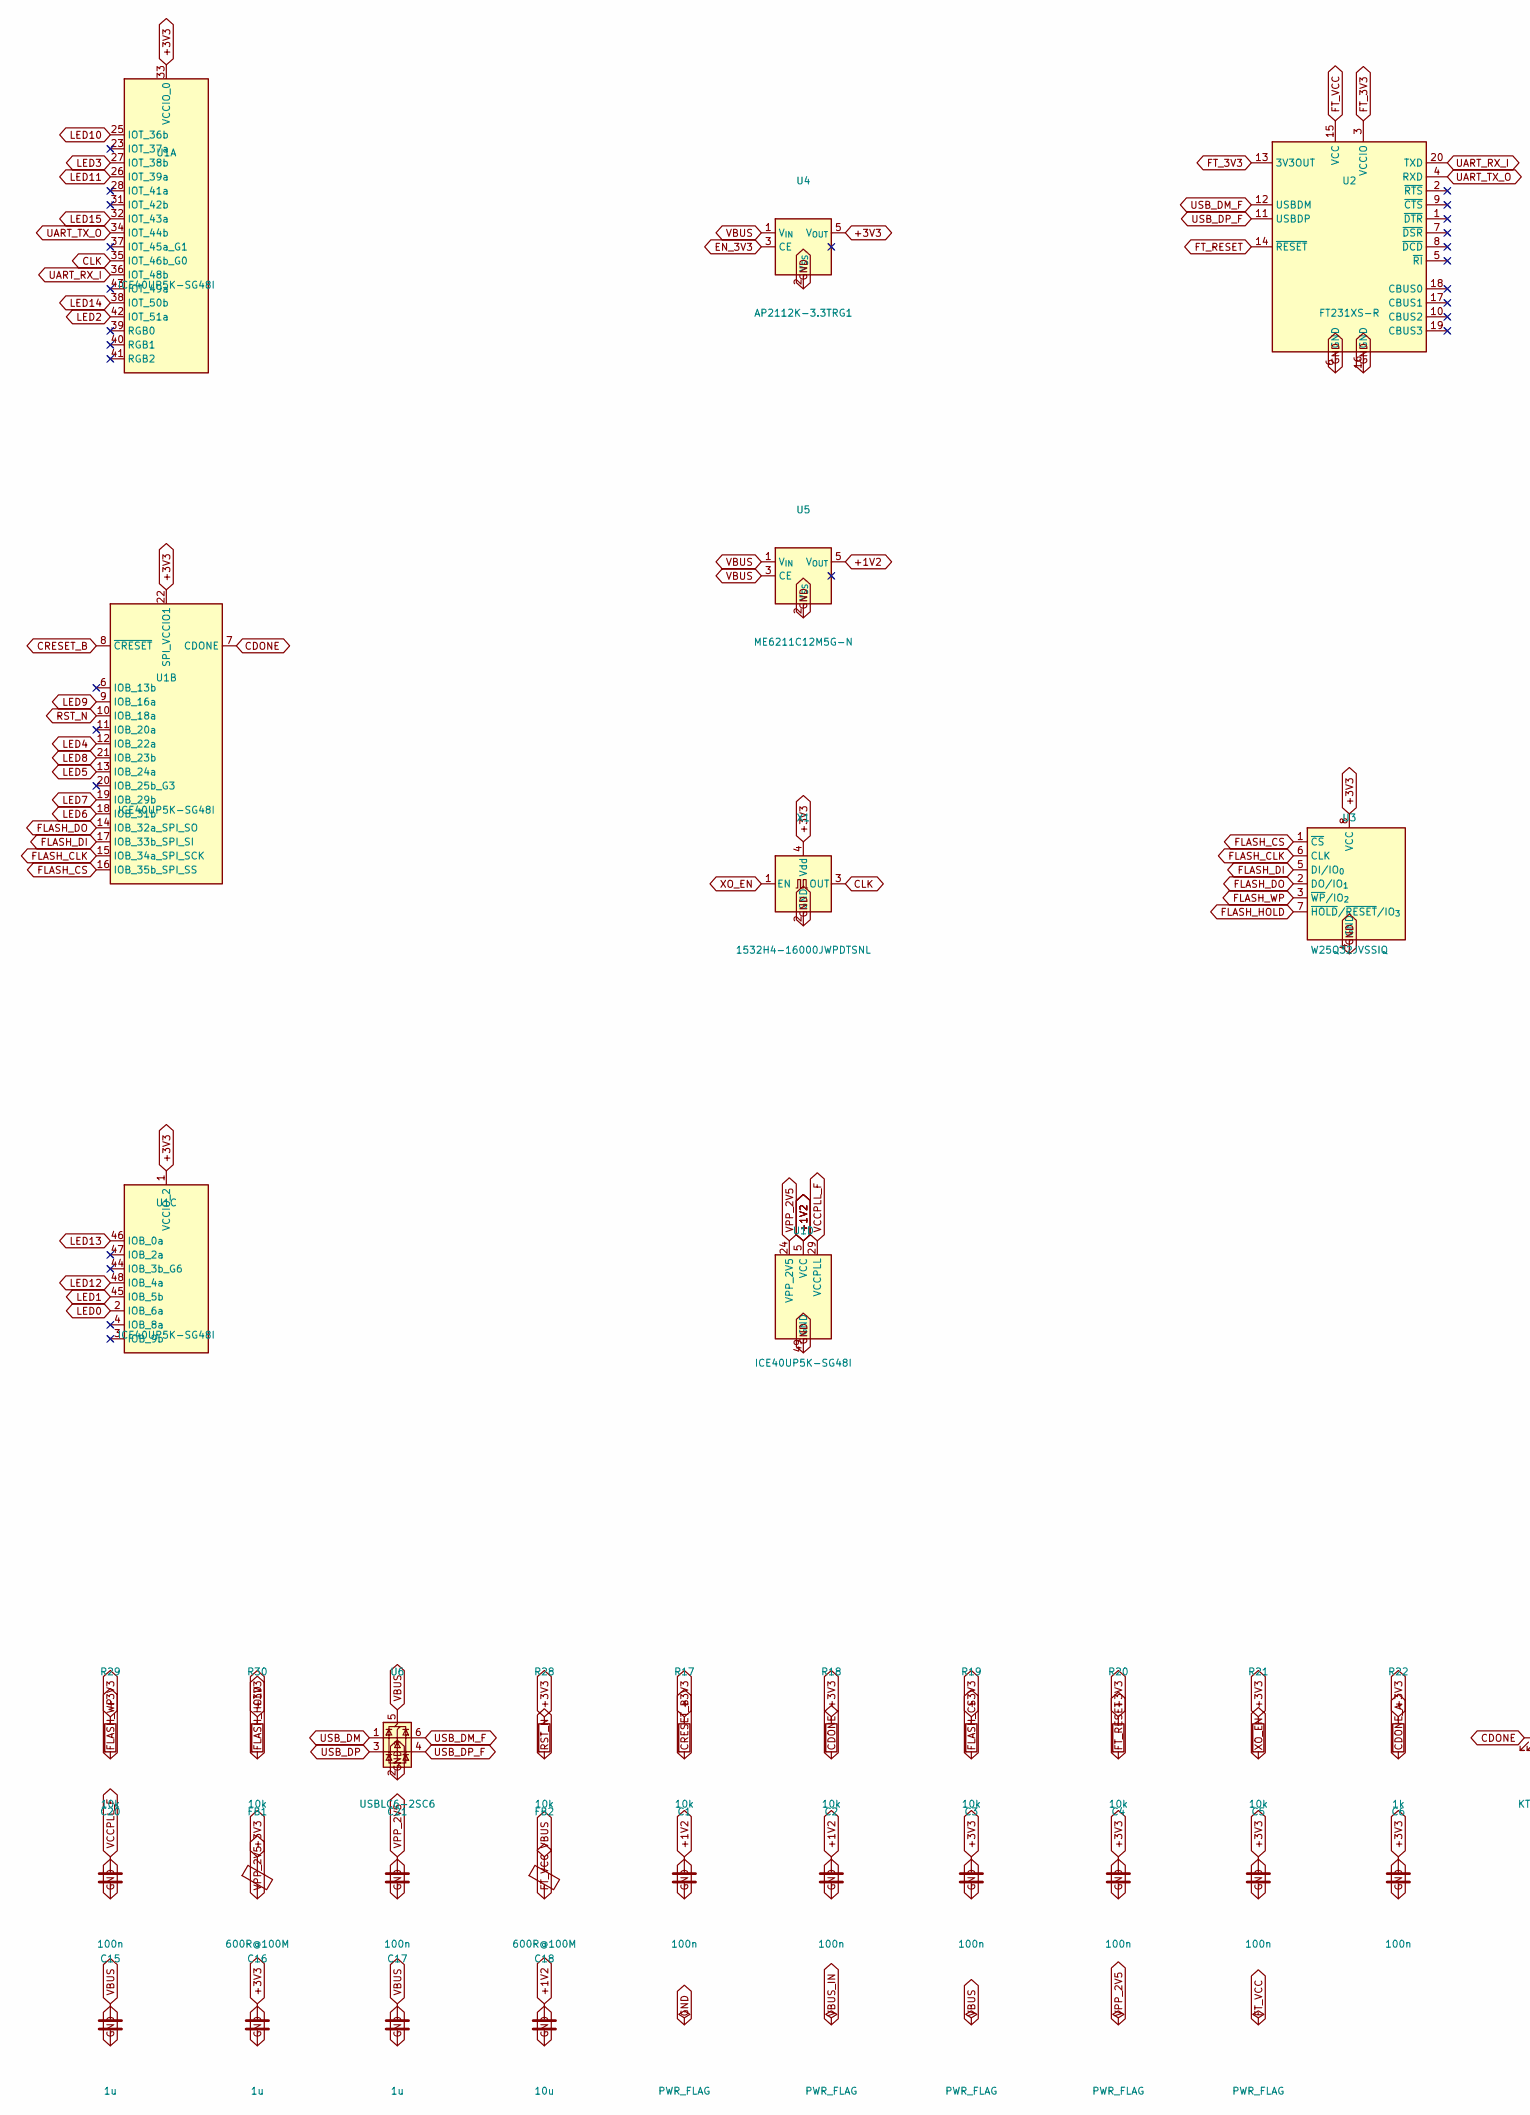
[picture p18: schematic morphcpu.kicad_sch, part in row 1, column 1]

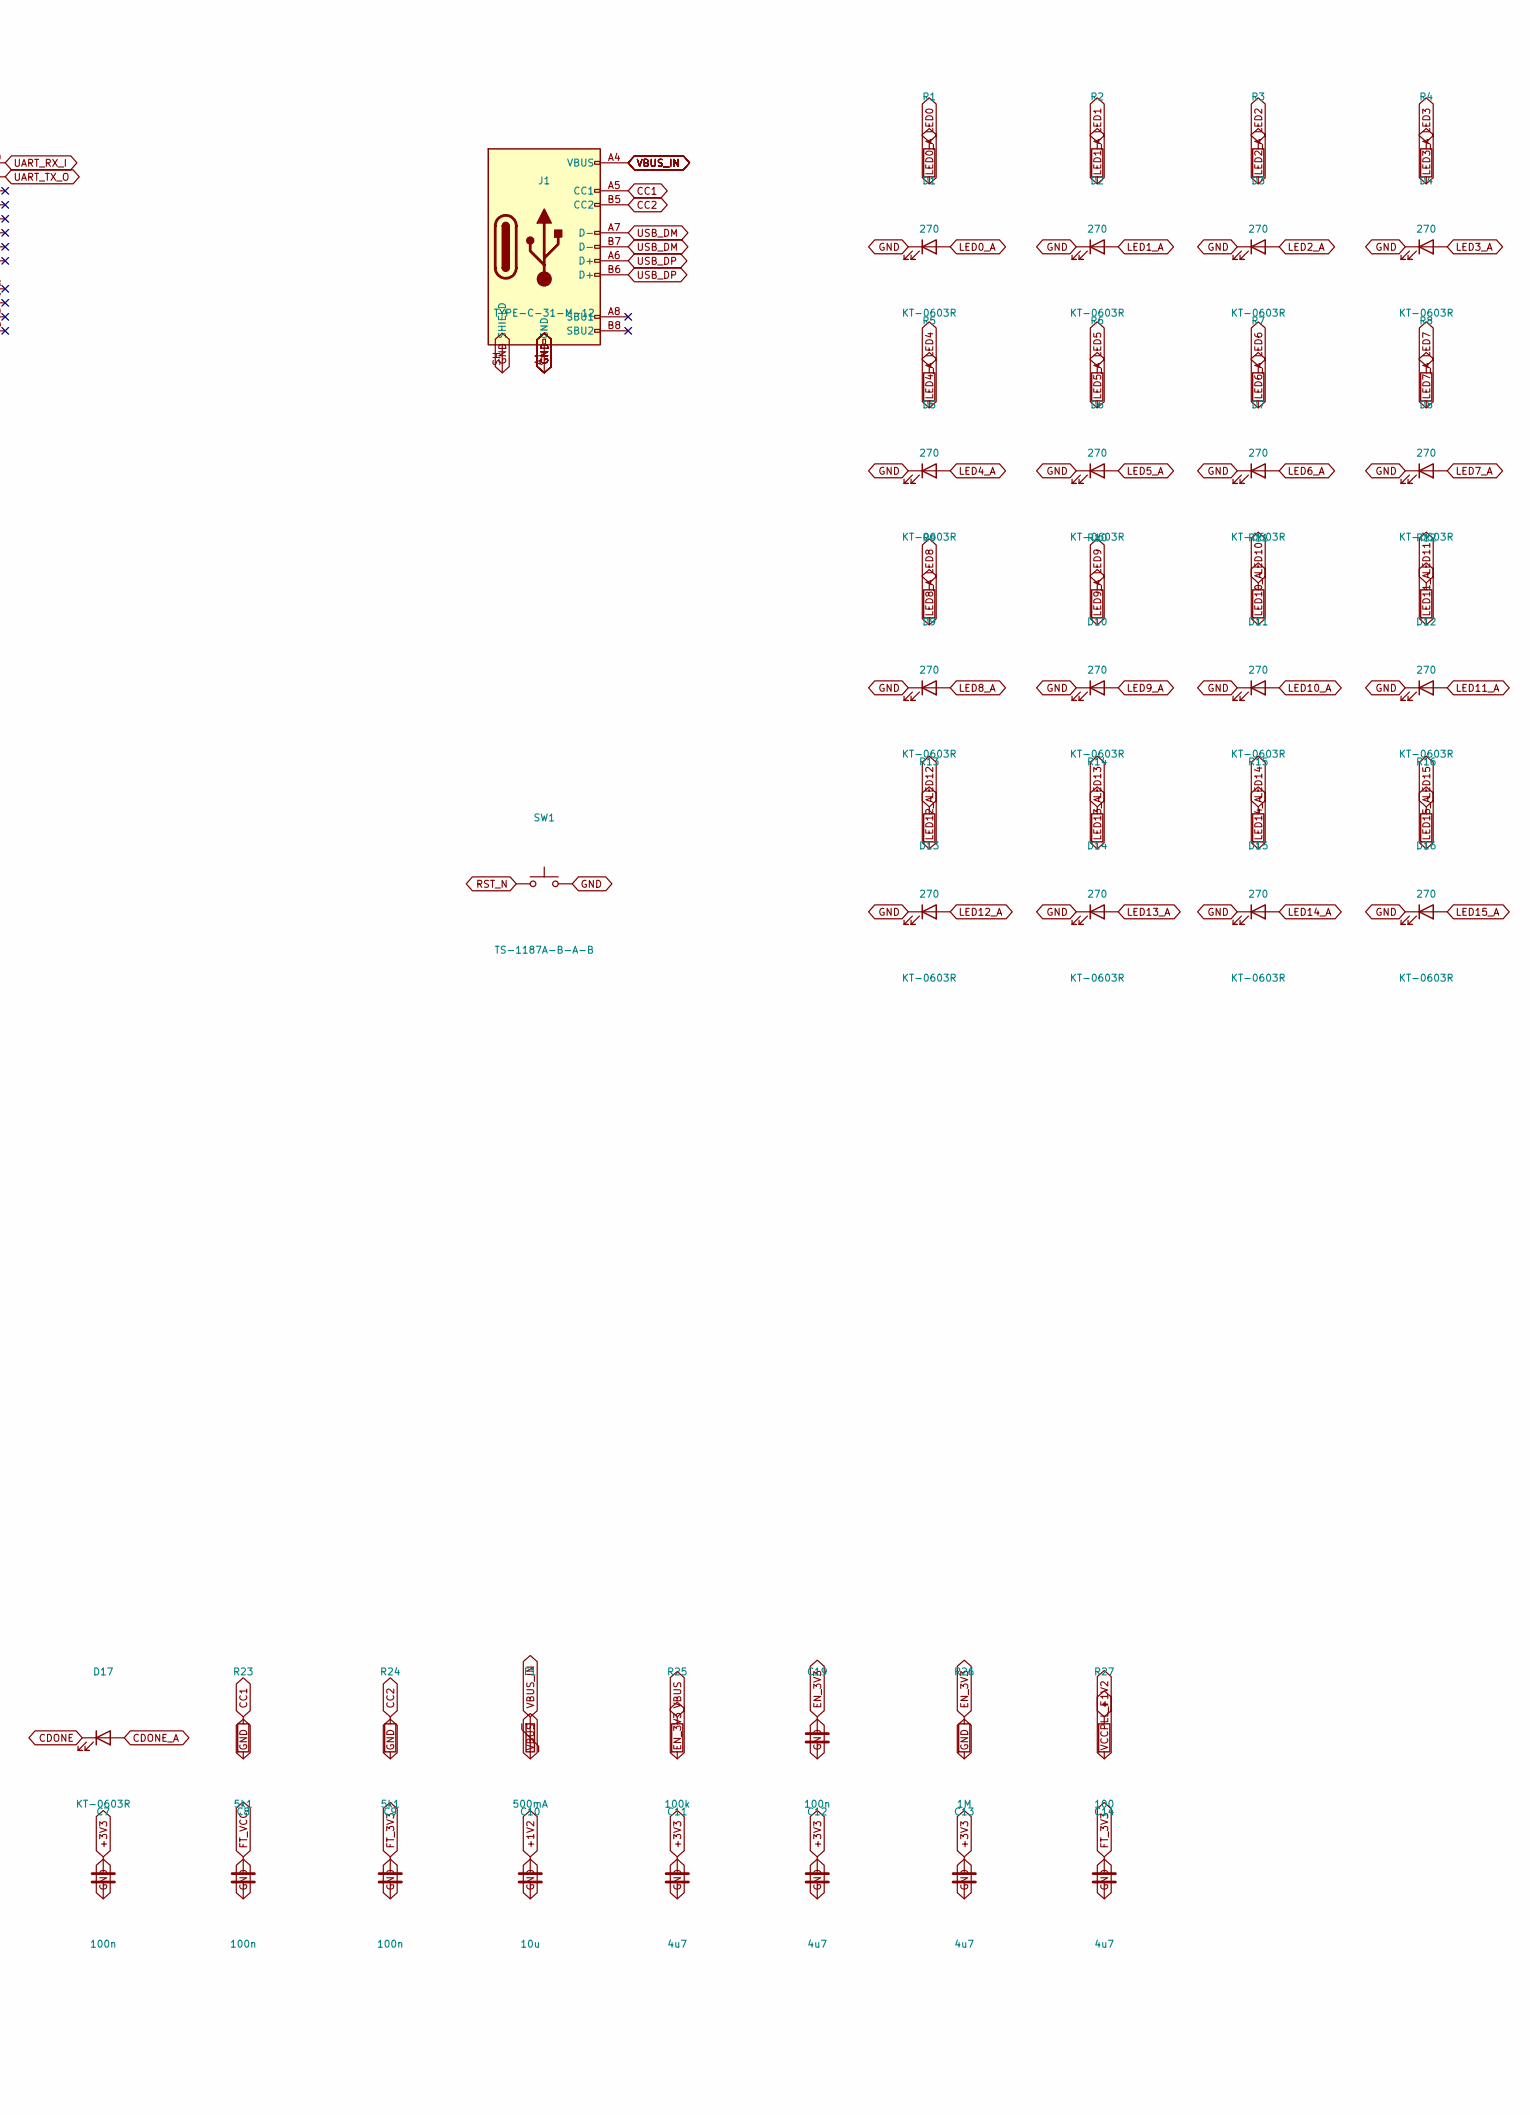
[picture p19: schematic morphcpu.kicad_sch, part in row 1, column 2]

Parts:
C1, C2, C3, C4, C5, C6, C7, C8, C9, C19, C20, C21: 100n; C_0402_1005Metric
C10, C18: 10u; C_0402_1005Metric
C11, C12, C13, C14: 4u7; C_0402_1005Metric
C15, C16, C17: 1u; C_0402_1005Metric
D1, D2, D3, D4, D5, D6, D7, D8, D9, D10, D11, D12, D13, D14, D15, D16, D17: KT-0603R; LED_0603_1608Metric
F1: 500mA; Fuse_1206_3216Metric
FB1, FB2: 600R@100M; L_0603_1608Metric
J1: TYPE-C-31-M-12; USB_C_Receptacle_HRO_TYPE-C-31-M-12
R1, R2, R3, R4, R5, R6, R7, R8, R9, R10, R11, R12, R13, R14, R15, R16: 270; R_0402_1005Metric
R17, R18, R19, R20, R21, R28, R29, R30: 10k; R_0402_1005Metric
R22: 1k; R_0402_1005Metric
R23, R24: 5k1; R_0402_1005Metric
R25: 100k; R_0402_1005Metric
R26: 1M; R_0402_1005Metric
R27: 100; R_0402_1005Metric
SW1: TS-1187A-B-A-B; SW_Push_1P1T_XKB_TS-1187A
U1: ICE40UP5K-SG48I; QFN-48-1EP_7x7mm_P0.5mm_EP5.6x5.6mm
U2: FT231XS-R; SSOP-20_3.9x8.7mm_P0.635mm
U3: W25Q32JVSSIQ; SOIC-8_5.3x5.3mm_P1.27mm
U4: AP2112K-3.3TRG1; SOT-23-5
U5: ME6211C12M5G-N; SOT-23-5
U6: USBLC6-2SC6; SOT-23-6
X1: 1532H4-16000JWPDTSNL; Oscillator_SMD_Abracon_ASE-4Pin_3.2x2.5mm

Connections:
+1V2: C1.1, C2.1, C10.1, C18.1, R27.1, U1.5 (VCC), U1.30 (VCC), U5.5 (V_{OUT})
+3V3: C3.1, C4.1, C5.1, C6.1, C7.1, C11.1, C12.1, C13.1, C16.1, FB1.1, R17.1, R18.1, R19.1, R20.1, R21.1, R22.1, R28.1, R29.1, R30.1, U1.1 (VCCIO_2), U1.22 (SPI_VCCIO1), U1.33 (VCCIO_0), U3.8 (VCC), U4.5 (V_{OUT}), X1.4 (Vdd)
CC1: J1.A5 (CC1), R23.1
CC2: J1.B5 (CC2), R24.1
CDONE: D17.1 (K), R18.2, U1.7 (CDONE)
CDONE_A: D17.2 (A), R22.2
CLK: U1.35 (IOT_46b_G0), X1.3 (OUT)
CRESET_B: R17.2, U1.8 (~CRESET)
EN_3V3: C19.1, R25.2, R26.1, U4.3 (CE)
FLASH_CLK: U1.15 (IOB_34a_SPI_SCK), U3.6 (CLK)
FLASH_CS: R19.2, U1.16 (IOB_35b_SPI_SS), U3.1 (~CS)
FLASH_DI: U1.17 (IOB_33b_SPI_SI), U3.5 (DI/IO_{0})
FLASH_DO: U1.14 (IOB_32a_SPI_SO), U3.2 (DO/IO_{1})
FLASH_HOLD: R30.2, U3.7 (~HOLD/~RESET/IO_{3})
FLASH_WP: R29.2, U3.3 (~WP/IO_{2})
FT_3V3: C9.1, C14.1, U2.3 (VCCIO), U2.13 (3V3OUT)
FT_RESET: R20.2, U2.14 (~RESET)
FT_VCC: C8.1, FB2.2, U2.15 (VCC)
GND: C1.2, C2.2, C3.2, C4.2, C5.2, C6.2, C7.2, C8.2, C9.2, C10.2, C11.2, C12.2, C13.2, C14.2, C15.2, C16.2, C17.2, C18.2, C19.2, C20.2, C21.2, D1.1 (K), D2.1 (K), D3.1 (K), D4.1 (K), D5.1 (K), D6.1 (K), D7.1 (K), D8.1 (K), D9.1 (K), D10.1 (K), D11.1 (K), D12.1 (K), D13.1 (K), D14.1 (K), D15.1 (K), D16.1 (K), J1.A1 (GND), J1.A12 (GND), J1.B1 (GND), J1.B12 (GND), J1.SH (SHIELD), R23.2, R24.2, R26.2, SW1.2, U1.49 (GND), U2.6 (GND), U2.16 (GND), U3.4 (GND), U4.2 (V_{SS}), U5.2 (V_{SS}), U6.2 (GND), X1.2 (GND)
LED0: R1.1, U1.2 (IOB_6a)
LED0_A: D1.2 (A), R1.2
LED1: R2.1, U1.45 (IOB_5b)
LED1_A: D2.2 (A), R2.2
LED2: R3.1, U1.42 (IOT_51a)
LED2_A: D3.2 (A), R3.2
LED3: R4.1, U1.27 (IOT_38b)
LED3_A: D4.2 (A), R4.2
LED4: R5.1, U1.12 (IOB_22a)
LED4_A: D5.2 (A), R5.2
LED5: R6.1, U1.13 (IOB_24a)
LED5_A: D6.2 (A), R6.2
LED6: R7.1, U1.18 (IOB_31b)
LED6_A: D7.2 (A), R7.2
LED7: R8.1, U1.19 (IOB_29b)
LED7_A: D8.2 (A), R8.2
LED8: R9.1, U1.21 (IOB_23b)
LED8_A: D9.2 (A), R9.2
LED9: R10.1, U1.9 (IOB_16a)
LED9_A: D10.2 (A), R10.2
LED10: R11.1, U1.25 (IOT_36b)
LED10_A: D11.2 (A), R11.2
LED11: R12.1, U1.26 (IOT_39a)
LED11_A: D12.2 (A), R12.2
LED12: R13.1, U1.48 (IOB_4a)
LED12_A: D13.2 (A), R13.2
LED13: R14.1, U1.46 (IOB_0a)
LED13_A: D14.2 (A), R14.2
LED14: R15.1, U1.38 (IOT_50b)
LED14_A: D15.2 (A), R15.2
LED15: R16.1, U1.32 (IOT_43a)
LED15_A: D16.2 (A), R16.2
RST_N: R28.2, SW1.1, U1.10 (IOB_18a)
UART_RX_I: U1.36 (IOT_48b), U2.20 (TXD)
UART_TX_O: U1.34 (IOT_44b), U2.4 (RXD)
USB_DM: J1.A7 (D-), J1.B7 (D-), U6.1 (I/O1)
USB_DM_F: U2.12 (USBDM), U6.6 (I/O1)
USB_DP: J1.A6 (D+), J1.B6 (D+), U6.3 (I/O2)
USB_DP_F: U2.11 (USBDP), U6.4 (I/O2)
VBUS: C15.1, C17.1, F1.2, FB2.1, R25.1, U4.1 (V_{IN}), U5.1 (V_{IN}), U5.3 (CE), U6.5 (VBUS)
VBUS_IN: F1.1, J1.A4 (VBUS), J1.A9 (VBUS), J1.B4 (VBUS), J1.B9 (VBUS)
VCCPLL_F: C20.1, R27.2, U1.29 (VCCPLL)
VPP_2V5: C21.1, FB1.2, U1.24 (VPP_2V5)
XO_EN: R21.2, X1.1 (EN)

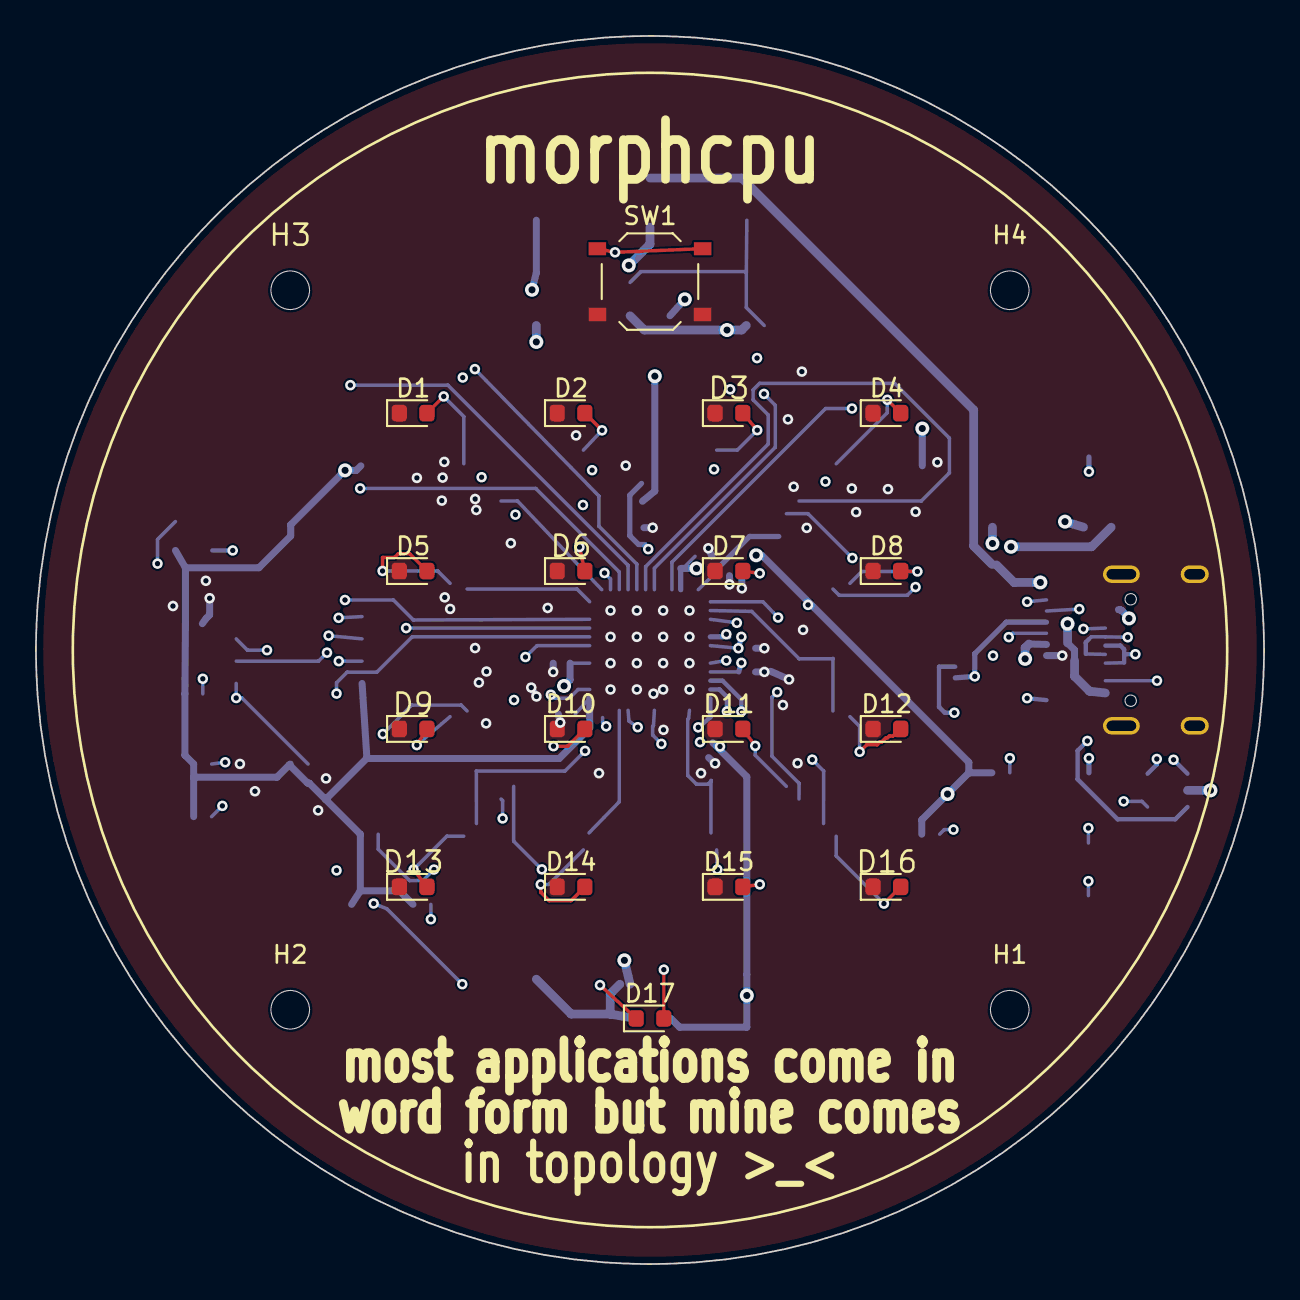
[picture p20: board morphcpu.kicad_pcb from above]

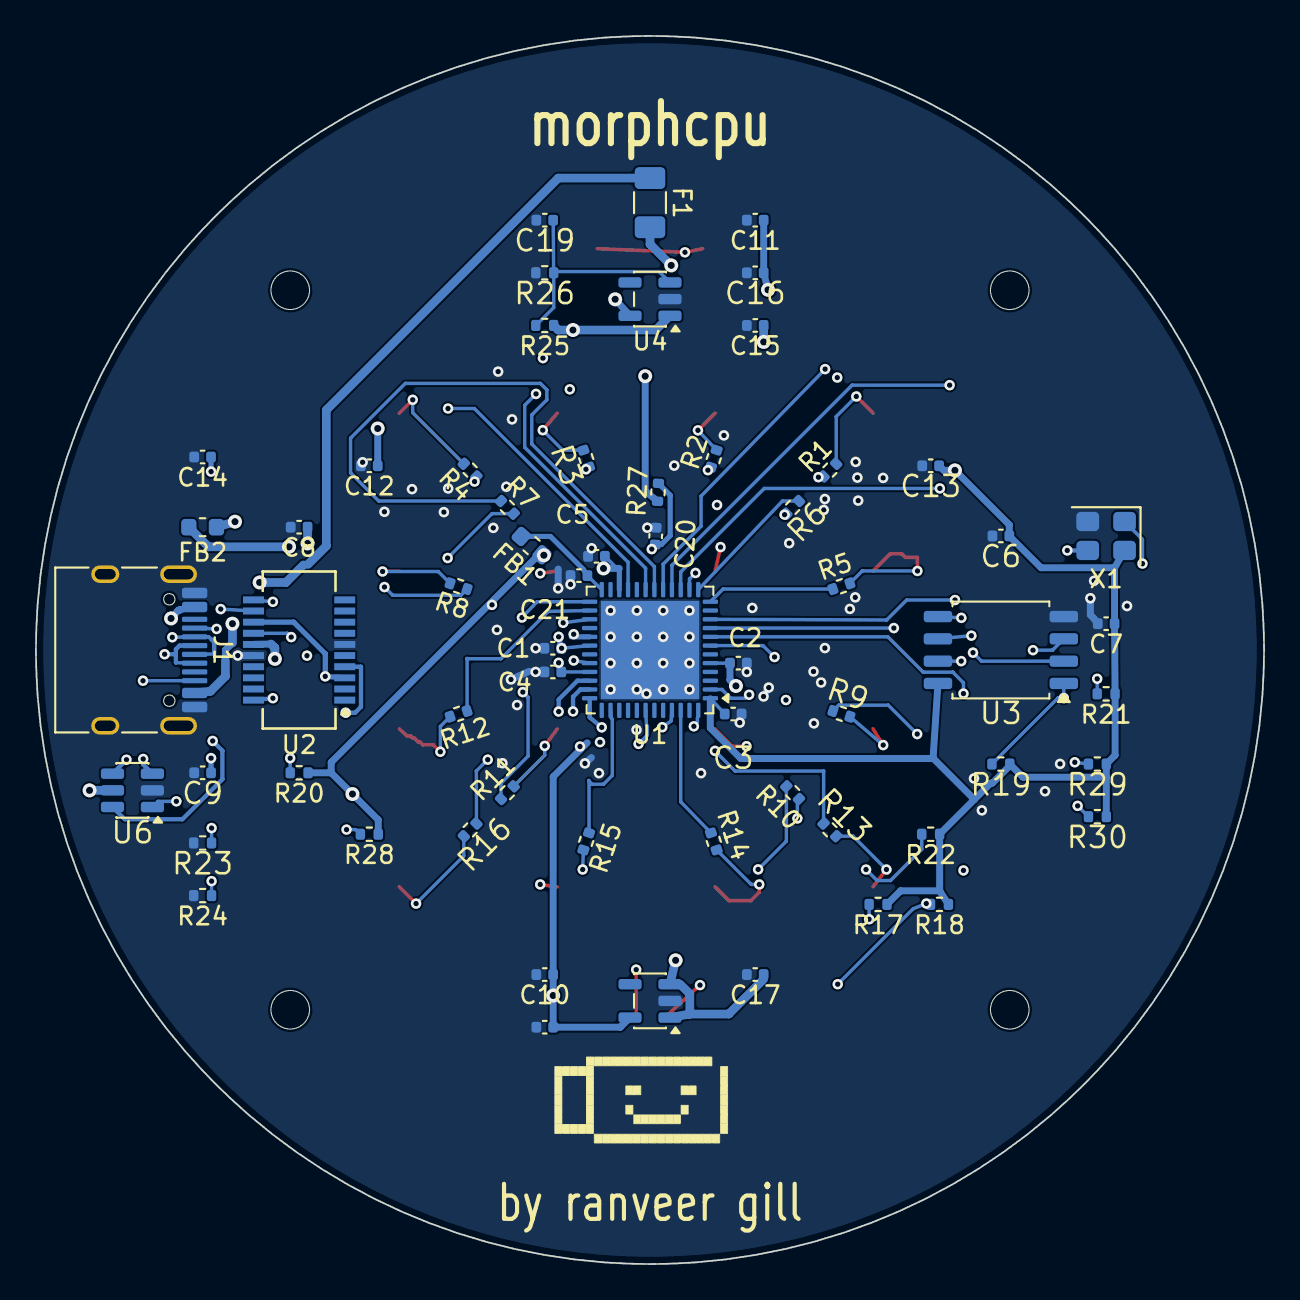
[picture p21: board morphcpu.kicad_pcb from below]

Board: 4 copper layers, 70.0 x 70.0 mm, 84 parts (62 on the bottom side), 63 nets.

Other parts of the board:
H1, H2, H3, H4: M2; MountingHole_2.2mm_M2

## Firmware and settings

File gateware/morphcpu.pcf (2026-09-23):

set_io -nowarn clk        35

set_io -nowarn rst_n      10

set_io -nowarn uart_tx_o  34
set_io -nowarn uart_rx_i  36

set_io -nowarn led[0]      2
set_io -nowarn led[1]     45
set_io -nowarn led[2]     42
set_io -nowarn led[3]     27
set_io -nowarn led[4]     12
set_io -nowarn led[5]     13
set_io -nowarn led[6]     18
set_io -nowarn led[7]     19
set_io -nowarn led[8]     21
set_io -nowarn led[9]      9
set_io -nowarn led[10]    25
set_io -nowarn led[11]    26
set_io -nowarn led[12]    48
set_io -nowarn led[13]    46
set_io -nowarn led[14]    38
set_io -nowarn led[15]    32

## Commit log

2026-08-18 scaffold
    set the repo up:
    - folder structure, gateware/ (+sim), hardware/, case/, docs/ (+img), each with
    a README saying what goes in it
    - README.md, concept writeup, architecture table, toolchain, status section
    - JOURNAL.md, running time total plus a session-entry template covering
    decisions, part numbers, datasheet sources and dead ends
    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
2026-08-19 uart tb / build flow
    - sim/tb_morphcpu_top.v drives the design only thru the UART pins, so it
    validates the wire protocol and config bit packing as well as the fabric.
    5/5 passing. loads a topology with CONFIG, walks it with STEP, decodes the
    result byte off the TX pin.
    - sim/run_sims.sh runs both testbenches, non-zero exit on failure.
    - build.sh, yosys -> nextpnr-ice40 -> icepack for up5k/sg48, greps the nextpnr
    log for utilisation and Fmax to paste into the journal.
    - morphcpu.pcf, pin constraints. marked clearly as a CANDIDATE mapping, the
    numbers still have to be checked against the SG48 pinout and made to agree
    with the schematic before layout.
    - README.md, cell se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
    [morphcpu.pcf]
2026-08-19 case scad
    - morphcpu_case.scad, slim open-face frame. no lid and no light pipe, the LED
    grid is the demo so the face is left completely open and the frame just wraps
    the board edge, lifts it off the desk and takes the USB-C strain. 65.4 mm OD,
    7.8 mm tall, four standoff posts, USB-C cutout with an outer relief for the
    plug boot, eight floor vents.
    - exports manifold, genus 12 (4 screw holes + 8 vents).
    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
    [morphcpu_case.3mf, morphcpu_case.scad, morphcpu_case.stl]
2026-08-19 design spec / bom
    hardware/DESIGN.md, the engineering that has to be settled before a schematic
    is worth drawing. power tree, net-by-net connections, decoupling per pin group,
    PCB brief, JLCPCB assembly notes, and the datasheet items still open.
    two findings that change the parts list.
    there was no power supply in the brief. USB-C gives 5 V, the UP5K needs 1.2 V
    core and 3.3 V I/O and cant run from 5 V. added a 3.3 V LDO and a 1.2 V LDO fed
    from 3.3 V, not 5 V, far less dissipated.
    a bare 12 MHz crystal will not work. the iCE40 has no crystal amplifier, only
    on-chip SB_HFOSC/SB_LFOSC, and exposes no XIN/XOUT. the internal oscillator is
    abt +/-10% which wont hold 115200 baud. s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
2026-08-20 16 MHz osc
    oscillator decision taken: 1532H4-16000JWPDTSNL (LCSC C5383161), a 16 MHz
    active XO, 1.8-3.3 V HCMOS, SMD3225-4P, tri-state enable on pad 1. $0.36 with
    147 in stock, against 9 units for the best 12 MHz part and 1 for the TCXO.
    clock change applied end to end:
    - CLK_HZ 12_000_000 -> 16_000_000 in morphcpu_top, uart_rx, uart_tx
    - DEFAULT_TICKDIV 3,000,000 -> 4,000,000 to hold the fabric tick at 4 Hz
    - tb_morphcpu_top clock half-period 41.667 ns -> 31.25 ns
    - build.sh --freq 16
    - UART divisor is 139 now (0.08% error), better than 12 MHz gave (104, 0.16%)
    both testbenches still pass, 18/18.
    morphcpu.pcf is no longer a candidate mapping, its locked to the verified SG48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
    [morphcpu.pcf]
2026-08-23 schematic
    schematic capture done. 87 component instances, 90 nets, 257 pins wired, 29
    explicit no-connects.
    ERC output, kicad-cli 10.0.5, --severity-all:
    ERC report (2026-08-22T22:26:53, Encoding UTF8)
    Report includes: Errors, Warnings, Exclusions
    ***** Sheet /
    ** ERC messages: 0 Errors 0 Warnings 0
    exit code 0 with --exit-code-violations. netlist exports with no annotation
    warnings.
    the schematic is generated from hardware/scripts/netlist.py which is a direct
    transcription of the DESIGN.md connection tables, no nets improvised.
    connectivity uses global labels rather than drawn wires, a label joins nets by
    name so theres no way to produce a wire tha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
    [morphcpu.kicad_sch]
2026-08-23 pcb placement
    board placement done. 79 footprints, 90 nets, **0 tracks**, routing is
    deliberately left for manual work.
    DRC, kicad-cli 10.0.5 --severity-all:
    163 [unconnected_items] expected, nothing is routed
    2 [silk_overlap] cosmetic reference text
    1 [silk_over_copper] cosmetic
    0 courtyard overlaps
    0 shorting pads
    0 clearance violations
    generated thru the pcbnew Python API rather than by writing board
    s-expressions, so footprint geometry, flipping to the back side and net
    assignment all use KiCad's own code. nets come from the schematic's exported
    netlist, making this the same operation as "Update PCB from Schematic".
    layou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
    [morphcpu.kicad_pcb, morphcpu_case.3mf, morphcpu_case.scad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]
2026-08-24 fab package
    adds hardware/scripts/gen_fab.py which drives kicad-cli to plot the seven
    layers JLC needs plus separate PTH/NPTH Excellon drill, then rewrites KiCad's
    BOM and position exports into JLC's expected column sets. the gerber zip is
    what JLC's uploader takes directly.
    routing is still incomplete, doesnt affect a quote, which reads size, layer
    count and placement only. board comes out as the intended 70 mm round 2-layer
    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
    [morphcpu-bom.csv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]
2026-08-24 esd array
    fixes every discrepancy between docs/BOM.md and the netlist, then pins an LCSC
    part number to all 22 BOM rows so a full PCBA quote is possible.
    ESD protection. BOM.md and the power tree in DESIGN.md both listed an ESD array
    from the start, the schematic never had one. U6 is a USBLC6-2SC6 (C7519,
    SOT-23-6) wired into the D+/D- path between J1 and U2. each protected line gets
    its own net name either side of the part, USB_DP/USB_DP_F and USB_DM/USB_DM_F,
    so the trace routes thru the clamp rather than stubbing off it. placed beside
    the connector on the back, the U2-J1 centre line is a 1.2 mm gap, too narrow
    for SOT-23-6, and the front is the LED display.
    reset switch. the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
    [morphcpu-bom.csv, morphcpu.kicad_pcb, morphcpu.kicad_sch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]
2026-08-24 filament cost
    replaces the "~15 g, negligible" placeholder with a measured number.
    re-exported case/morphcpu_case.stl from the .scad (byte-identical to the
    committed file) and computed its volume by signed-tetrahedron sum over all
    9,586 facets: 11,627.47 mm^3, split into floor 8,707.51, wall ring 2,711.66 and
    standoff posts 208.30 by intersecting the frame with each region.
    at the print settings case/README.md already specifies (0.4 mm nozzle, 3
    perimeters, 0.2 mm layers) the 2.4 mm wall and the 5.0 mm posts are entirely
    perimeter and print solid, only the 2.0 mm floor has an infill region, at 84%
    density. extruded volume 10,410.40 mm^3, 12.91 g at 1.24 g/cm^3, $0.26 at
    $19.99/k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
2026-08-25 net classes
    net classes + DRC rules + a route order. no copper placed, no part moved.
    board is still 84 footprints / 0 tracks / 0 zones, same 3 cosmetic silk
    violations and 167 unconnected pads as before.
    net classes, 10 of them: PWR_5V 0.5mm, PWR_3V3 and PWR_1V2 and GND 0.4mm,
    PWR_FILT 0.3mm, CLK and USB and UART 0.25mm, SPI_FLASH and Default 0.2mm.
    all 63 real nets resolve, nothing fell thru to Default that shouldnt.
    widths are checked against IPC-2221 external, not guessed, and the finding
    is that nothing here is current-limited. VBUS at the 500mA fuse only needs
    0.115mm. 0.5mm is for margin and legibility, said so in ROUTING.md.
    DRC: min track/clearance 0.1524mm (6 mil per D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
2026-08-25 resistor ring pairing
    still 0 tracks and 0 zones. both fixes are in the generators, not hand edits.
    LED anode ratsnest 405.0 mm -> 53.4 mm.
    total anode ratsnest 405.0 mm -> 53.4 mm
    longest single anode 31.7 (LED15_A) -> 5.21 (LED5_A, LED9_A)
    shortest 17.7 mm -> 1.49 mm
    chords within 5mm of centre 16 -> 0
    closest approach to centre 0.13 mm -> 5.83 mm
    gen_pcb.py sorted the LEDs by angle correctly then handed out ring slots at
    k*22.5 starting from zero. the sorted list starts at -161.6 deg, so every
    resistor landed 157-180 deg from its own LED and all 16 anodes ran as chords
    under the QFN paddle. the sort was never the pro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
    [morphcpu.kicad_pcb, morphcpu.kicad_sch]
2026-08-25 freerouting attempt
    reporting the real state, no cleanup applied. 865 track objects imported.
    Java 25 (Temurin 25.0.4.1 LTS) unpacked to C:\Users\ranve\tools, freerouting
    2.3.0 jar alongside it. winget install of Temurin 21 failed (MSI needs
    elevation, UAC cancelled, exit 1602) and 21 was the wrong version anyway,
    freerouting 2.3.0 is class file 69 so it needs Java 25. unpacked the Adoptium
    zip instead, no admin needed, nothing added to PATH.
    router ran 32 passes in 8m10s then stalled, best score 877.18 unchanged since
    pass #22. optimizer gave up after one pass at 0.0000% improvement.
    DRC:
    track_width 8 0.150 mm tracks against the 0.1524 mm minimum
    annular_width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
    [morphcpu.kicad_pcb]
2026-08-25 autoroute revert
    board back to 0 tracks 0 zones. freerouting didnt come back clean and the front
    face was a mess, so its out. kept the DSN, the SES and the renders, wrote up
    what happened in ROUTING.md.
    DRC after: 1 cosmetic silk, 167 unconnected. ERC 0/0. generators run, tests pass.
    also went over every .md .py .sh .v .pcf .scad. contractions, unicode arrows to
    ascii, comment divider scaffolding out. no number or part number or path
    changed, tables left alone, $display and RESULT:/PASS: strings untouched cause
    run_sims.sh reads them.
    [morphcpu.kicad_pcb, morphcpu_case.scad]
2026-08-26 docs pass / stale ns comment
    morphcpu_top.v said 83 ns a hop, thats the 12 MHz period. 62.5 at 16.
    pcf and the DESIGN.md pin table already agreed, all 20, so the checklist item
    saying to update the pcf was stale. same for the UART move item.
    80 footprints was wrong too, file has 84. 80 parts + 4 mounting holes.
    rest is prose. readmes were doing too much explaining.
    [morphcpu_case.scad]
2026-08-27 freerouting pass 2: paddle vias, F.Cu keepout, GND pours
    front face is clean now. that was the point and it worked. the rest is worse
    than pass 1 and the board still does not route.
    manual work first, both locked so the router could not move them:
    paddle via field 4x4, 1.5 mm pitch, 0.6/0.3 mm, on GND, centred on U1-49.
    pad edges land 0.25 mm inside the 5.6 mm paddle. exported
    into the DSN as (type fix), all 16 came back untouched.
    F.Cu keepout rule area LED_GRID_F_CU_NO_TRACKS, 134-166 x 85-115 mm,
    F.Cu only. tracks disallowed, vias and pads and zone fills
    all still allowed so the pour still co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
2026-08-27 4 layers / board routes now
    2 layers was the problem, not the router. the resistor ring sits at r 11-15 and
    the decap ring at r 6-7, both inside the F.Cu keepout, so all 16 LED escapes
    plus every supply converging on U1 had exactly one layer to share. seven
    freerouting configs, a maze router, a rip-up loop and a pathfinder
    implementation all bounced off that.
    stackup is F.Cu / In1.Cu / In2.Cu / B.Cu, both inner layers signal. In1 was a
    power plane first and freerouting wont route on a power layer, so it only used
    In2 and came back at 13 unrouted. flipping In1 to signal got it to 11
    DRC 1 violation, the same cosmetic C20/R27 silk overlap thats been there
    since the resistor ring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
    [morphcpu.kicad_pcb]
2026-08-28 route 7 of the 17 outstanding connections, DRC to 0 violations
    Adds 84 segments and 11 vias for seven connections: the GND pour fragments at
    C4.2, C12.2 and C7.2 (C7 also resolves U3.4, same island), plus VCCPLL_F,
    VBUS_IN, LED2 and LED15. Nothing already on the board was moved.
    Every placed segment and via was exact-clearance checked against all foreign
    copper before being committed, and the no-track rule area is honoured as
    outline-minus-holes. VBUS_IN came out at 0.30 mm against its 0.50 mm PWR_5V
    class - still 1.00 A by IPC-2221 against a 500 mA polyfuse, but it drops the
    intended ~2.9x margin to ~2x, so it is worth a look by hand.
    Also moves C20's reference field 1.3 mm in X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
    [morphcpu.kicad_pcb]
2026-08-28 correct ROUTING.md: +3V3 and LED12 are routable, not impossible
    The previous note claimed jobs 9, 10 and 16 could not be routed by adding
    copper at all. That was too strong. A whole-fanout group reroute - rip out
    U1's north row and east column, 17 two-pad nets, and re-solve them together
    with +3V3, +1V2 and LED12 in the mix from the start - places all three.
    What defeats the one-net-at-a-time approach is that the channel assignment
    predates those nets: +3V3 takes U1.22's only slot and LED9 at U1.23 is then
    stranded, identically at every cut radius from 1 mm to 8 mm. The wall is the
    search, not the copper.
    The group run is not kept: it peaked at 15 of 27 placed, leaving 12 unroute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
2026-08-28 route 2 of the 10 outstanding: GND at C21.2 and U2.16
    Both pads sit in a small isolated B.Cu pour island with the main In1/In2/F
    planes running straight underneath, so what they needed was one stitching via
    each, not a route. Neither had a legal through-via site: a via must clear all
    four layers, and the inner layers were covered.
    C21.2 had four free sites all along - the earlier search missed them because
    the 0.05 mm raster marks a cell blocked when its centre falls inside the
    inflated obstacle, which is up to half a cell pessimistic. The router now
    rasterises half a cell optimistic and lets exact pcbnew clearance be the
    authority, vetoing rejected cells and re-routing.
    U2.16 w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
    [morphcpu.kicad_pcb]
2026-08-28 route LED5_A, the last one that did not need the U1 fanout moved
    Falls out standalone now that the router rasterises half a cell optimistic and
    lets exact pcbnew clearance arbitrate. 8 segments and 3 vias, R6.2 on B.Cu up
    to D6.2 on F.Cu.
    0 violations, 8 unconnected -> 0 violations, 7 unconnected.
    [morphcpu.kicad_pcb]
2026-08-29 fanout was full / six leds onto the south row
    U1's east column was carrying twelve nets on twelve 0.5 mm channels and four of
    them land on the far side of the board so they cross the fan twice. +3V3 at 22
    and 33, +1V2 at 5 and 30, and LED12 had no escape at all
    a 0.6 mm via wants 1.2 mm between its neighbours and adjacent escape rays are
    0.5 mm apart, so nothing changes layer until the fan has spread. the staggered
    two row via fanout fails the same way, the outer neck needs 1.2 mm between two
    inner vias and has 1.0 mm. tested that
    pads 37-48 were sitting unused. LED12 27->48, LED13 28->46, LED14 31->38,
    LED2 4->23, LED3 11->27, ordered by their resistors x so none of them cross.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
    [morphcpu.kicad_pcb, morphcpu.kicad_sch]
2026-08-30 led9 onto pin 9 / +1V2 gets out of U1.5
    LED9 went to the south row with LED12/13/14 last commit and then spent its time
    fighting LED12 on pad 48 for the same southwest corridor. R10 is at 141.5, 108.5
    and pad 9's ray on the west face points straight at it, so it goes there and pad
    47 is unused again
    that frees the west corridor and +1V2 at U1.5 routes. pin 5 is a core VCC pin so
    it was the only open connection that actually mattered
    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
    [morphcpu.kicad_pcb, morphcpu.kicad_sch]
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2026-08-30 docs pass / fab_output replotted with the inner layers
    gen_fab.py was still on F.Cu,B.Cu from when this was a 2 layer board, so it was
    plotting a 4 layer design with In1 and In2 missing. that quotes fine and arrives
    dead. In1_Cu.g1 and In2_Cu.g2 are in the zip now, 133 KB and 135 KB of copper,
    and the whole package is off the routed board instead of the unrouted one
    README said not routed 0 tracks. its 770 tracks 148 vias on 4 layers now with 2
    nets open, both leds. renders redone off the routed board, the old ones were
    placement only with no copper in them
    flagged in the README that $198.41 was costed at 2 layers and this is 4, not
    requoted
    ROUTING.md has what blocked each of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
    [morphcpu-cpl.csv]
2026-08-30 3v3 ldo to ap2112k / en bleed 10k to 1m
    C82942 went to 0 stock at JLC, 11 day lead and a 196 MOQ behind it.
    AP2112K-3.3TRG1 C51118 instead, 70,670 in stock, same SOT-23-5 and the same
    1 VIN 2 GND 3 EN 4 NC 5 VOUT so nothing on the board moved. 600mA not 500.
    couldnt get a tier out of JLC's listing, that column reads Extended for every
    row including ones that arent, so its unconfirmed.
    the EN RC was a divider. 100k feed against a 10k bleed put EN at
    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
    [morphcpu-bom.csv, morphcpu.kicad_sch]
2026-08-30 u1 3d model / kicad ships ep5.15 not ep5.6
    the footprint asks for QFN-48-1EP_7x7mm_P0.5mm_EP5.6x5.6mm.step and the library
    hasnt got one, so the fpga was just missing from every 3D export. pointed at
    EP5.15x5.15mm, closest thing thats actually there.
    model path only. BOM and CPL byte identical after, all 12 gerbers identical.
    J1 SW1 and X1 still have no models.
    [morphcpu.kicad_pcb]
2026-08-30 case step out of freecad
    3MF in, Mesh.insert then makeShapeFromMesh with sewing then Part.export.
    closed solid, 75.4 x 75.4 x 7.8mm, 11627.5mm3, 2621 faces. tessellated, those
    faces are welded mesh triangles and not real cylinders, fine for a fit check.
    [morphcpu_case.step]
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2026-08-31 silkscreen / board had none
    only graphic on it was the edge cuts circle. front gets the name as eight
    separate texts round r=29.7 rotated to the tangent cuz kicad has no curved
    text, a frame circle at 32.9, IN and OUT arrows on the side lobes and eight
    boxed direction arrows for what a cell can pick
    back gets the name up top, url and iCE40UP5K SG48 and rev straight in the
    bottom band. no frame circle that side, it crossed J1's outline at 182,95.3
    and 182,104.7
    mirrored arc text needs the run reversed and not just the glyphs, first pass
    read UPCHPROM. first back pass also put the url's c and t into the H3 and H4
    NPTH pads, 4 silk warnings, both gone now
    DRC 0 violations, 2 unconnected, sam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
    [morphcpu.kicad_pcb]
2026-08-31 rev A off the back
    sch_revision is empty and theres no earlier spin, so the board was carrying a
    revision letter that nothing in the project backs. url and iCE40UP5K SG48 stay
    DRC 0 violations, 2 unconnected, unchanged
    [morphcpu.kicad_pcb]
2026-09-02 docs / DESIGN and hardware README still said 0 tracks
    DESIGN.md carried "there is no routing in this repository", a 2 layer stackup
    row, 0 tracks and the old 167-unconnected DRC block. replaced with what the file
    actually holds, 770 segments 148 vias over F.Cu In1.Cu In2.Cu B.Cu, and the real
    0 violations / 2 unconnected paste. hardware/README.md had the same two, 0 tracks
    and 2 layer
    post-routing checklist existed twice, DESIGN.md and ROUTING.md, both drifting.
    DESIGN.md points at ROUTING.md now
    ROUTING.md's "what JLC charges extra for" numbers were all read off the 2 layer
    1 oz page before the board went to 4. left the numbers, said where they came from
    ROUTING.md#10-uart_tx_o-and-uart_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
2026-09-06 bom qty column / seeed wouldnt take it
    [morphcpu-bom.csv]
2026-09-06 bom mpn column / seeed wants real p/ns not lcsc codes
    [morphcpu-bom.csv]
2026-09-06 decoupling caps onto their pins / stitching vias
    the 6.5mm ring in gen_pcb.py placed the seven 100n by refdes order, so which
    cap landed near which supply pin was arbitrary. measured as real copper path
    not straight line, pin 22 was being decoupled by C12 under the FT231X at
    49.31mm and pin 33 at 49.73mm. C4 and C5 were dead end spurs off the west
    +3V3 trunk doing nothing for U1 at all
    C3 -> pin 1 3.23 -> 1.16mm, C5 -> pin 22 49.31 -> 1.98mm, C21 -> pin 24
    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
    [morphcpu.kicad_pcb]
2026-09-06 east face reshuffle / C4 across to pin 33
    pins 29 30 and 33 all escape east and the lane at x 154-157 was full, so none
    of them could have a cap next to them. moved the caps out to x=155.5375 instead
    of hard against the pad row and most of the lane traffic stopped mattering
    C1 -> pin 30, 156.401,101.129 -> 155.5375,99.90, path 3.24 -> 1.47mm
    C4 -> pin 33, 143.743,101.760 -> 155.5375,101.25, path 49.73 -> 1.62mm
    C2 -> pin 5, 153.109,105.708 -> 144.9625,100.75, path 13.77 -> 1.12mm
    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
    [morphcpu.kicad_pcb]
2026-09-06 770 tracks was stale / gerbers regen
    769 tracks 188 vias 1473.5 mm now. same line was in DESIGN.md too
    gerbers and CPL regenerated off the current board, the committed ones predated
    the cap moves. left morphcpu-bom.csv alone, regenerating it drops the Quantity
    and MPN columns bcuz gen_fab.py only asks for Reference,Value,Footprint and
    the Qty doesnt even come through
    [morphcpu-cpl.csv]
2026-09-12 gateware build
    [morphcpu_case.scad]
2026-09-23 2 LEDSS!!!1!!!1!
    [morphcpu-bom.csv, morphcpu.kicad_pcb, morphcpu.kicad_sch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]
2026-09-25 kinda helvetica
    [morphcpu.kicad_pcb]
2026-10-03 cafe architecture -_-
    [morphcpu.kicad_pcb]
